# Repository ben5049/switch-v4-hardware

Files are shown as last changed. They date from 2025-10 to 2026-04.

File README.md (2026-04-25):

# Switch v4 Hardware

KiCad design files for the 4th iteration of my single pair Ethernet (SPE) switch. The firmware can be found in [unified-switch-firmware](https://github.com/ben5049/unified-switch-firmware).

Also see my post on [r/embedded](https://www.reddit.com/r/embedded/comments/1mxale6/i_built_a_single_pair_ethernet_switch/)!

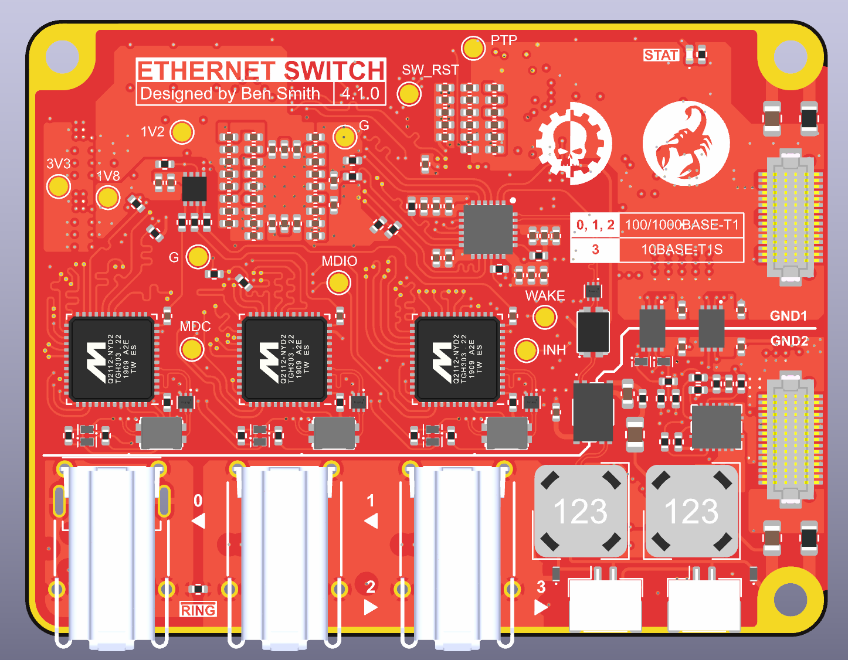
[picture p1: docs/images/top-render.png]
top-render


## Design

See the [schematic](docs/schematics/switch-main-v4.pdf) for a block diagram and in-depth details.

The main switch chip is an [SJA1105QEL](https://www.nxp.com/products/SJA1105PQRS) from NXP. It is configured via SPI by an [STM32H573IIK3Q](https://www.st.com/resource/en/datasheet/stm32h573ai.pdf). The STM32 is also connected by reduced media independent interface (RMII) to the switch so it is able to send and receive management traffic such as Spanning Tree Protocol ([STP](https://en.wikipedia.org/wiki/Spanning_Tree_Protocol)) BPDUs as well as Precision Time Protocol (PTP) packets and diagnostic information.

The connections for each SJA1105 port are shown below:

| Port | Speed (Mbps) | Description |
| ---- | --- | --- |
| 0 | 100/1000 | Marvell 88Q2112 100/1000BASE-T1 Ethernet PHY |
| 1 | 100/1000 | Marvell 88Q2112 100/1000BASE-T1 Ethernet PHY with PoDL |
| 2 | 100/1000 | Marvell 88Q2112 100/1000BASE-T1 Ethernet PHY with PoDL |
| 3 | 10 | Microchip LAN8671 10BASE-T1S Ethernet PHY with PoDL |
| 4 | 100 | Internal STM32 management processor |

### PoDL PSE

Power over Datalines ([PoDL](https://en.wikipedia.org/wiki/Power_over_Ethernet#PoDL)) is similar to Power over Ethernet ([PoE](https://en.wikipedia.org/wiki/Power_over_Ethernet)) but for SPE. In regular PoE power is sent over the center taps of the transformers, however in SPE there is only one (or no) transformer so this wouldn't work. Instead, DC power is injected into the datalines in the Coupling Decoupling Network (CDN) using differential mode inductors (DMI). The switch is only capable of being a Power Sourcing Equipment (PSE) which powers other devices. It must get its own power through the other connectors on the board.

PoDL has been implemented on ports 1, 2 and 3 of the switch.

- Ports 1 and 2 are able to output 1.1A each and use a simple detection method before supplying power to a load. Firstly ~14mA is sent down the cable, then if the bus voltage is between 4.05 and 4.55V then the full supply is enabled (typically 24V). This is usually done by a zener diode on the other end of the cable.

- Port 3 is also able to output 1.1A and uses a custom multidrop PoDL implementation. Detection is done by powering the bus at 6.5V, then each device on the bus draws 1mA for every 1W of power they want. Then the full supply is enabled.

An [STM32H503KBU6](https://www.st.com/resource/en/datasheet/stm32h503eb.pdf) is used as a secondary processor to control the PoDL operations. It talks to the primary processor via UART through an optocoupler. This means the data and power circuits are galvanically isolated.

## Test Rig

The [test rig PCB](pcbs/switch-main-v4-test-rig) is designed so that its pogo pins align directly with the test pads on the bottom of the main switch board. This means a debugger can be connected without needing to include a header on the main board.

## Versions

| Version | Description |
| --- | --- |
| v4.1.1  | Updated to Kicad v10 |
| v4.1.0  | Fixed bugs from first revision |
| v4.0.0  | First release |

See the [errata](docs/errata.md) for details on bugs.

## References

Datasheets:
- [88Q2112 Datasheet](https://www.infineon.com/assets/row/public/documents/10/49/infineon-brightlane-88q2110-88q2112-datasheet-datasheet-en.pdf) (requires an Infineon account)
- [SJA1105 Datasheet](https://www.nxp.com/docs/en/data-sheet/SJA1105PQRS.pdf)
- [LAN8671 Datasheet](https://ww1.microchip.com/downloads/aemDocuments/documents/AIS/ProductDocuments/DataSheets/LAN8670-1-2-Data-Sheet-60001573.pdf)

PoDL:
- [How to Implement an IEEE 802.3cg or 802.3bu-Compliant PoDL PSE](https://www.ti.com/lit/ab/snla395/snla395.pdf?ts=1745823061950) - TI
- [1000BASE-T1 PoDL Reference design](https://www.ti.com/lit/ug/tiduf49/tiduf49.pdf?ts=1746159399261&ref_url=https%253A%252F%252Fwww.google.com%252F) - TI
- [PSE Schematic](https://www.ti.com/lit/df/tidmco4/tidmco4.pdf?ts=1746307249429) - TI
- [IEEE 802.3cg 10BASE-T1L Power over Data Lines Powered Device Design](https://www.ti.com/lit/an/snvaa25a/snvaa25a.pdf?ts=1745871367852) - TI
    - References non-existent inductors :/
- [SINGLE PAIR ETHERNET FILTER DESIGN](https://www.we-online.com/files/pdf1/single_pair_ethernet.pdf) - WE
- [Power Injection Inductors for 10BASE-T1 PoDL](https://www.coilcraft.com/en-us/applications/power-injection-inductors-for-10base-t1-podl/) - Coilcraft
- [10BASE-T1L Converter w/ PoE+PoDL](https://matthewtran.dev/2024/08/10base-t1l-converter/)

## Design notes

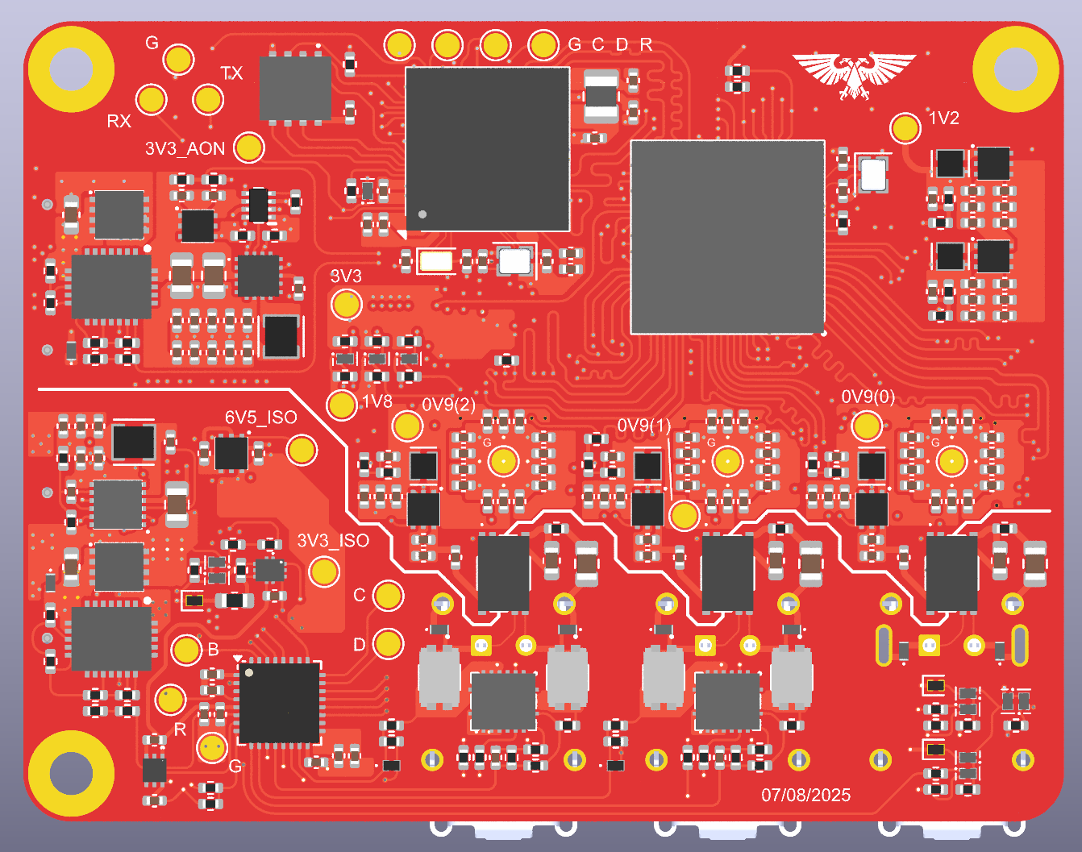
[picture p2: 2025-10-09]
docs/images/bottom-render.png

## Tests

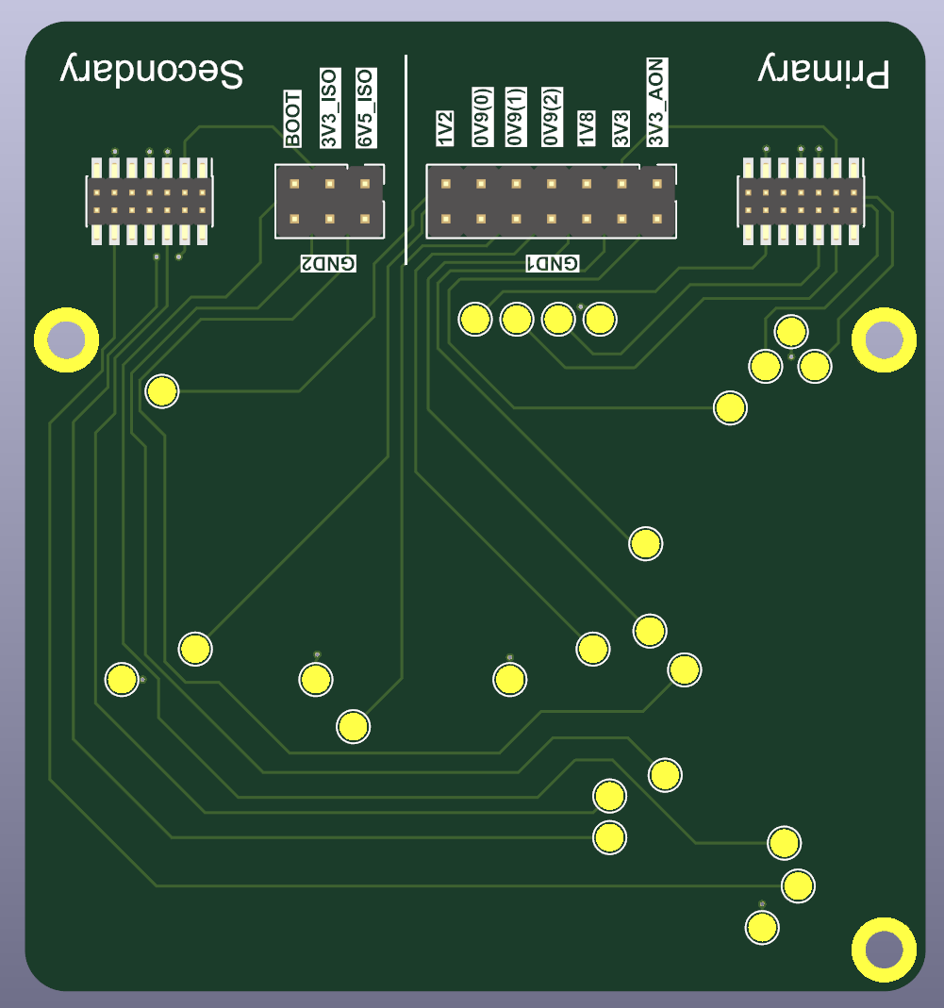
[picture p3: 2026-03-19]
docs/images/test-rig.png

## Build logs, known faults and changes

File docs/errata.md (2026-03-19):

# Switch v4 Errata

## Contents

- [1 Switch v4](#1-switch-v4)
    - [1.1 Primary MCU RMII lanes swapped](#11-primary-mcu-rmii-lanes-swapped)
    - [1.2 88Q2112 Incorrect strapping resistors](#12-88q2112-incorrect-strapping-resistors)

## Key

- A = limitation present, workaround available
- N = limitation present, no workaround available
- P = limitation present, partial workaround available
- "-" = limitation absent

## 1 Switch v4

| **Bug** | **4.0.0** | **4.1.0** |
|---|---|---|
| [Primary MCU RMII lanes swapped](#11-primary-mcu-rmii-lanes-swapped) | A | - |
| [88Q2112 Incorrect strapping resistors](#12-88q2112-incorrect-strapping-resistors) | A | - |

### 1.1 Primary MCU RMII lanes swapped

The primary MCU's RMII TX and RX lanes were accidentally swapped meaning no data could be transmitted or received. This can be fixed by cutting the traces and resoldering them as shown below:

rmii-lane-swap

### 1.2 88Q2112 Incorrect strapping resistors

The 88Q2112 PHYs are missing strapping resistors to put them into RGMII mode and so by default they are in SGMII mode. This can be fixed by adding 4.7k ohm resistores between the PHY's RXC pin and GND. This can be done using the untented vias as shown below:

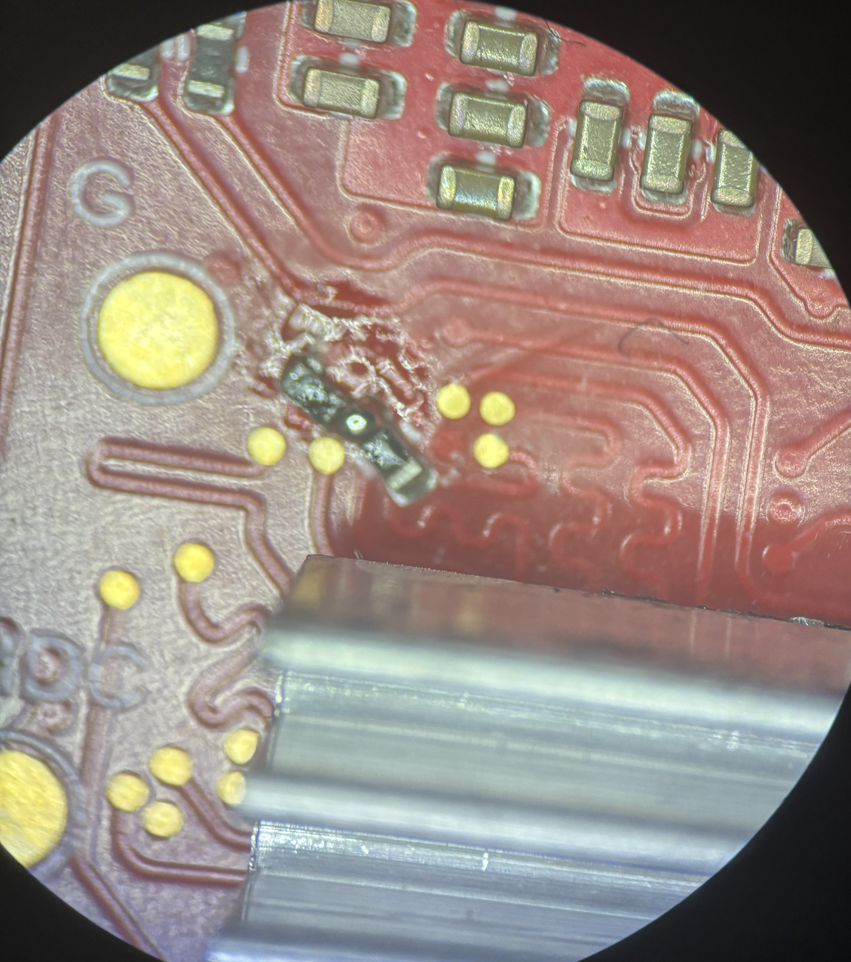
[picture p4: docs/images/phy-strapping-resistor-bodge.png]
phy-strapping-resistor-bodge


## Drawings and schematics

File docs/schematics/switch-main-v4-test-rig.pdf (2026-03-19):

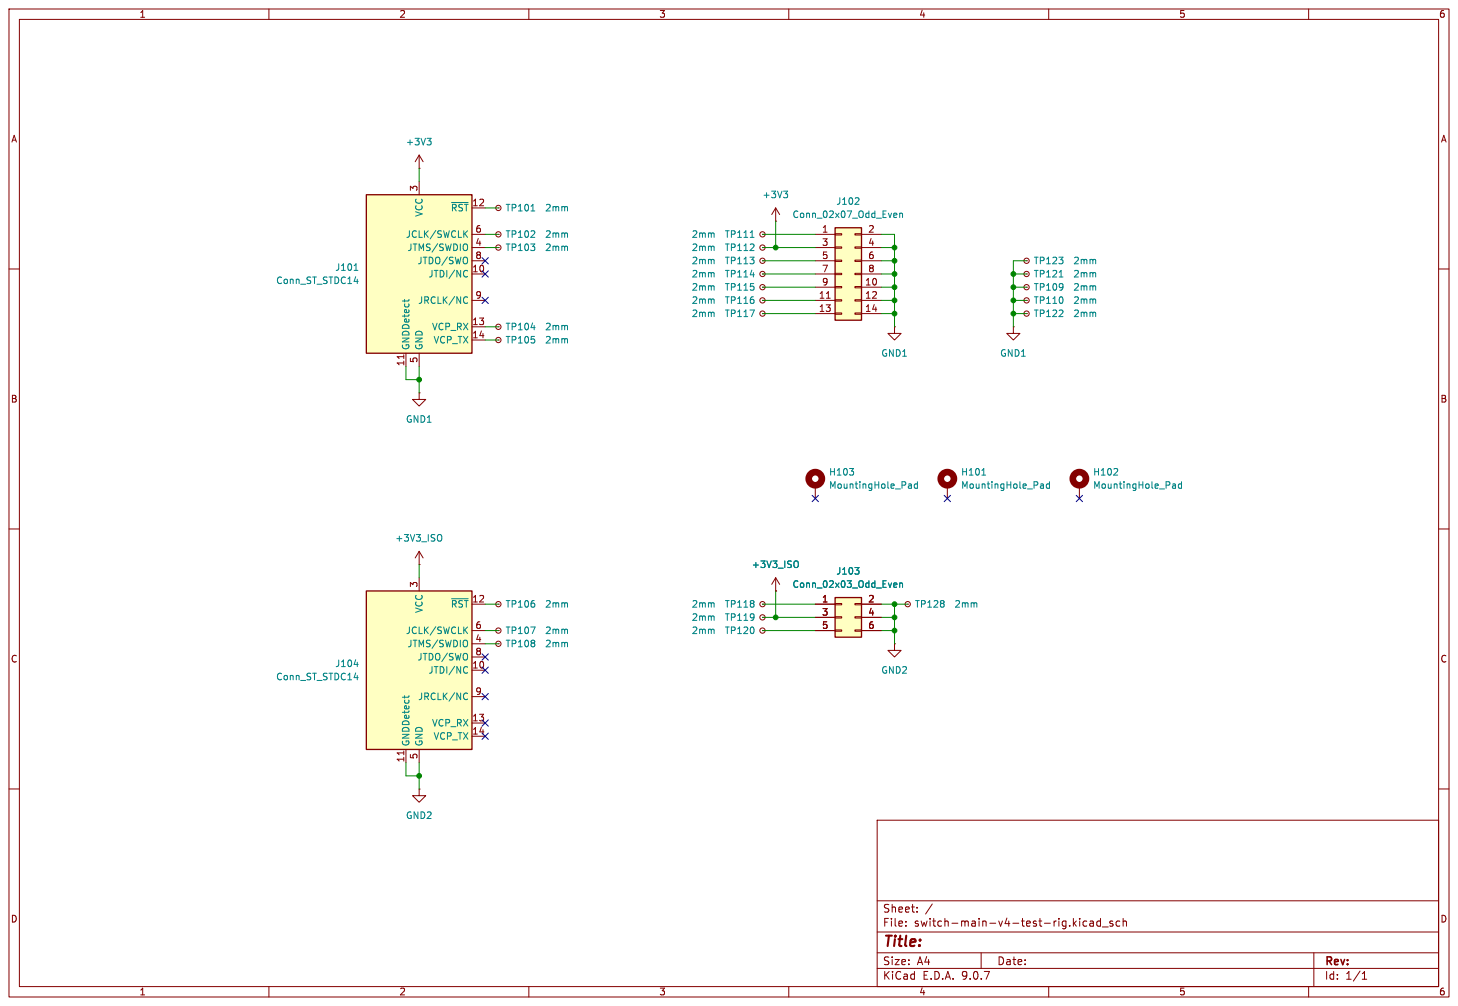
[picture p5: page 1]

Id: 1/1 Title: File: switch-main-v4-test-rig.kicad_sch Sheet: /

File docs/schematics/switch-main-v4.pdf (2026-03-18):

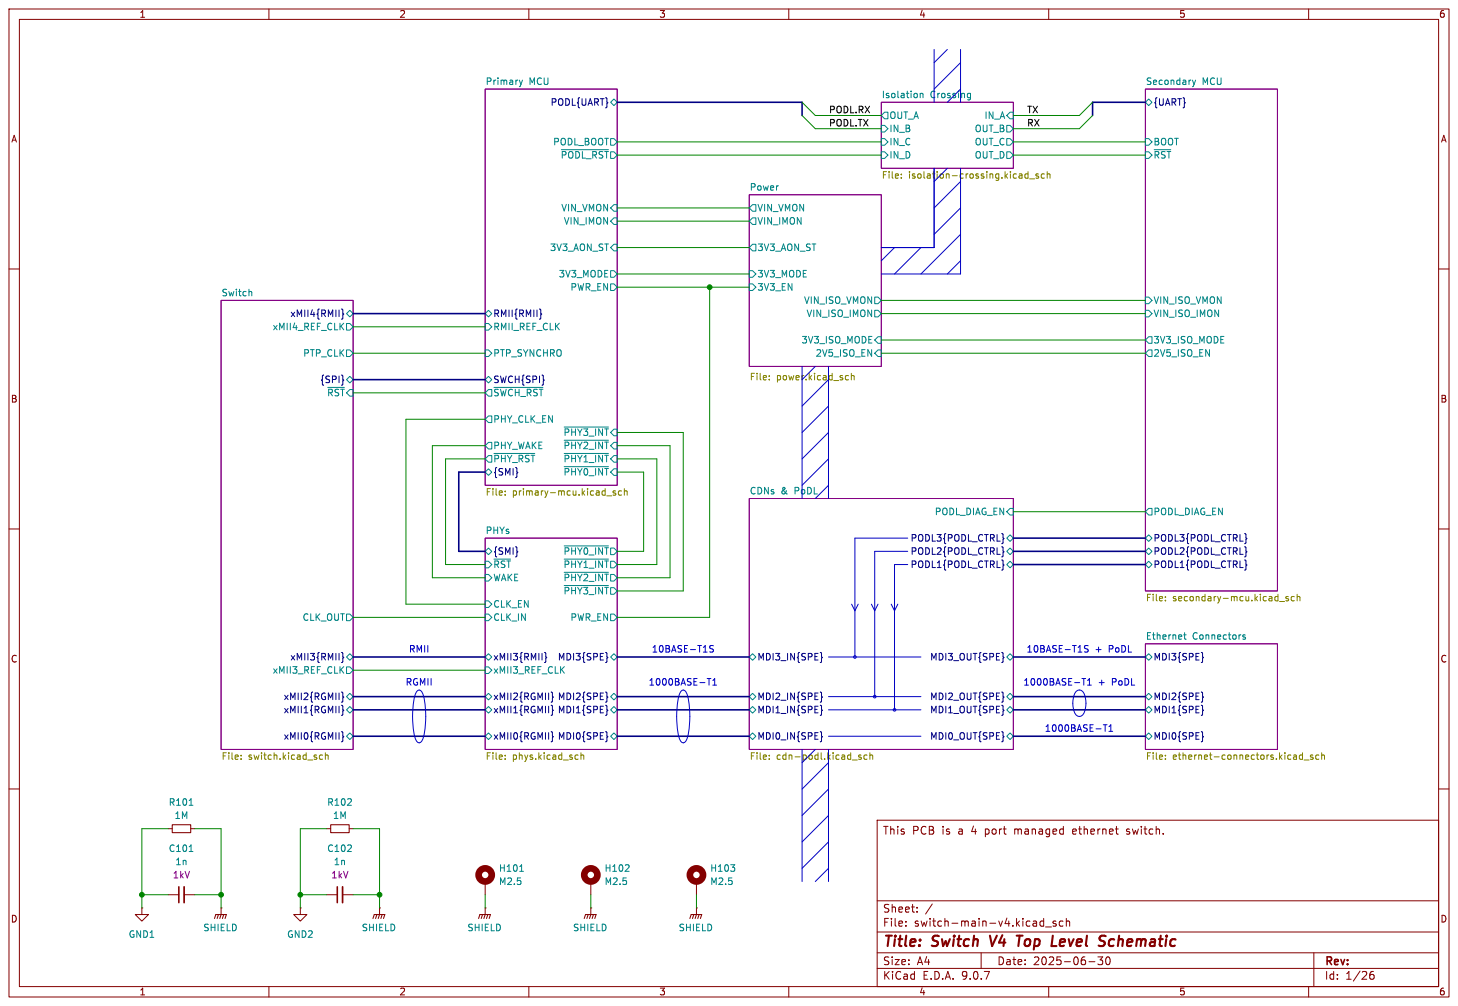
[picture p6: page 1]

MDI3{SPE} Ethernet Connectors File: ethernet-connectors.kicad_sch

Id: 1/26 Title: Switch V4 Top Level Schematic

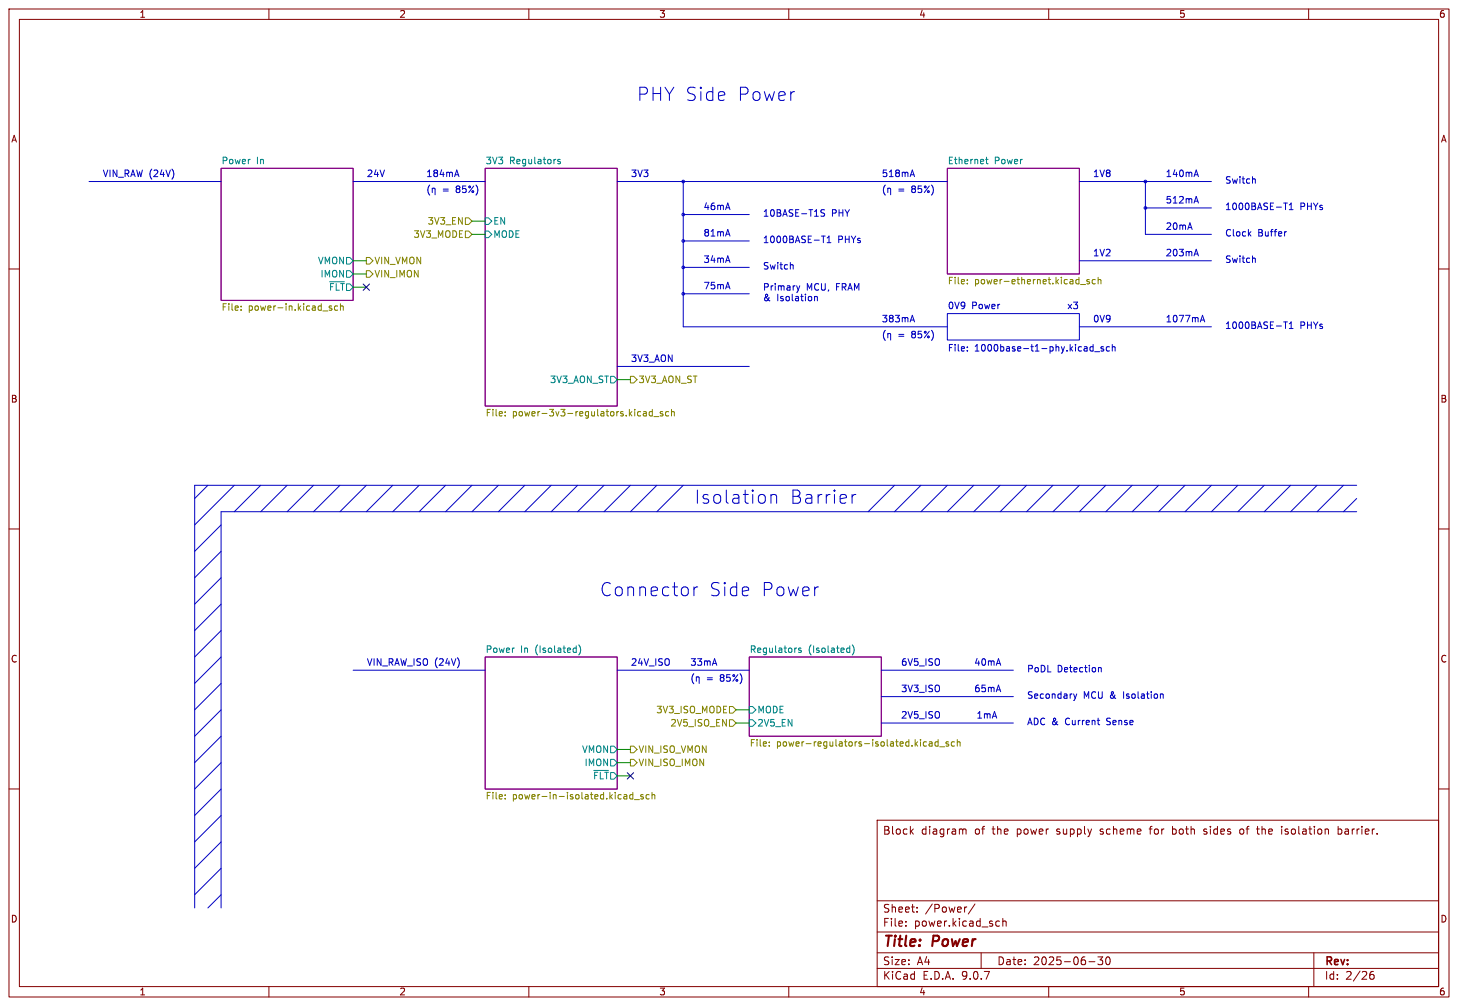
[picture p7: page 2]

Power In File: power-in.kicad_sch

3V3 Regulators File: power-3v3-regulators.kicad_sch

Ethernet Power File: power-ethernet.kicad_sch

Switch Primary MCU, FRAM

Power In (Isolated) File: power-in-isolated.kicad_sch

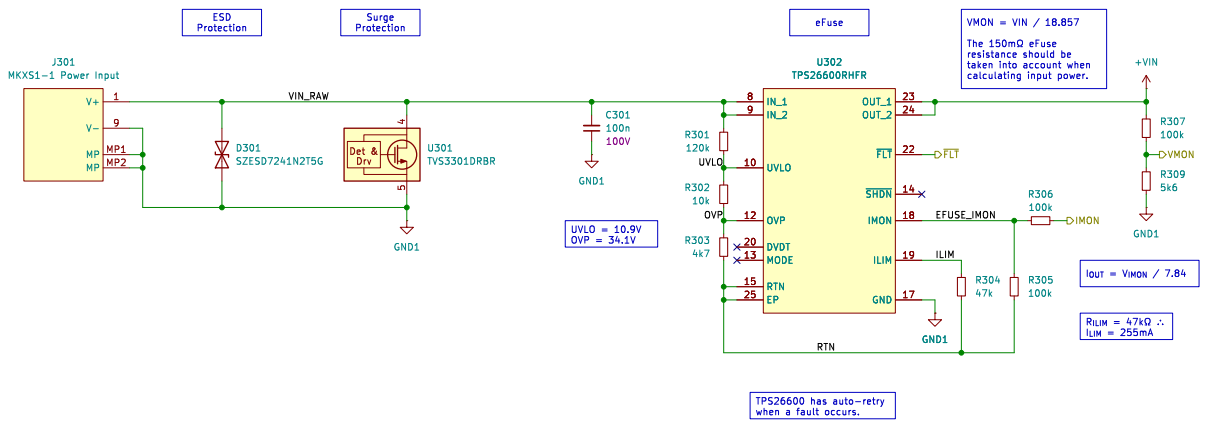
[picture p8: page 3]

taken into account when

TPS26600 has auto-retry when a fault occurs. UVLO = 10.9V OVP = 34.1V

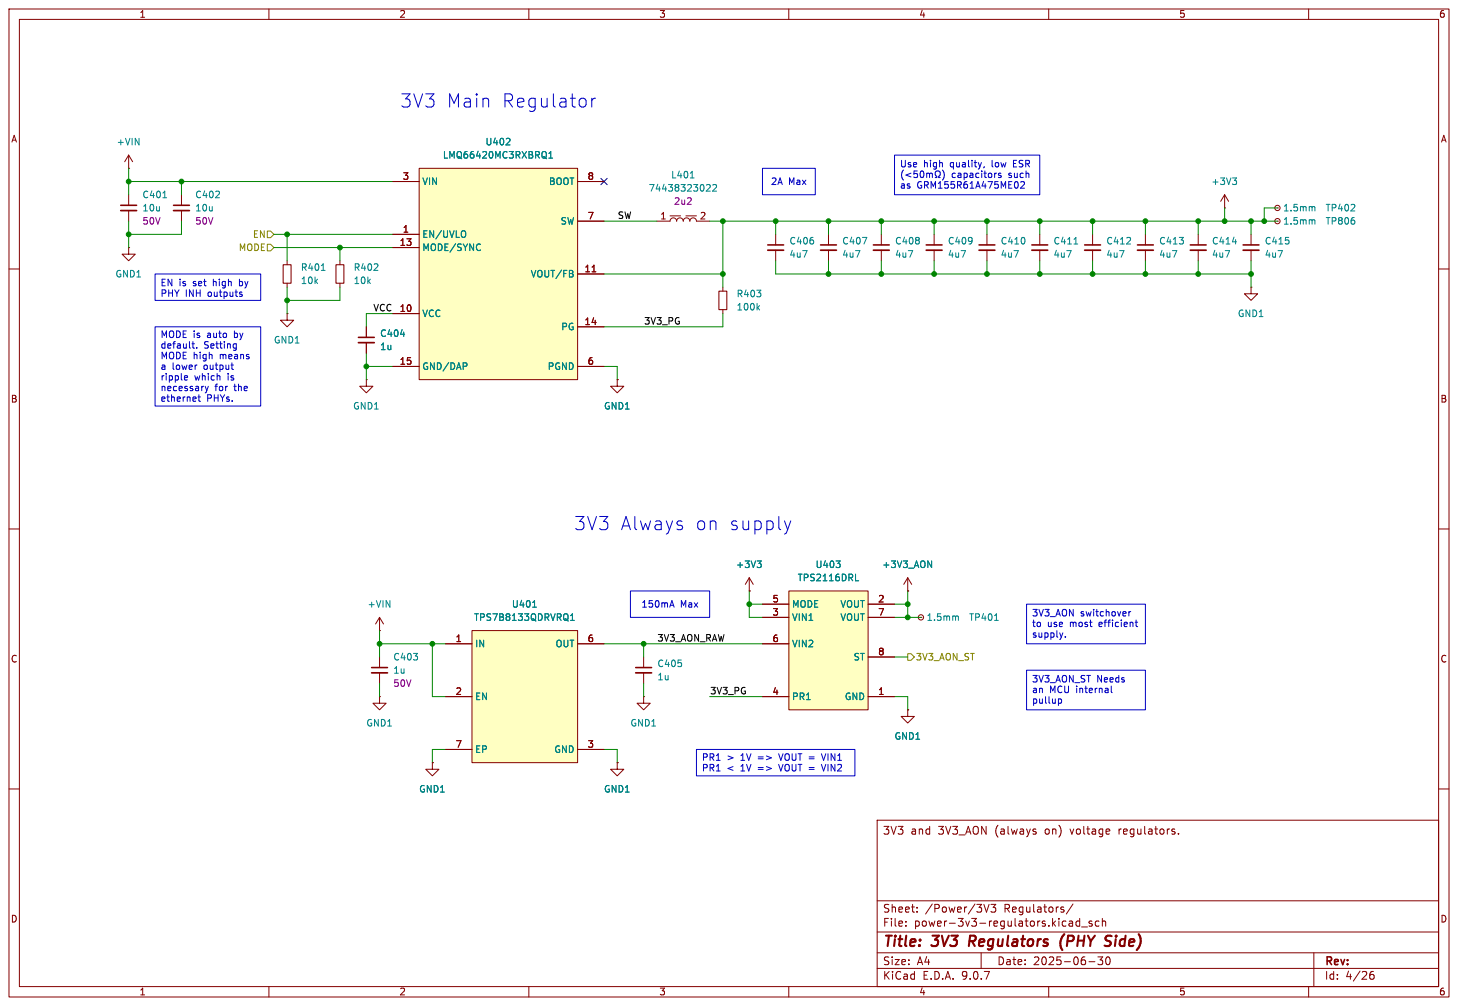
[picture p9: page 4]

to use most efficient supply.

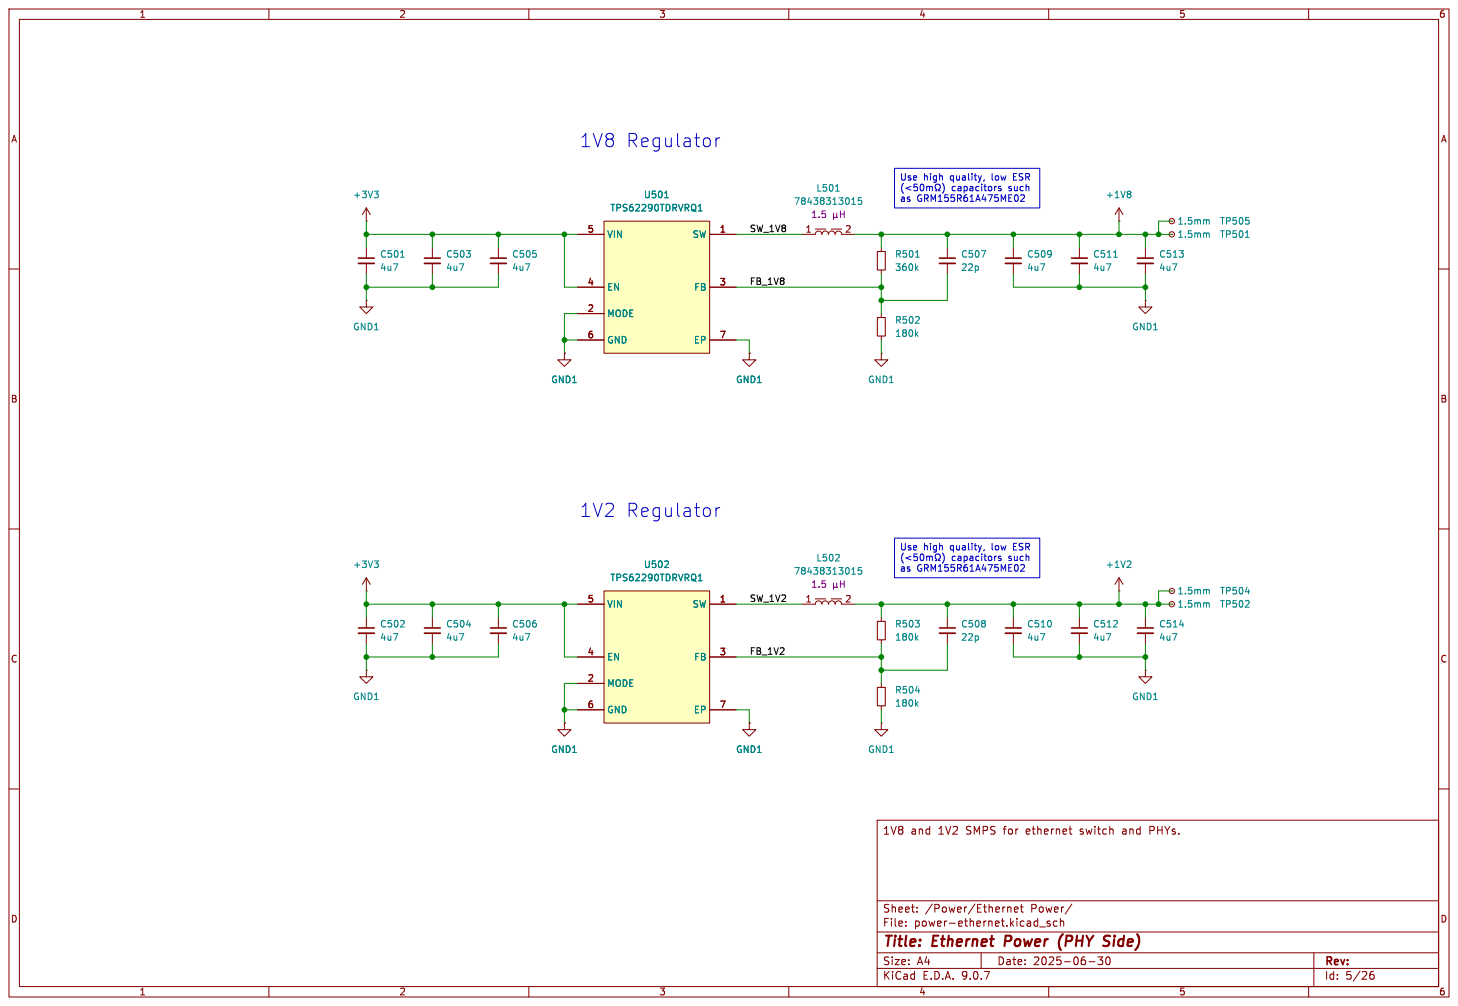
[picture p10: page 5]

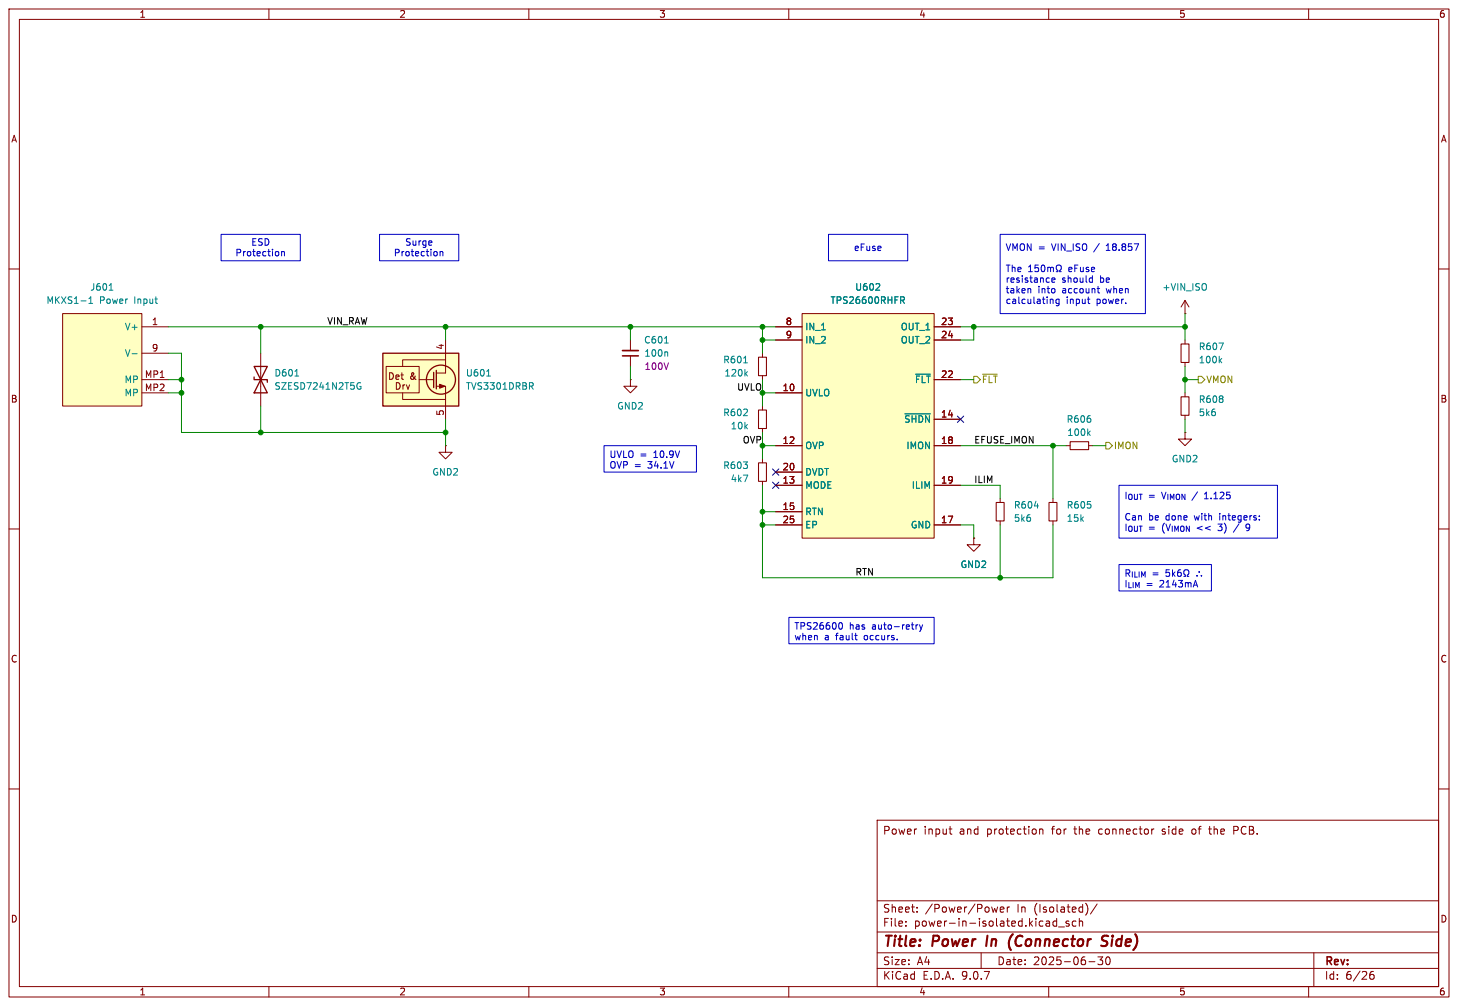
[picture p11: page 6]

eFuse Surge Protection ESD

taken into account when

I_{OUT} = V_{IMON} / 1.125 Can be done with integers:

[6.25V ... 6.66V] SYNC (MODE): - HIGH = FPWM (low ripple)

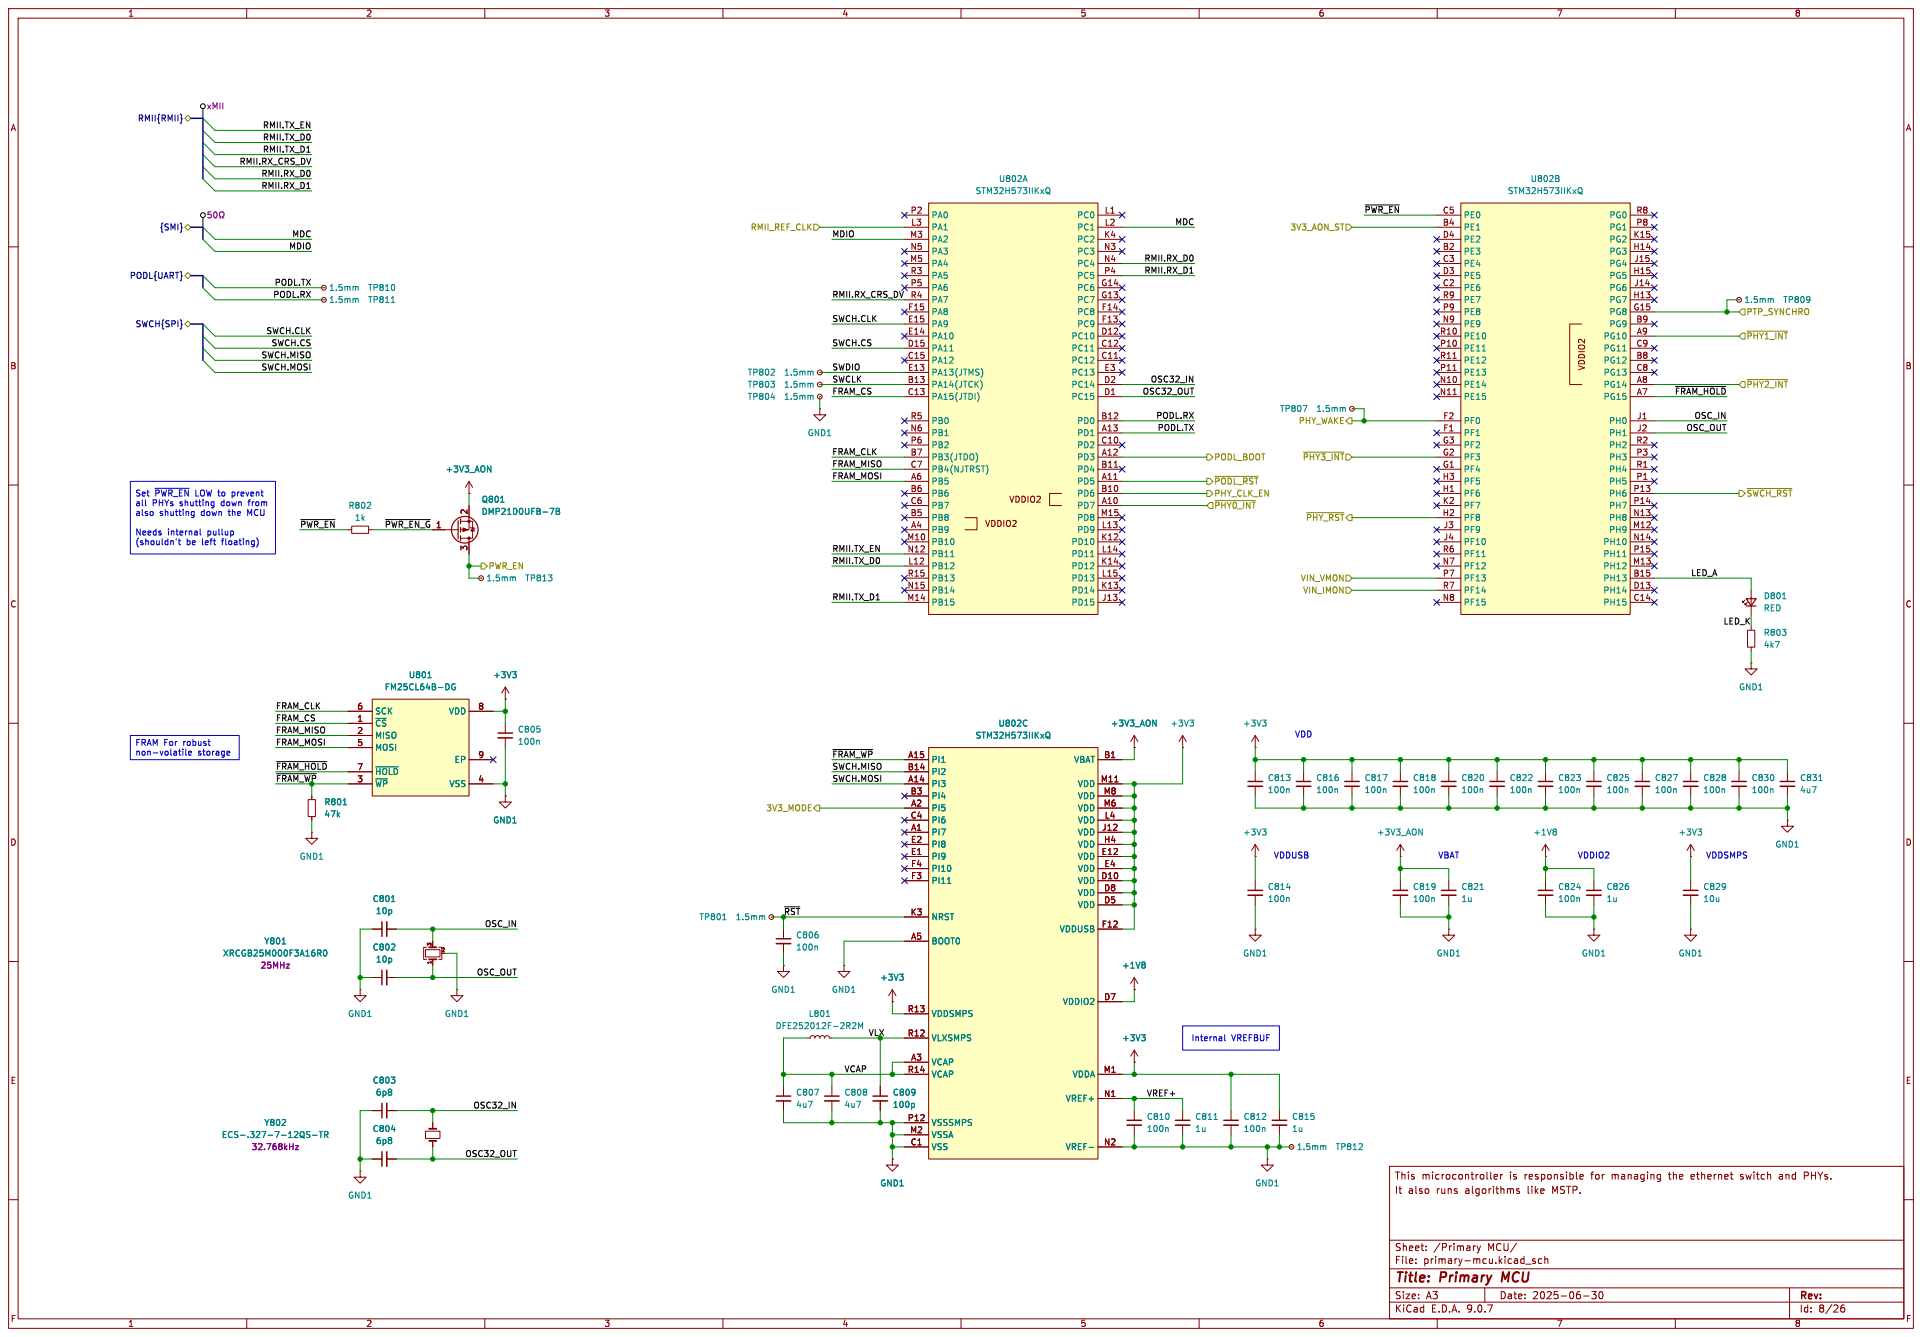
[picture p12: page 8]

SWCH.CLK RMII.RX_CRS_DV RMII.RX_D0

Id: 8/26 Title: Primary MCU

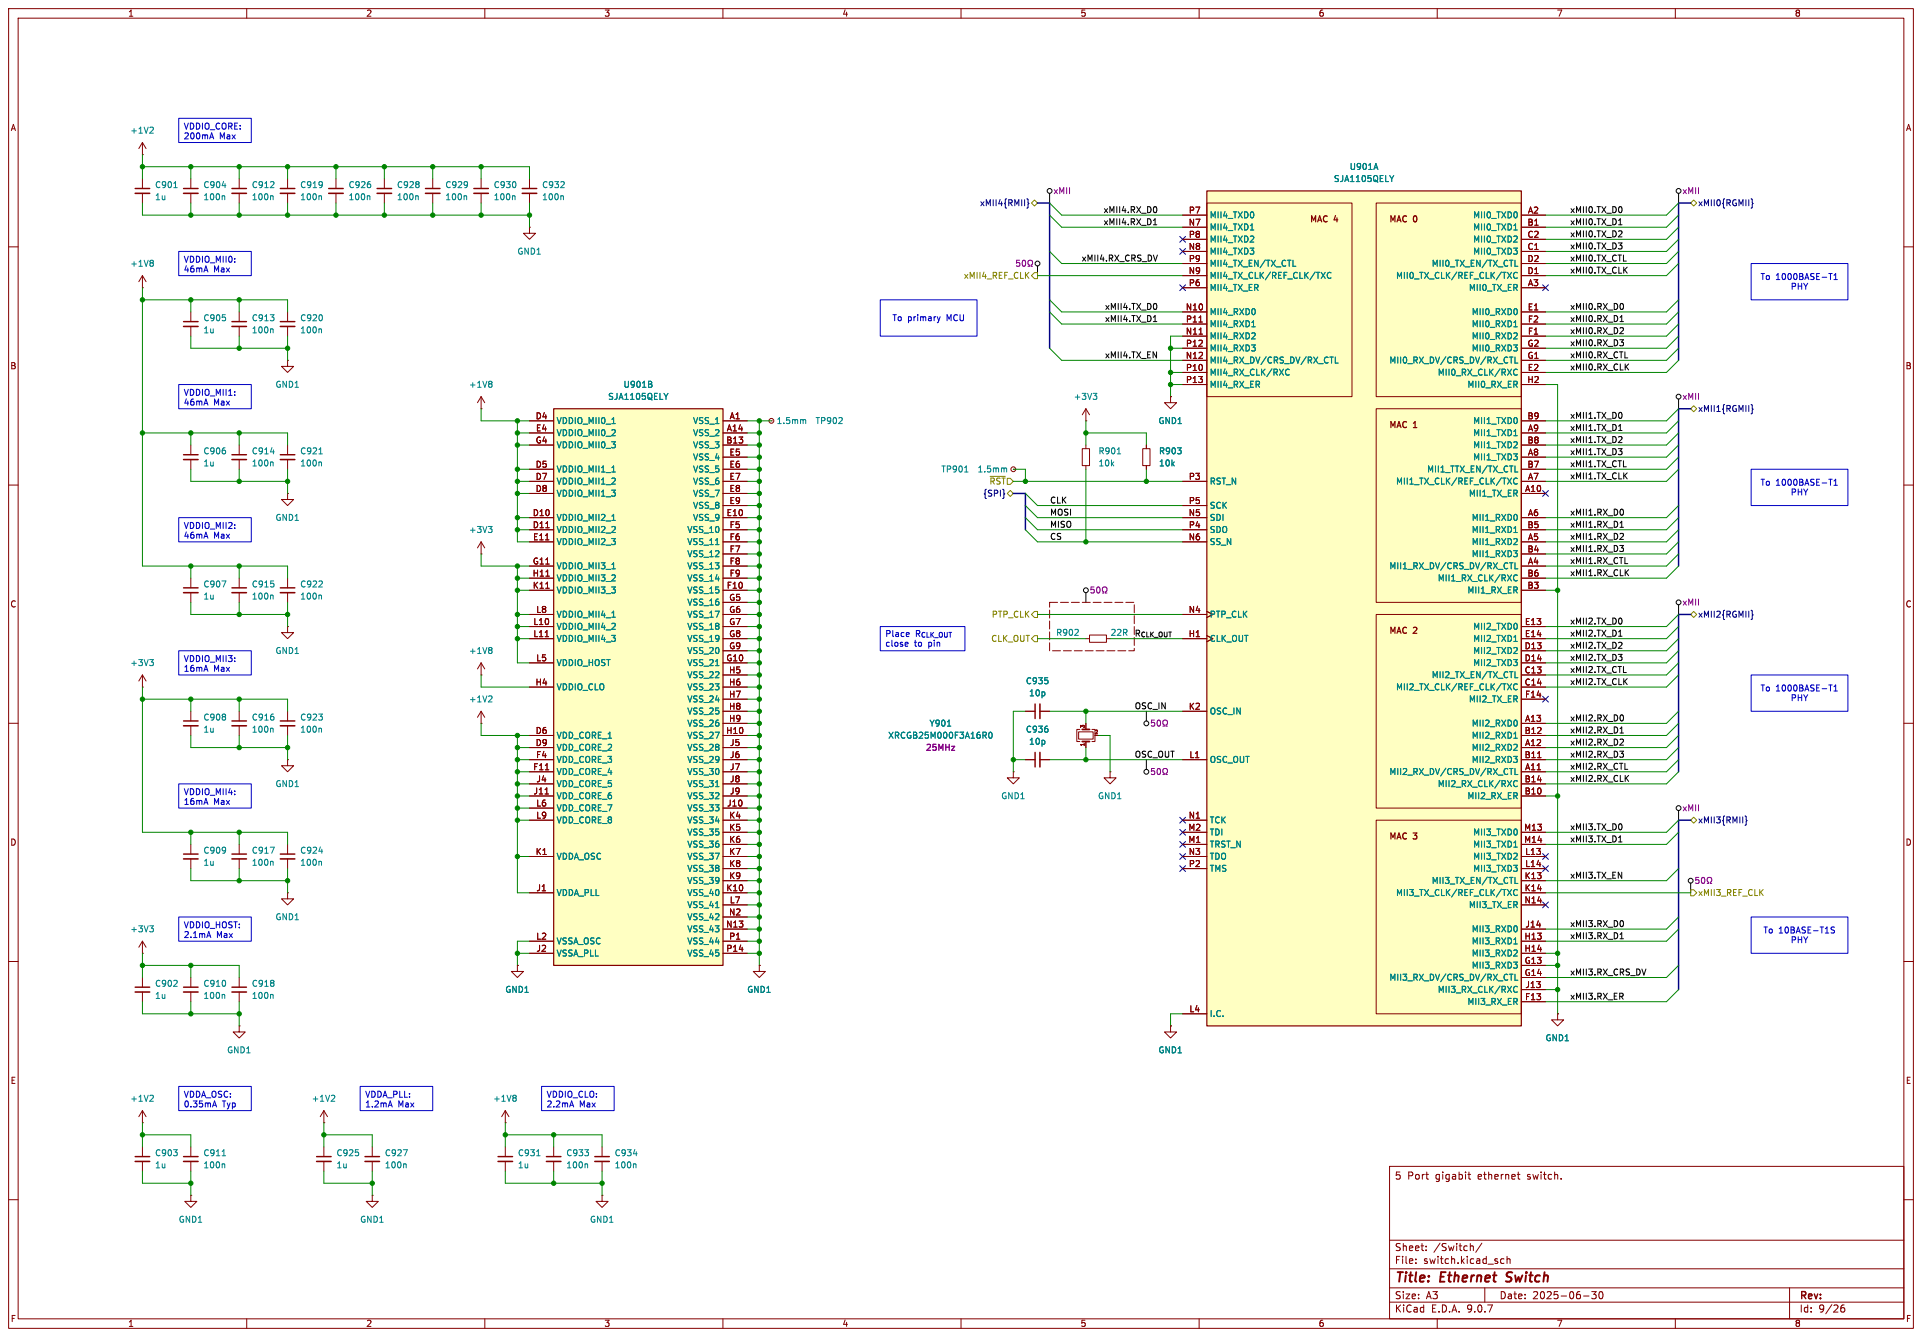
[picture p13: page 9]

File: switch.kicad_sch Sheet: /Switch/ 5 Port gigabit ethernet switch.

Id: 9/26 Title: Ethernet Switch

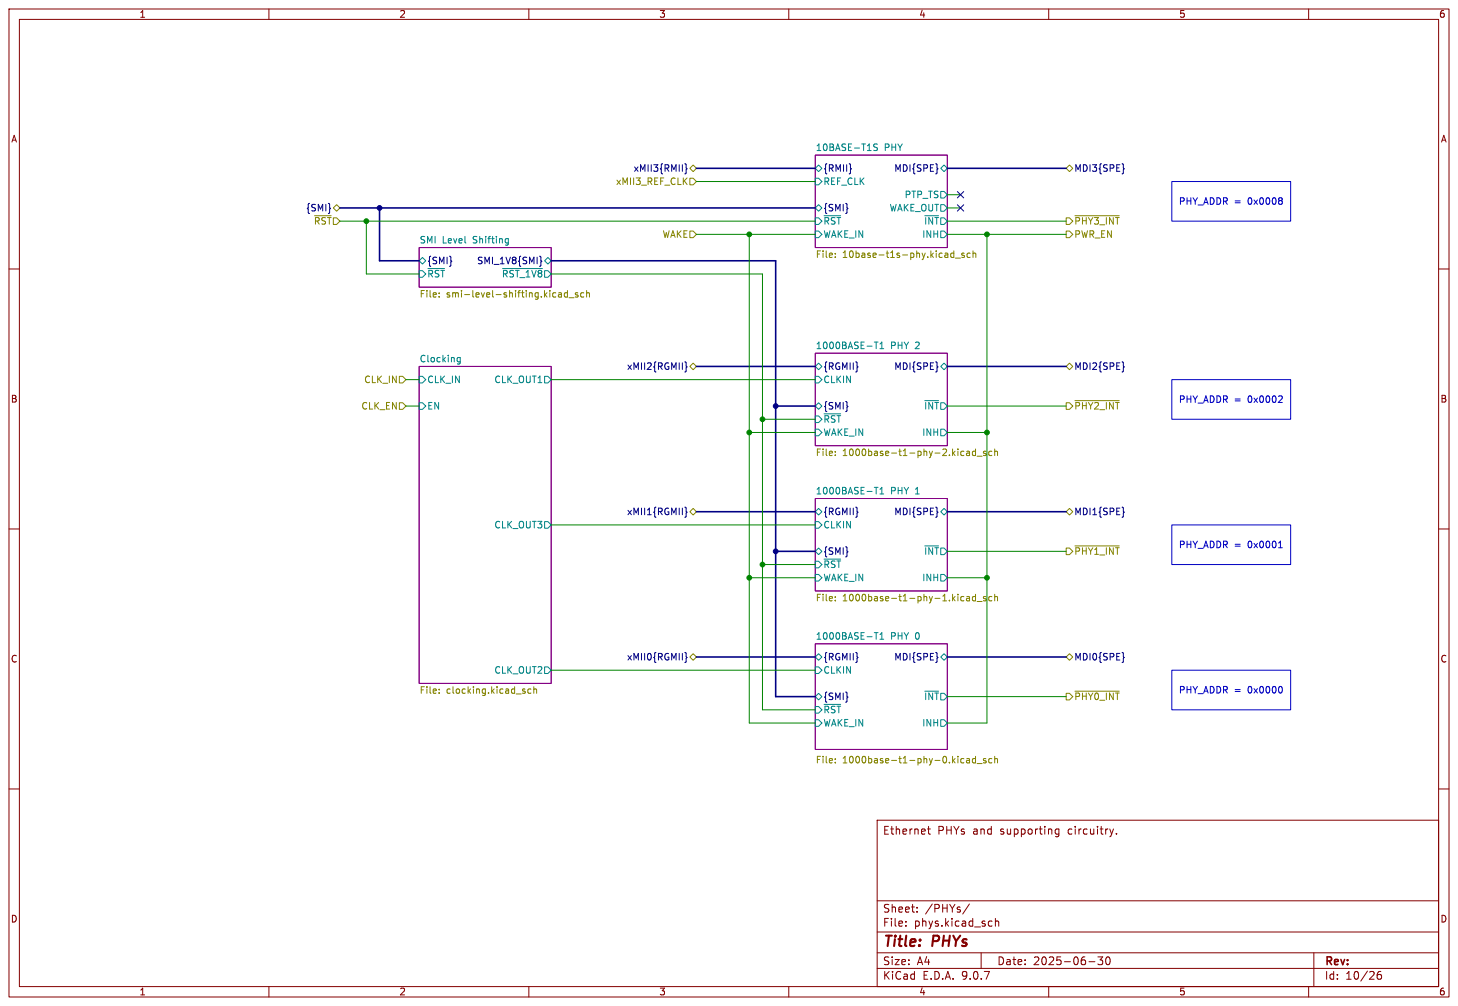
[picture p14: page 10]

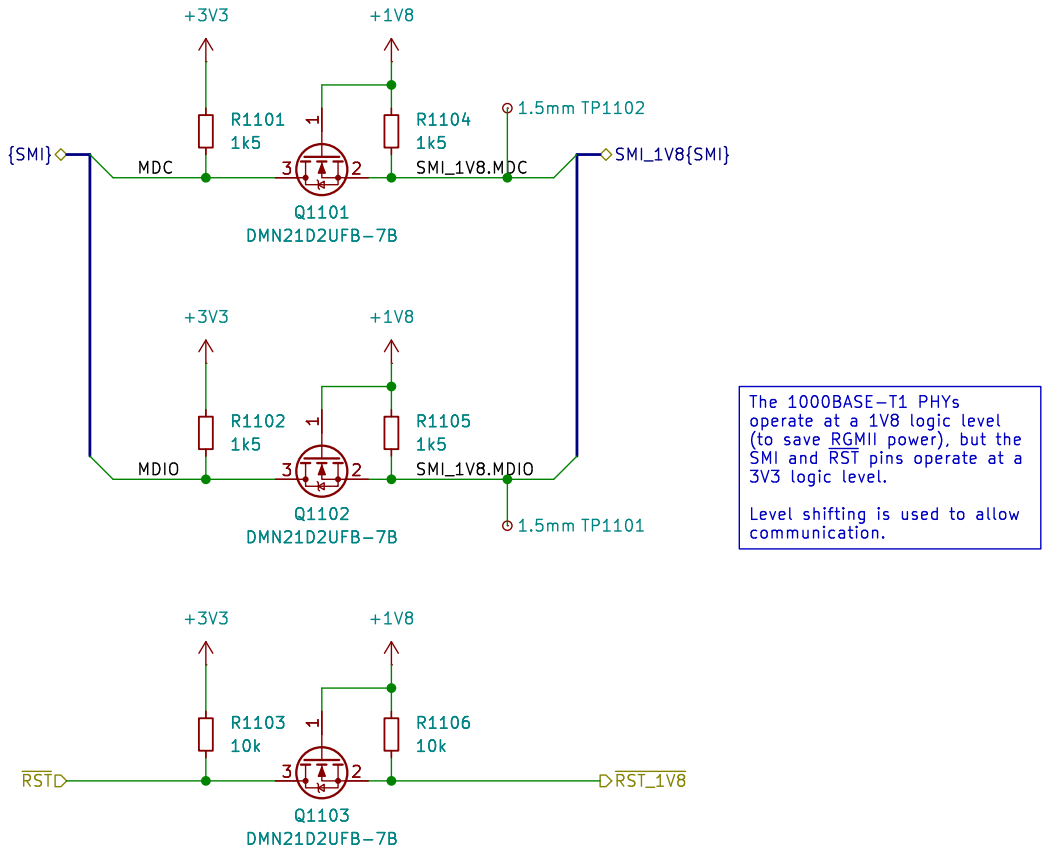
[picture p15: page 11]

Id: 11/26 Title: SMI Level Shifting

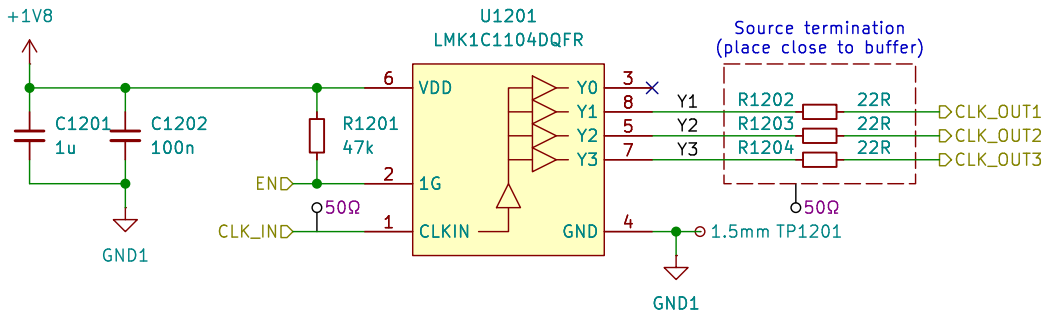
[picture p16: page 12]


MODE[1:0] = 0x00 means
the PHY will start as a


peak to peak AVDD33: 25mA Typ

0V9 MDI.TRXP MODE[1:0] = 0x00 means

359mA Max VDDO: 18.6mA Typ RSET Must be 1%

the PHY will start as a

pullups needed for ~{INT}.


27mA Max VDDO: 18.6mA Typ RSET Must be 1%

the PHY will start as a


Id: 17/26 Title: CDNs and PoDL



720mA Max Can also use


720mA Max Can also use



If the output is shorted
the current is still limited

Each channel can be enabled
devices. Since the outputs share
a current source, only one
channel can be checked at a
time.

1.1A Maximum output current 1.1A Maximum measurable

Id: 22/26 Title: PoDL Detection, Switching and Monitoring


voltage drop across the 1

IMON can go up to

Id: 23/26 Title: MPoE Detection, Switching and Monitoring


J2405 MSPE-J2L0-x00 MDI MDI MDI MDI MDI3{SPE}

in ring topology
to prevent loop in

Id: 24/26 Title: Ethernet Connectors


Id: 25/26 Title: Isolation Crossing


Invert BOOT so it is LOW

Id: 26/26 Title: Secondary MCU

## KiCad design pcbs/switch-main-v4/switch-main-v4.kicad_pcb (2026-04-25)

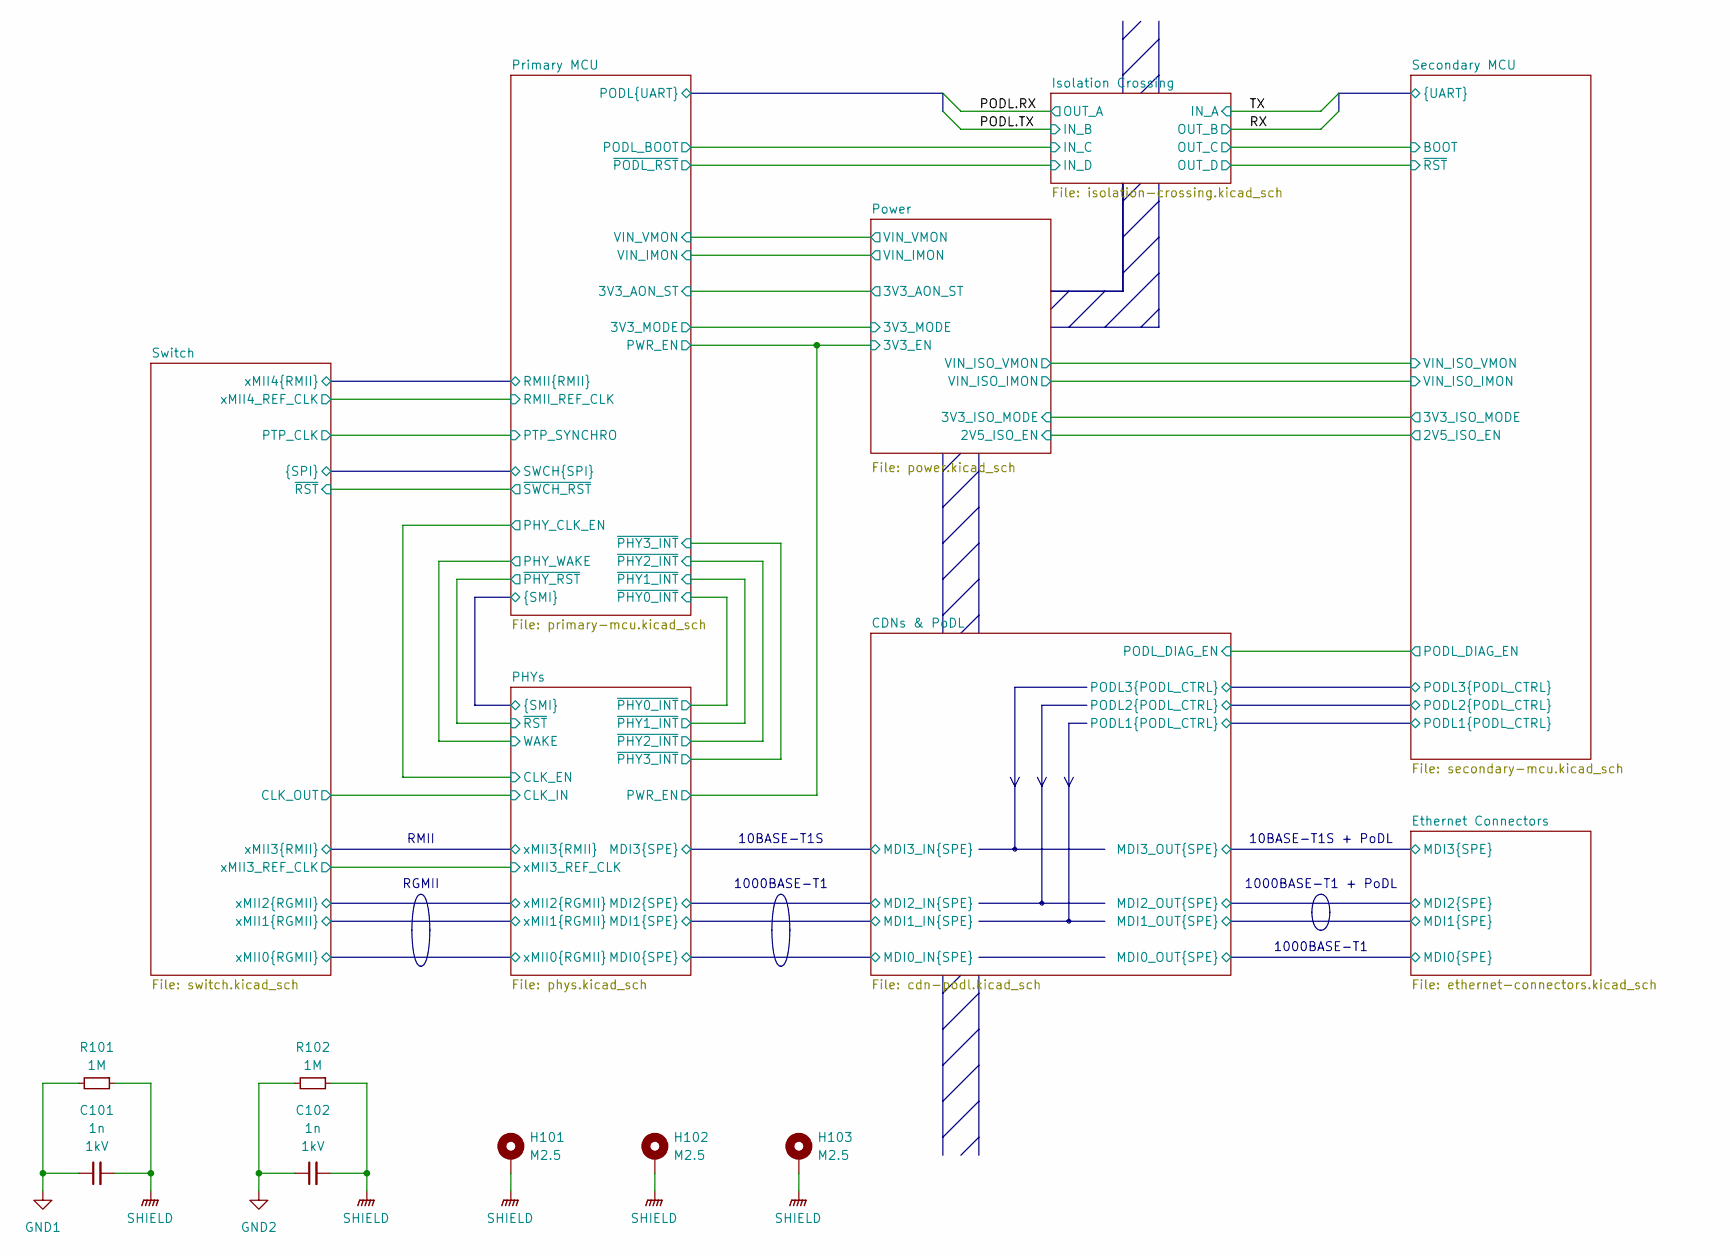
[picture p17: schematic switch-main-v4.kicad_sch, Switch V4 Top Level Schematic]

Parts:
C101, C102: 1n; C_0805; Voltage 1kV
H101, H102, H103: M2.5; MountingHole_2.7mm_M2.5_Pad
R101, R102: 1M; R_0805

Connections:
GND1: C101.1, R101.2; also elsewhere on the board
GND2: C102.1, R102.2; also elsewhere on the board
SHIELD: C101.2, C102.2, H101.1 (1_1), H102.1 (1_1), H103.1 (1_1), R101.1, R102.1; also elsewhere on the board

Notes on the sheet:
RGMII
RMII
10BASE-T1S
1000BASE-T1
1000BASE-T1 + PoDL
10BASE-T1S + PoDL

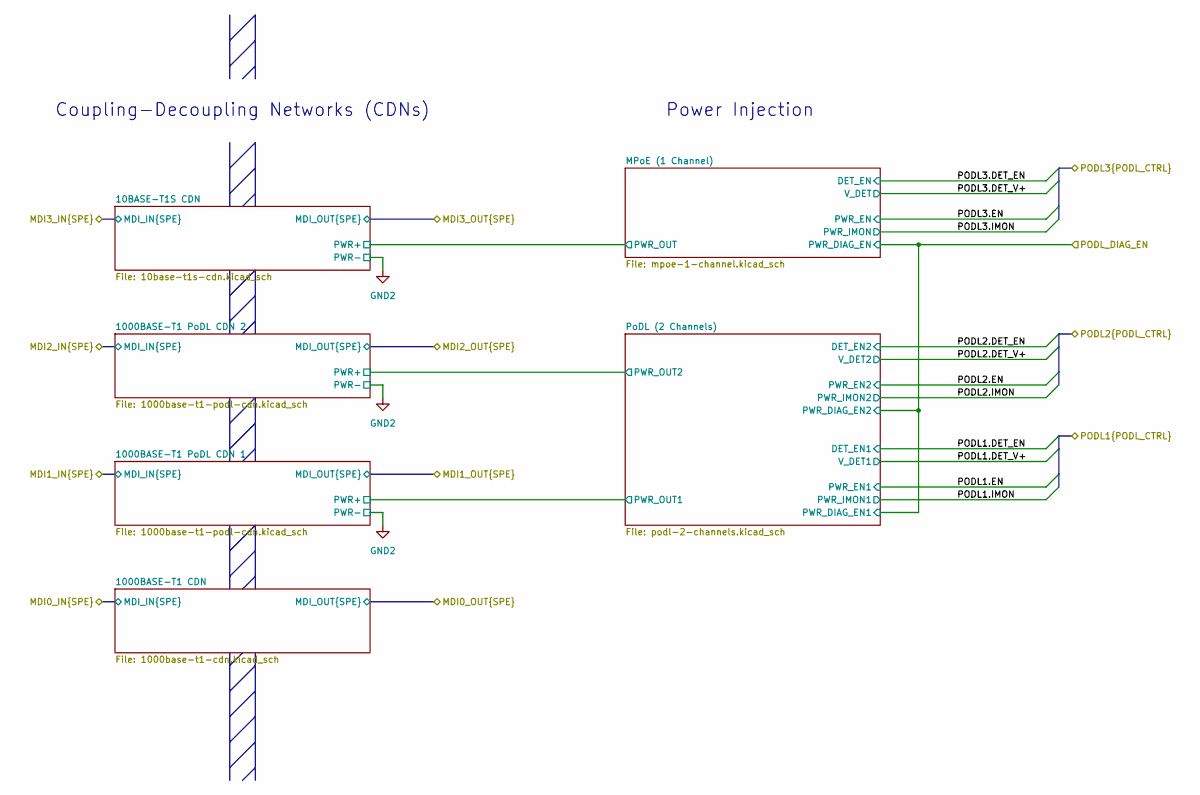
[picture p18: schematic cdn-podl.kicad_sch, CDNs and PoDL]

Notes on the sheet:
Power Injection
Coupling-Decoupling Networks (CDNs)

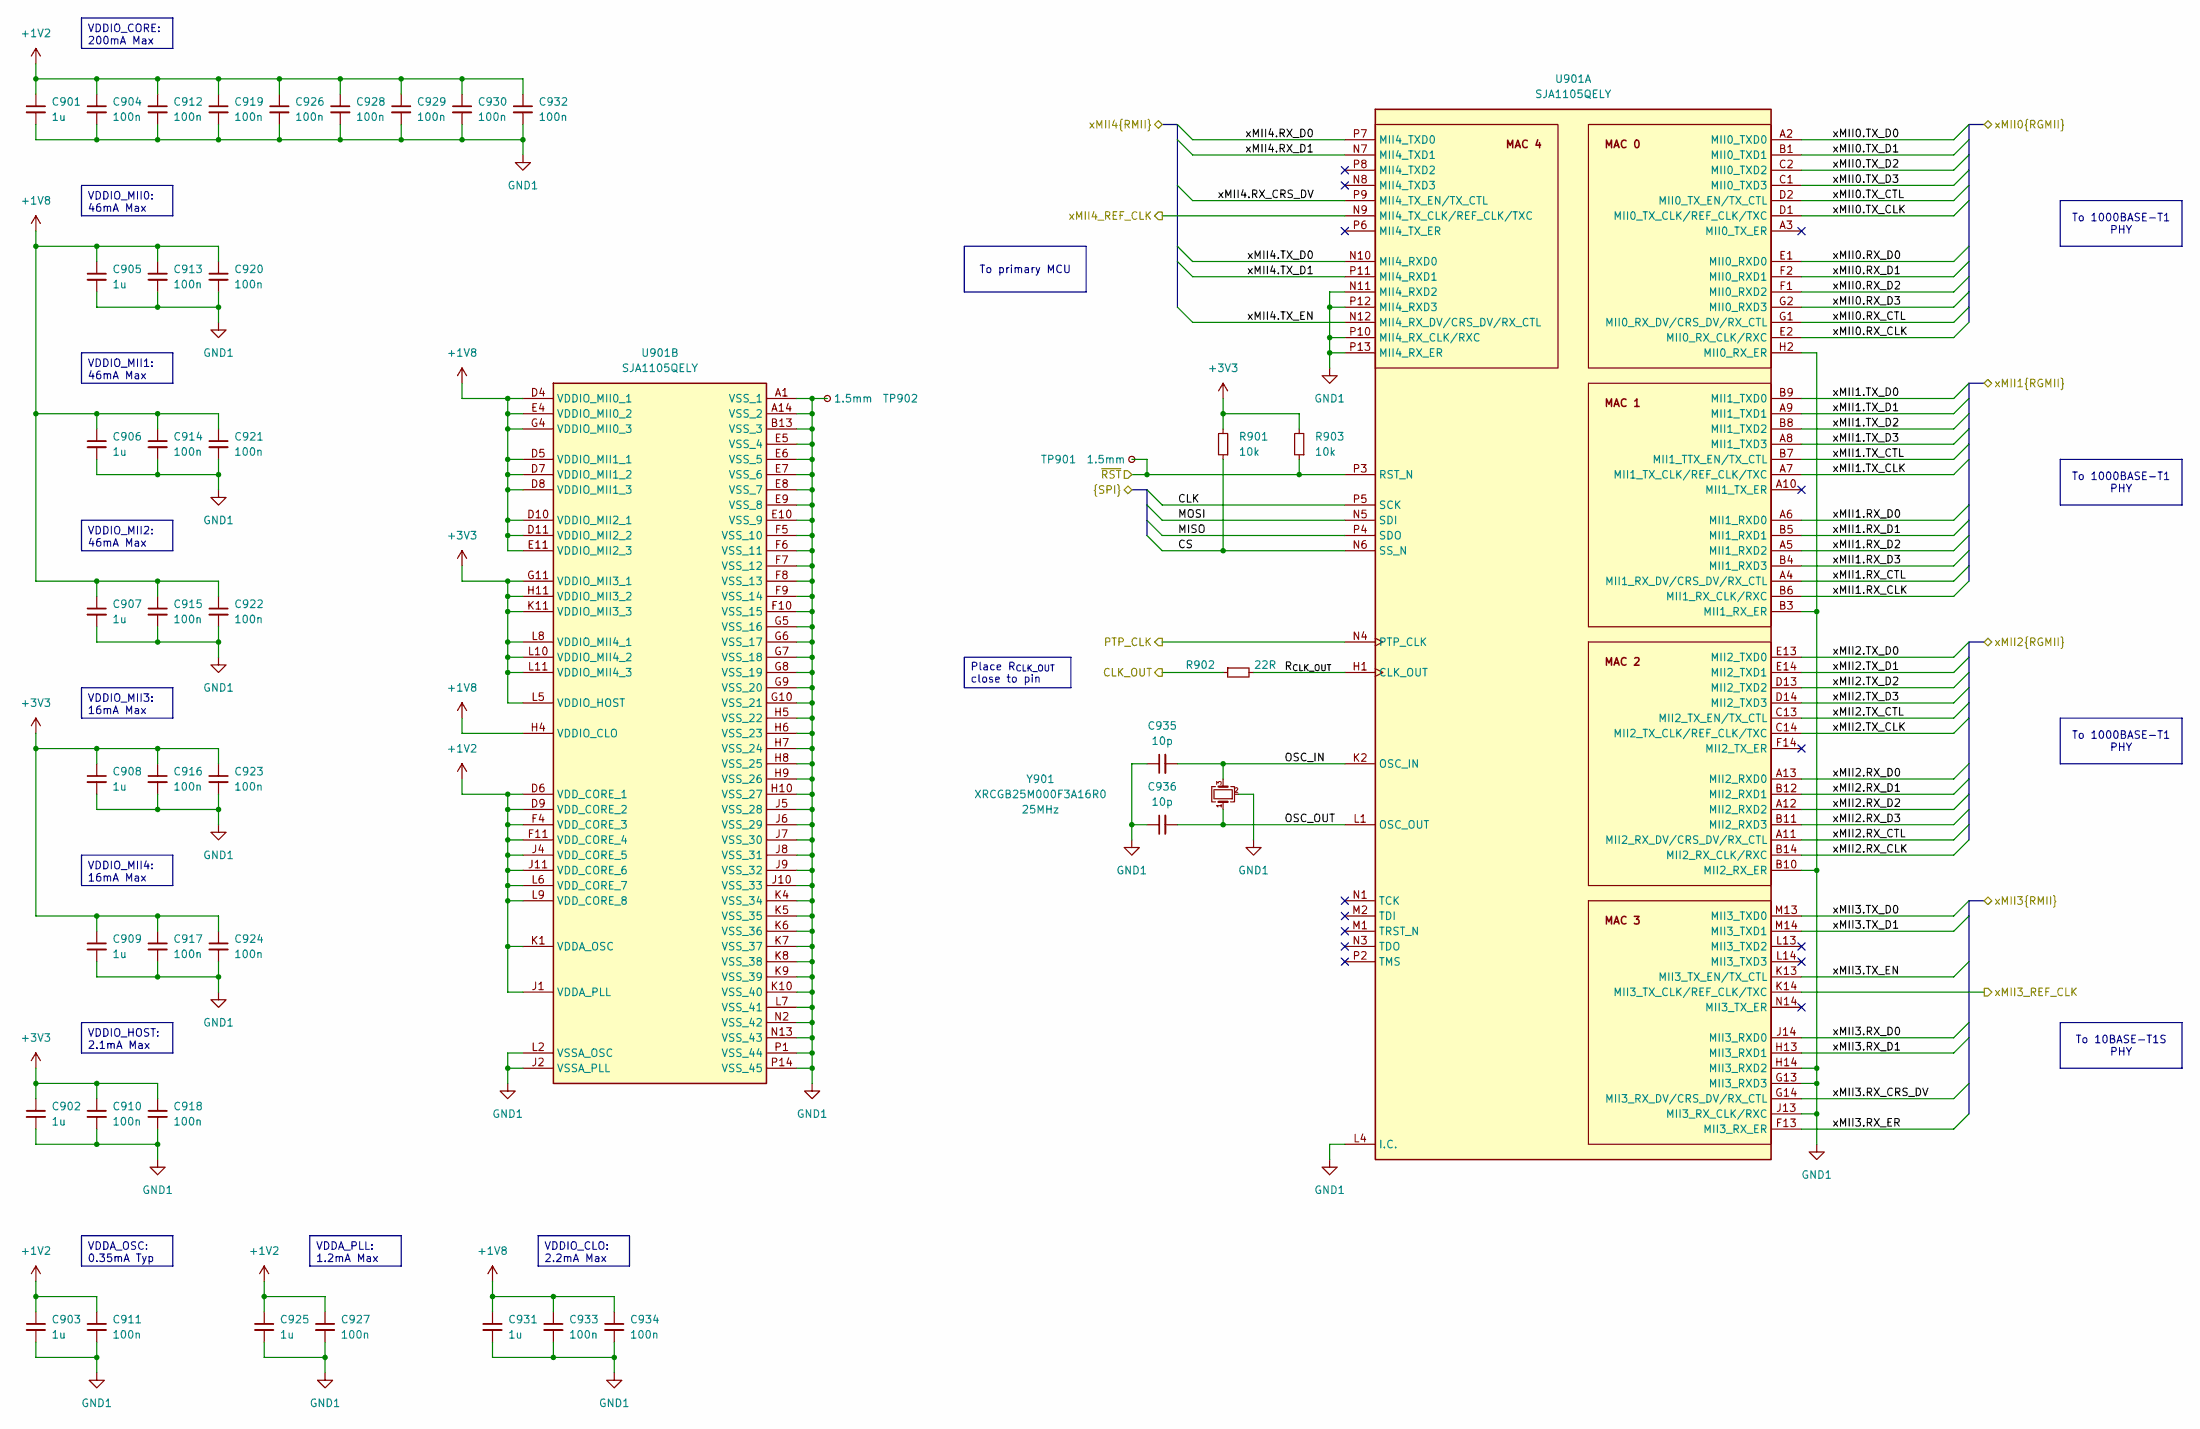
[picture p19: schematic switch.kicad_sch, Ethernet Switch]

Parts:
C901, C902, C903, C905, C906, C907, C908, C909, C925, C931: 1u; C_0402
C904, C910, C911, C912, C913, C914, C915, C916, C917, C918, C919, C920, C921, C922, C923, C924, C926, C927, C928, C929, C930, C932, C933, C934: 100n; C_0402
C935, C936: 10p; C_0402
R901, R903: 10k; R_0402
R902: 22R; R_0402
TP901, TP902: 1.5mm; TestPoint_Pad_D1.5mm
U901: SJA1105QELY; BGA159C80P14X14_1200X1200X150; Mouser Part Number 771-SJA1105QELY
Y901: XRCGB25M000F3A16R0

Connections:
+1V2: C901.1, C903.1, C904.1, C911.1, C912.1, C919.1, C925.1, C926.1, C927.1, C928.1, C929.1, C930.1, C932.1, U901.D6 (VDD_CORE_1), U901.D9 (VDD_CORE_2), U901.F4 (VDD_CORE_3), U901.F11 (VDD_CORE_4), U901.J1 (VDDA_PLL), U901.J4 (VDD_CORE_5), U901.J11 (VDD_CORE_6), U901.K1 (VDDA_OSC), U901.L6 (VDD_CORE_7), U901.L9 (VDD_CORE_8); also elsewhere on the board
+1V8: C905.1, C906.1, C907.1, C913.1, C914.1, C915.1, C920.1, C921.1, C922.1, C931.1, C933.1, C934.1, U901.D4 (VDDIO_MII0_1), U901.D5 (VDDIO_MII1_1), U901.D7 (VDDIO_MII1_2), U901.D8 (VDDIO_MII1_3), U901.D10 (VDDIO_MII2_1), U901.D11 (VDDIO_MII2_2), U901.E4 (VDDIO_MII0_2), U901.E11 (VDDIO_MII2_3), U901.G4 (VDDIO_MII0_3), U901.H4 (VDDIO_CLO); also elsewhere on the board
+3V3: C902.1, C908.1, C909.1, C910.1, C916.1, C917.1, C918.1, C923.1, C924.1, R901.2, R903.2, U901.G11 (VDDIO_MII3_1), U901.H11 (VDDIO_MII3_2), U901.K11 (VDDIO_MII3_3), U901.L5 (VDDIO_HOST), U901.L8 (VDDIO_MII4_1), U901.L10 (VDDIO_MII4_2), U901.L11 (VDDIO_MII4_3); also elsewhere on the board
/PHYs/CLK_IN: R902.1; also elsewhere on the board
/PHYs/xMII0.RX_CLK: U901.E2 (MII0_RX_CLK/RXC); also elsewhere on the board
/PHYs/xMII0.RX_CTL: U901.G1 (MII0_RX_DV/CRS_DV/RX_CTL); also elsewhere on the board
/PHYs/xMII0.RX_D0: U901.E1 (MII0_RXD0); also elsewhere on the board
/PHYs/xMII0.RX_D1: U901.F2 (MII0_RXD1); also elsewhere on the board
/PHYs/xMII0.RX_D2: U901.F1 (MII0_RXD2); also elsewhere on the board
/PHYs/xMII0.RX_D3: U901.G2 (MII0_RXD3); also elsewhere on the board
/PHYs/xMII0.TX_CLK: U901.D1 (MII0_TX_CLK/REF_CLK/TXC); also elsewhere on the board
/PHYs/xMII0.TX_CTL: U901.D2 (MII0_TX_EN/TX_CTL); also elsewhere on the board
/PHYs/xMII0.TX_D0: U901.A2 (MII0_TXD0); also elsewhere on the board
/PHYs/xMII0.TX_D1: U901.B1 (MII0_TXD1); also elsewhere on the board
/PHYs/xMII0.TX_D2: U901.C2 (MII0_TXD2); also elsewhere on the board
/PHYs/xMII0.TX_D3: U901.C1 (MII0_TXD3); also elsewhere on the board
/PHYs/xMII1.RX_CLK: U901.B6 (MII1_RX_CLK/RXC); also elsewhere on the board
/PHYs/xMII1.RX_CTL: U901.A4 (MII1_RX_DV/CRS_DV/RX_CTL); also elsewhere on the board
/PHYs/xMII1.RX_D0: U901.A6 (MII1_RXD0); also elsewhere on the board
/PHYs/xMII1.RX_D1: U901.B5 (MII1_RXD1); also elsewhere on the board
/PHYs/xMII1.RX_D2: U901.A5 (MII1_RXD2); also elsewhere on the board
/PHYs/xMII1.RX_D3: U901.B4 (MII1_RXD3); also elsewhere on the board
/PHYs/xMII1.TX_CLK: U901.A7 (MII1_TX_CLK/REF_CLK/TXC); also elsewhere on the board
/PHYs/xMII1.TX_CTL: U901.B7 (MII1_TTX_EN/TX_CTL); also elsewhere on the board
/PHYs/xMII1.TX_D0: U901.B9 (MII1_TXD0); also elsewhere on the board
/PHYs/xMII1.TX_D1: U901.A9 (MII1_TXD1); also elsewhere on the board
/PHYs/xMII1.TX_D2: U901.B8 (MII1_TXD2); also elsewhere on the board
/PHYs/xMII1.TX_D3: U901.A8 (MII1_TXD3); also elsewhere on the board
/PHYs/xMII2.RX_CLK: U901.B14 (MII2_RX_CLK/RXC); also elsewhere on the board
/PHYs/xMII2.RX_CTL: U901.A11 (MII2_RX_DV/CRS_DV/RX_CTL); also elsewhere on the board
/PHYs/xMII2.RX_D0: U901.A13 (MII2_RXD0); also elsewhere on the board
/PHYs/xMII2.RX_D1: U901.B12 (MII2_RXD1); also elsewhere on the board
/PHYs/xMII2.RX_D2: U901.A12 (MII2_RXD2); also elsewhere on the board
/PHYs/xMII2.RX_D3: U901.B11 (MII2_RXD3); also elsewhere on the board
/PHYs/xMII2.TX_CLK: U901.C14 (MII2_TX_CLK/REF_CLK/TXC); also elsewhere on the board
/PHYs/xMII2.TX_CTL: U901.C13 (MII2_TX_EN/TX_CTL); also elsewhere on the board
/PHYs/xMII2.TX_D0: U901.E13 (MII2_TXD0); also elsewhere on the board
/PHYs/xMII2.TX_D1: U901.E14 (MII2_TXD1); also elsewhere on the board
/PHYs/xMII2.TX_D2: U901.D13 (MII2_TXD2); also elsewhere on the board
/PHYs/xMII2.TX_D3: U901.D14 (MII2_TXD3); also elsewhere on the board
/PHYs/xMII3.RX_CRS_DV: U901.G14 (MII3_RX_DV/CRS_DV/RX_CTL); also elsewhere on the board
/PHYs/xMII3.RX_D0: U901.J14 (MII3_RXD0); also elsewhere on the board
/PHYs/xMII3.RX_D1: U901.H13 (MII3_RXD1); also elsewhere on the board
/PHYs/xMII3.RX_ER: U901.F13 (MII3_RX_ER); also elsewhere on the board
/PHYs/xMII3.TX_D0: U901.M13 (MII3_TXD0); also elsewhere on the board
/PHYs/xMII3.TX_D1: U901.M14 (MII3_TXD1); also elsewhere on the board
/PHYs/xMII3.TX_EN: U901.K13 (MII3_TX_EN/TX_CTL); also elsewhere on the board
/PHYs/xMII3_REF_CLK: U901.K14 (MII3_TX_CLK/REF_CLK/TXC); also elsewhere on the board
/Primary MCU/PTP_SYNCHRO: U901.N4 (PTP_CLK); also elsewhere on the board
/Primary MCU/RMII.RX_CRS_DV: U901.P9 (MII4_TX_EN/TX_CTL); also elsewhere on the board
/Primary MCU/RMII.RX_D0: U901.P7 (MII4_TXD0); also elsewhere on the board
/Primary MCU/RMII.RX_D1: U901.N7 (MII4_TXD1); also elsewhere on the board
/Primary MCU/RMII.TX_D0: U901.N10 (MII4_RXD0); also elsewhere on the board
/Primary MCU/RMII.TX_D1: U901.P11 (MII4_RXD1); also elsewhere on the board
/Primary MCU/RMII.TX_EN: U901.N12 (MII4_RX_DV/CRS_DV/RX_CTL); also elsewhere on the board
/Primary MCU/RMII_REF_CLK: U901.N9 (MII4_TX_CLK/REF_CLK/TXC); also elsewhere on the board
/Primary MCU/SWCH.CLK: U901.P5 (SCK); also elsewhere on the board
/Primary MCU/SWCH.CS: R901.1, U901.N6 (SS_N); also elsewhere on the board
/Primary MCU/SWCH.MISO: U901.P4 (SDO); also elsewhere on the board
/Primary MCU/SWCH.MOSI: U901.N5 (SDI); also elsewhere on the board
/Primary MCU/~SWCH_RST: R903.1, TP901.1 (1_1), U901.P3 (RST_N); also elsewhere on the board
/Switch/OSC_IN: C935.2, U901.K2 (OSC_IN), Y901.3
/Switch/OSC_OUT: C936.2, U901.L1 (OSC_OUT), Y901.1
/Switch/R_{CLK_OUT}: R902.2, U901.H1 (CLK_OUT)
GND1: C901.2, C902.2, C903.2, C904.2, C905.2, C906.2, C907.2, C908.2, C909.2, C910.2, C911.2, C912.2, C913.2, C914.2, C915.2, C916.2, C917.2, C918.2, C919.2, C920.2, C921.2, C922.2, C923.2, C924.2, C925.2, C926.2, C927.2, C928.2, C929.2, C930.2, C931.2, C932.2, C933.2, C934.2, C935.1, C936.1, TP902.1 (1_1), U901.A1 (VSS_1), U901.A14 (VSS_2), U901.B3 (MII1_RX_ER), U901.B10 (MII2_RX_ER), U901.B13 (VSS_3), U901.E5 (VSS_4), U901.E6 (VSS_5), U901.E7 (VSS_6), U901.E8 (VSS_7), U901.E9 (VSS_8), U901.E10 (VSS_9), U901.F5 (VSS_10), U901.F6 (VSS_11), U901.F7 (VSS_12), U901.F8 (VSS_13), U901.F9 (VSS_14), U901.F10 (VSS_15), U901.G5 (VSS_16), U901.G6 (VSS_17), U901.G7 (VSS_18), U901.G8 (VSS_19), U901.G9 (VSS_20), U901.G10 (VSS_21), U901.G13 (MII3_RXD3), U901.H2 (MII0_RX_ER), U901.H5 (VSS_22), U901.H6 (VSS_23), U901.H7 (VSS_24), U901.H8 (VSS_25), U901.H9 (VSS_26), U901.H10 (VSS_27), U901.H14 (MII3_RXD2), U901.J2 (VSSA_PLL), U901.J5 (VSS_28), U901.J6 (VSS_29), U901.J7 (VSS_30), U901.J8 (VSS_31), U901.J9 (VSS_32), U901.J10 (VSS_33), U901.J13 (MII3_RX_CLK/RXC), U901.K4 (VSS_34), U901.K5 (VSS_35), U901.K6 (VSS_36), U901.K7 (VSS_37), U901.K8 (VSS_38), U901.K9 (VSS_39), U901.K10 (VSS_40), U901.L2 (VSSA_OSC), U901.L4 (I.C.), U901.L7 (VSS_41), U901.N2 (VSS_42), U901.N11 (MII4_RXD2), U901.N13 (VSS_43), U901.P1 (VSS_44), U901.P10 (MII4_RX_CLK/RXC), U901.P12 (MII4_RXD3), U901.P13 (MII4_RX_ER), U901.P14 (VSS_45), Y901.2 (G), Y901.4 (G); also elsewhere on the board

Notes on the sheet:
To 1000BASE-T1 PHY
VDDIO_MII3: 16mA Max
VDDIO_CLO: 2.2mA Max
VDDIO_MII2: 46mA Max
VDDIO_HOST: 2.1mA Max
VDDA_OSC: 0.35mA Typ
VDDIO_MII0: 46mA Max
To 10BASE-T1S PHY
VDDA_PLL: 1.2mA Max
VDDIO_CORE: 200mA Max
Place R_{CLK_OUT} close to pin
VDDIO_MII4: 16mA Max
To primary MCU
VDDIO_MII1: 46mA Max

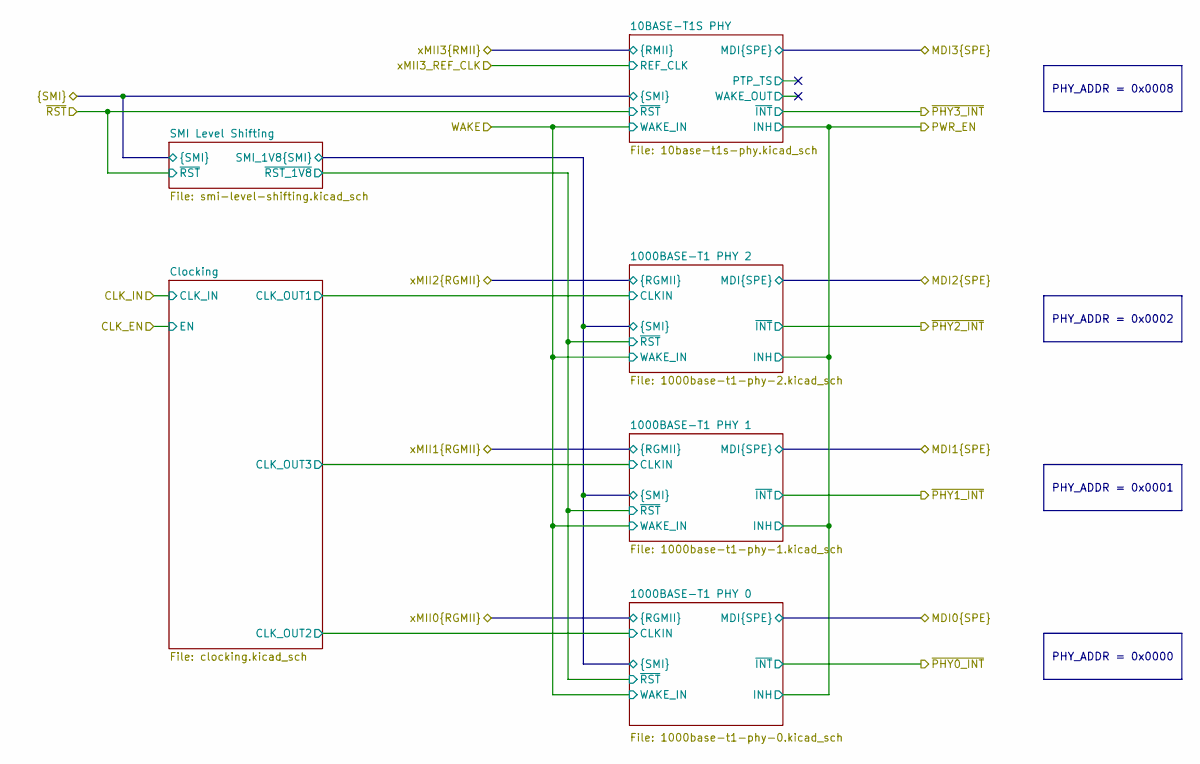
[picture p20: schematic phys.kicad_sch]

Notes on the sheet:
PHY_ADDR = 0x0000
PHY_ADDR = 0x0008
PHY_ADDR = 0x0001
PHY_ADDR = 0x0002

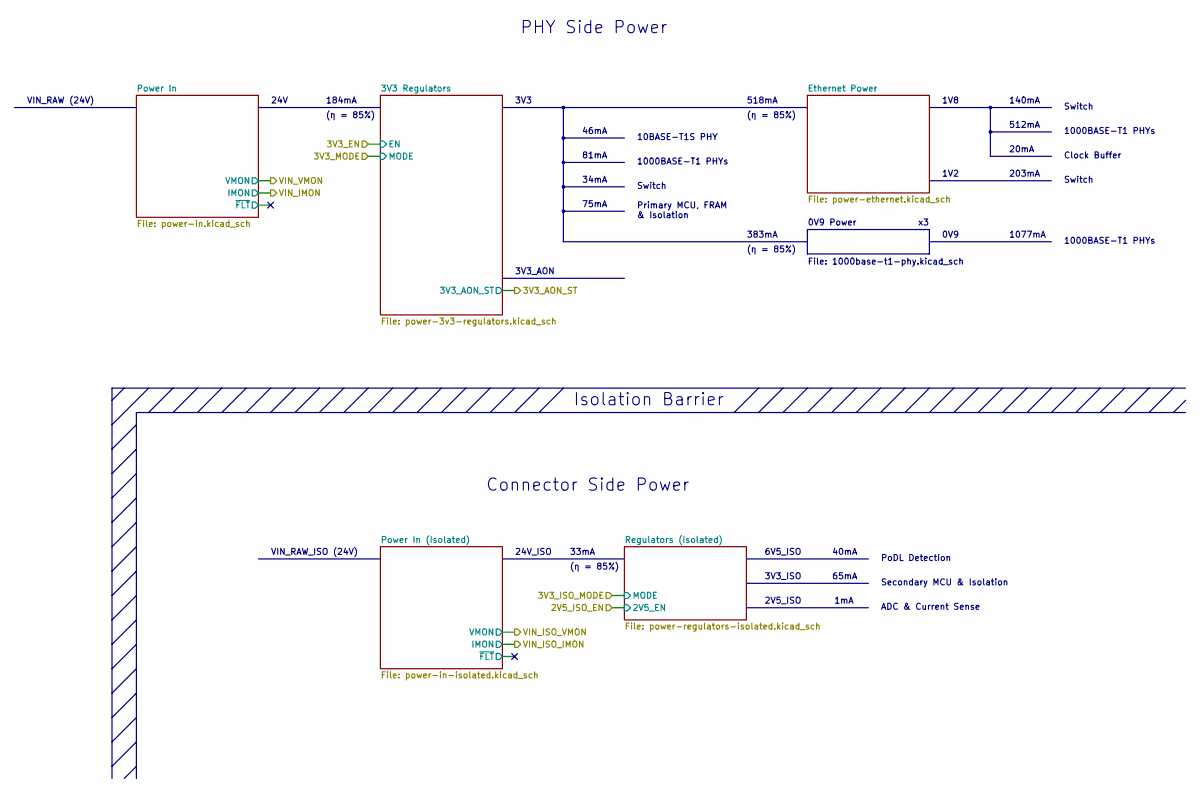
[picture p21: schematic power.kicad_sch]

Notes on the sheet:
1V2
Primary MCU, FRAM & Isolation
VIN_RAW_ISO (24V)
34mA
81mA
VIN_RAW (24V)
(η = 85%)
Clock Buffer
Switch
40mA
1V8
10BASE-T1S PHY
3V3
140mA
24V_ISO
33mA
512mA
1mA
46mA
0V9 Power
1000BASE-T1 PHYs
24V
File: 1000base-t1-phy.kicad_sch
518mA
PHY Side Power
184mA
1077mA
6V5_ISO
Isolation Barrier
PoDL Detection
2V5_ISO
Connector Side Power
383mA
203mA
75mA
Secondary MCU & Isolation
65mA
ADC & Current Sense
3V3_AON
20mA

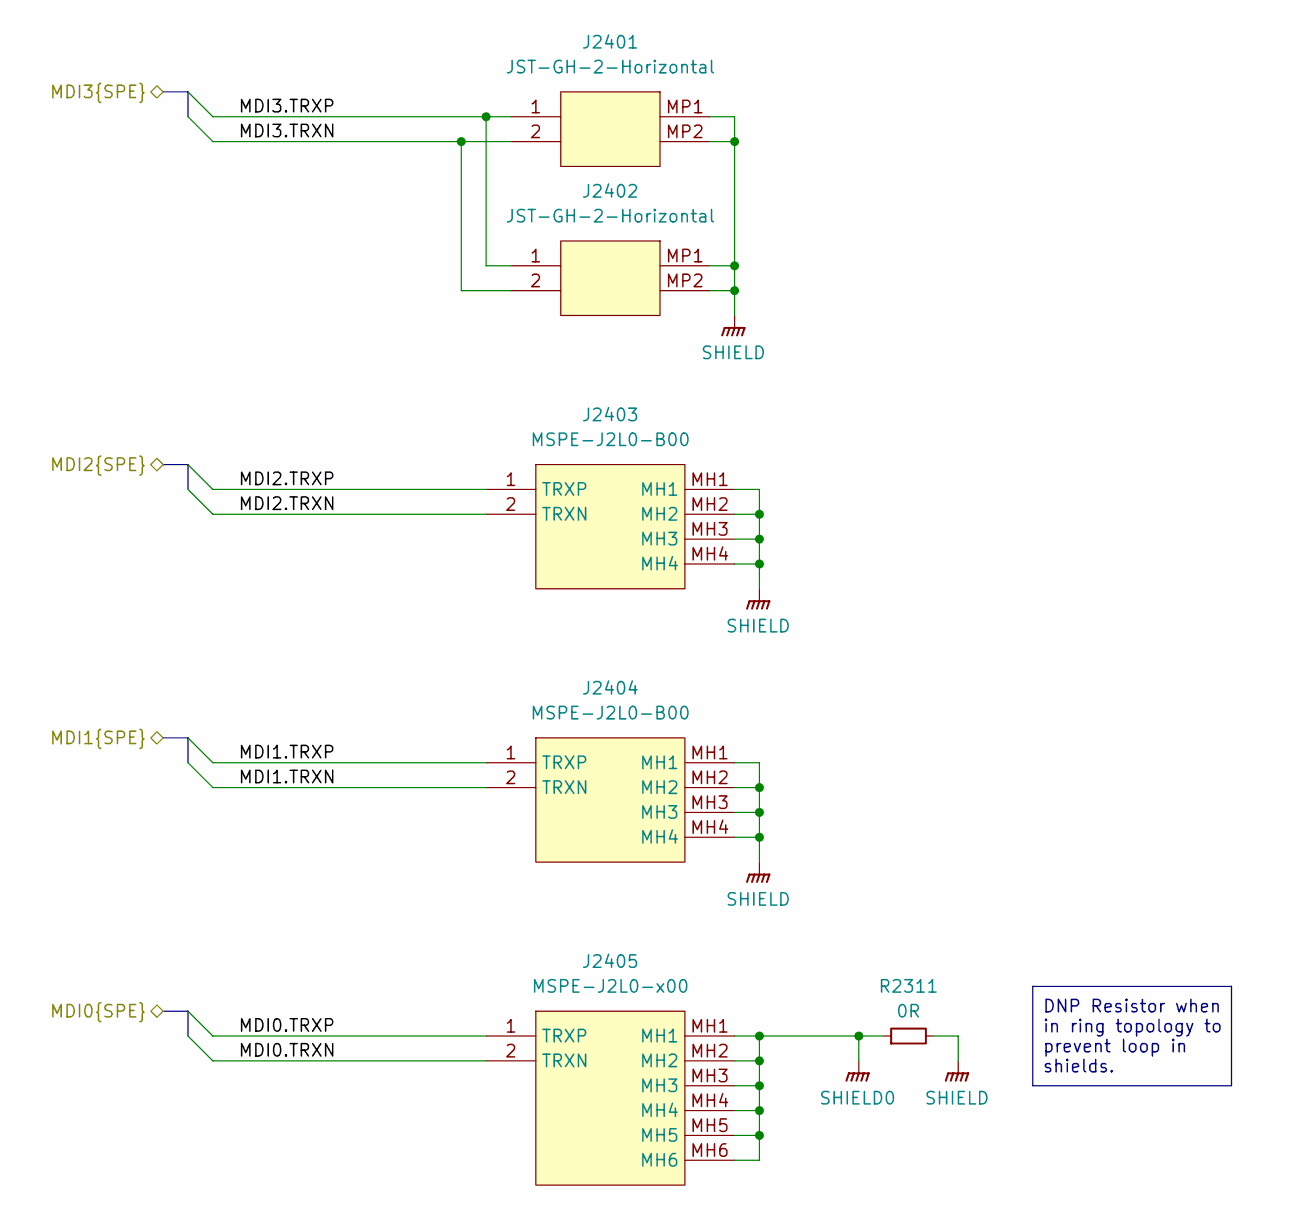
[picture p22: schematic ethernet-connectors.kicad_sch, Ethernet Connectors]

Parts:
J2401, J2402: JST-GH-2-Horizontal; JST_GH_SM02B-GHS-TB_1x02-1MP_P1.25mm_Horizontal
J2403, J2404: MSPE-J2L0-B00; MSPEJ2L0B00; Mouser Part Number 523-MSPE-J2L0-B00
J2405: MSPE-J2L0-x00; MSPEJ2L0x00; Mouser Part Number 523-MSPE-J2L0-B00
R2311: 0R; R_0402

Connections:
/CDNs & PoDL/MDI0_OUT.TRXN: J2405.2 (TRXN); also elsewhere on the board
/CDNs & PoDL/MDI0_OUT.TRXP: J2405.1 (TRXP); also elsewhere on the board
/CDNs & PoDL/MDI1_OUT.TRXN: J2404.2 (TRXN); also elsewhere on the board
/CDNs & PoDL/MDI1_OUT.TRXP: J2404.1 (TRXP); also elsewhere on the board
/CDNs & PoDL/MDI2_OUT.TRXN: J2403.2 (TRXN); also elsewhere on the board
/CDNs & PoDL/MDI2_OUT.TRXP: J2403.1 (TRXP); also elsewhere on the board
/CDNs & PoDL/MDI3_OUT.TRXN: J2401.2, J2402.2; also elsewhere on the board
/CDNs & PoDL/MDI3_OUT.TRXP: J2401.1, J2402.1; also elsewhere on the board
SHIELD: J2401.MP1, J2401.MP2, J2402.MP1, J2402.MP2, J2403.MH1, J2403.MH2, J2403.MH3, J2403.MH4, J2404.MH1, J2404.MH2, J2404.MH3, J2404.MH4, R2311.2; also elsewhere on the board
SHIELD0: J2405.MH1, J2405.MH2, J2405.MH3, J2405.MH4, J2405.MH5, J2405.MH6, R2311.1; also elsewhere on the board

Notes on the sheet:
DNP Resistor when in ring topology to prevent loop in shields.

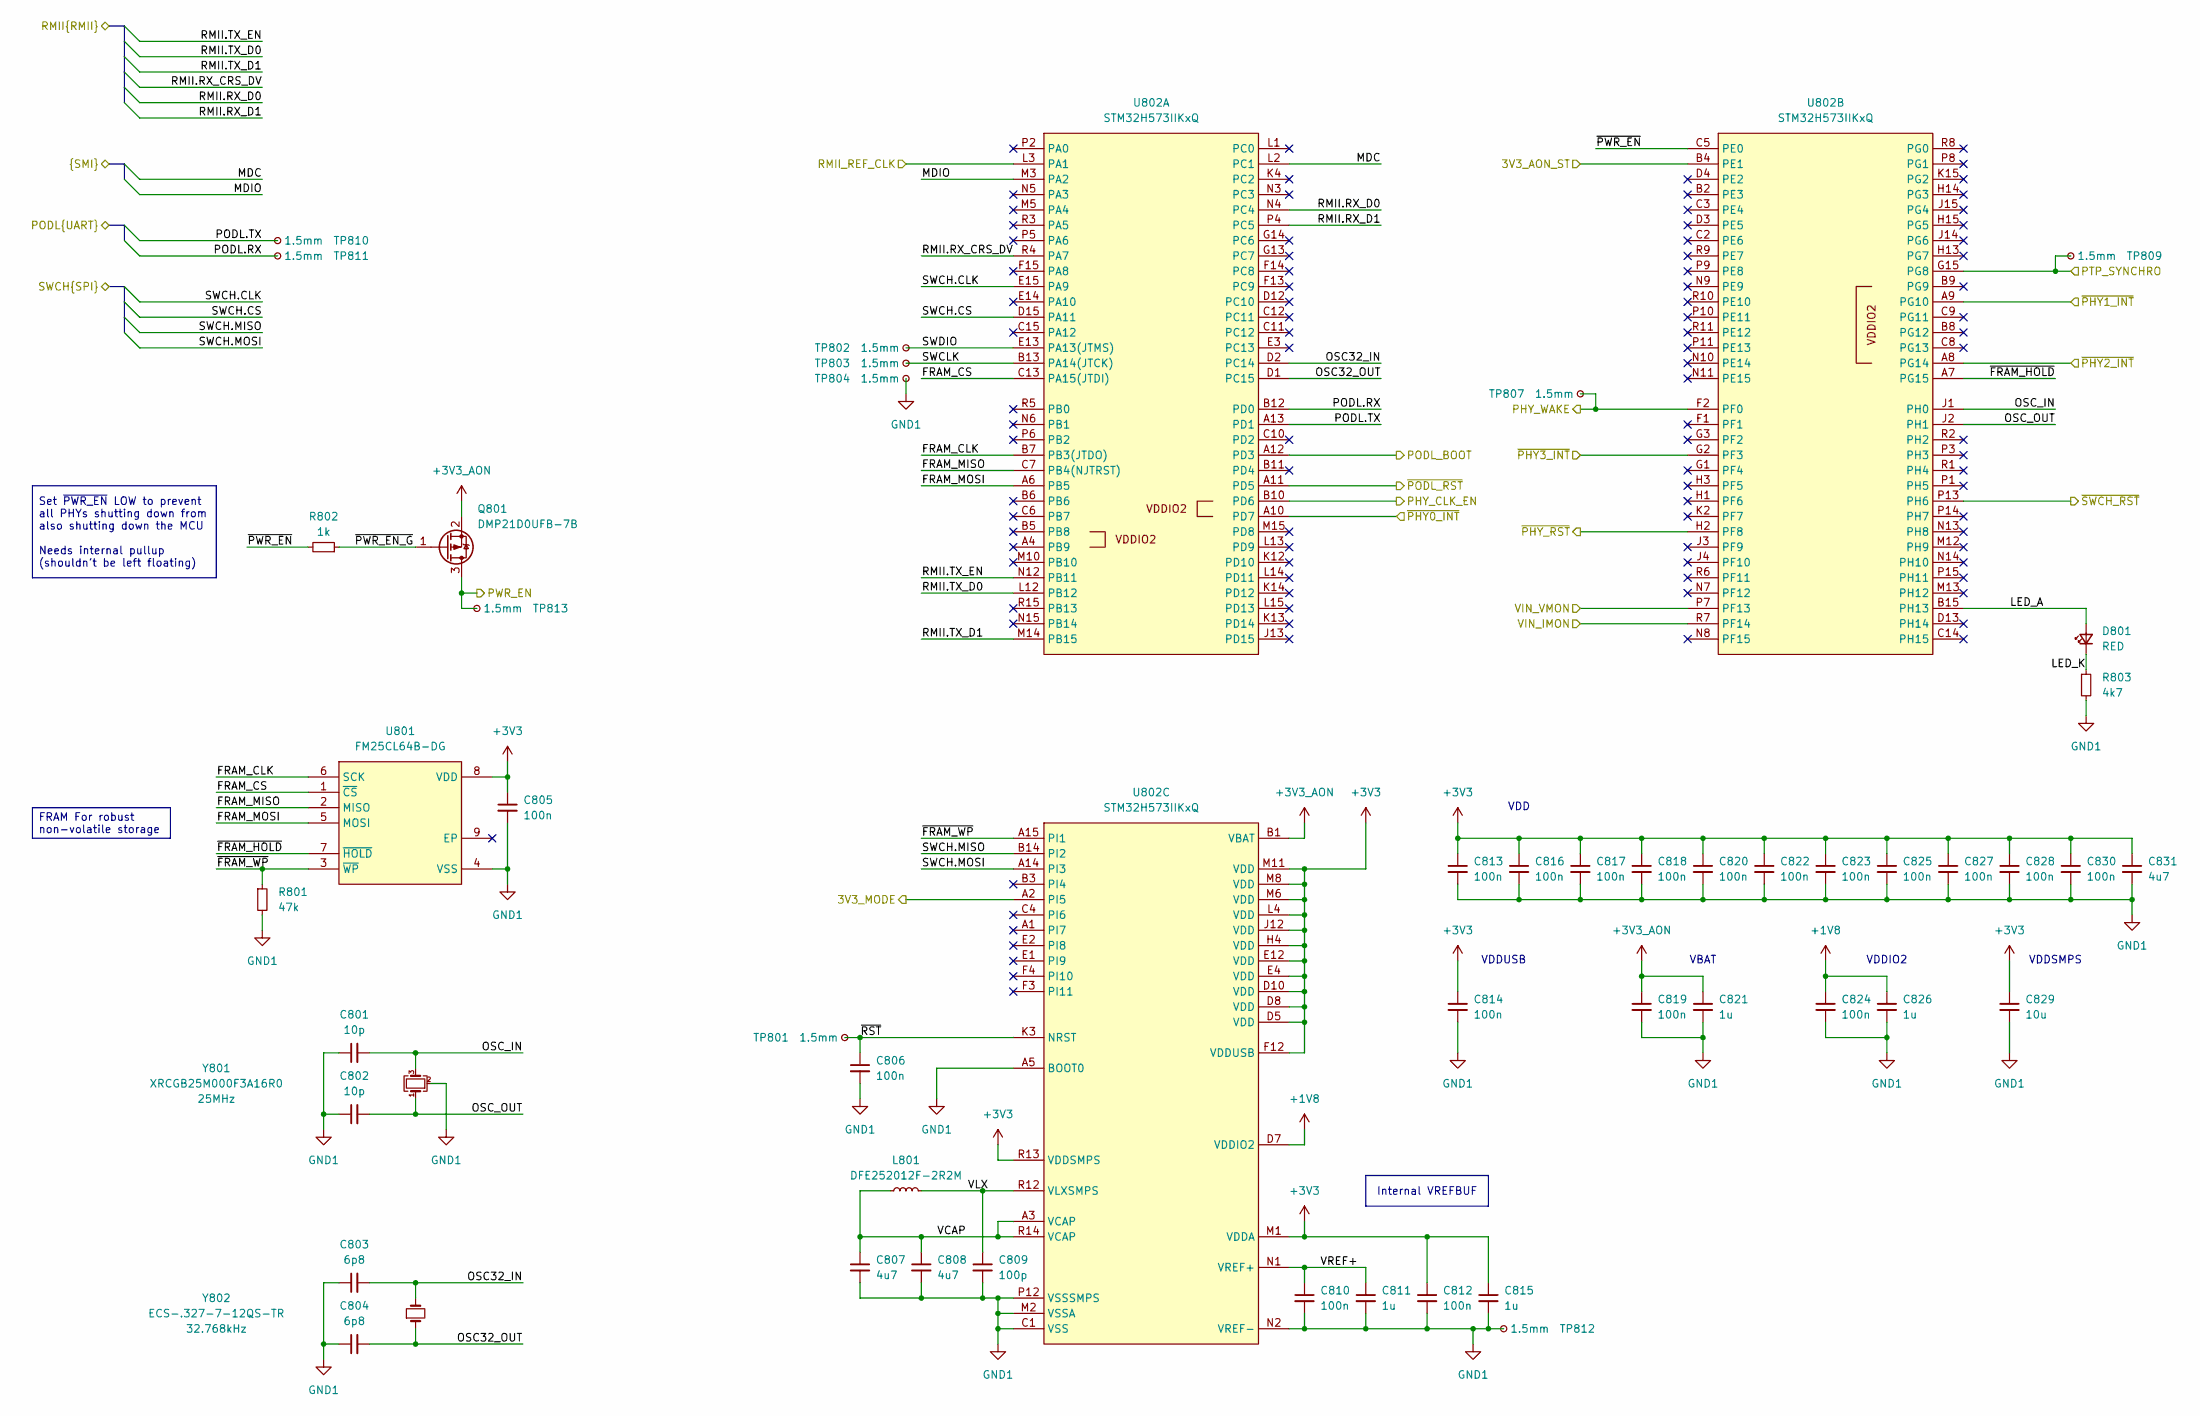
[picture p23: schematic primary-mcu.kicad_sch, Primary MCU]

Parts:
C801, C802: 10p; C_0402
C803, C804: 6p8; C_0402
C805, C806, C810, C812, C813, C814, C816, C817, C818, C819, C820, C822, C823, C824, C825, C827, C828, C830: 100n; C_0402
C807, C808, C831: 4u7; C_0402
C809: 100p; C_0402
C811, C815, C821, C826: 1u; C_0402
C829: 10u; C_0402
D801: RED; LED_0402_1005Metric
L801: DFE252012F-2R2M; L_1008_2520Metric
Q801: DMP21D0UFB-7B; DMP21D0UFB7B; Mouser Part Number 621-DMP21D0UFB-7B
R801: 47k; R_0402
R802: 1k; R_0402
R803: 4k7; R_0402
TP801, TP802, TP803, TP804, TP807, TP809, TP810, TP811, TP812, TP813: 1.5mm; TestPoint_Pad_D1.5mm
U801: FM25CL64B-DG; SON95P400X450X80-9N; Mouser Part Number 877-FM25CL64B-DG
U802: STM32H573IIKxQ; UFBGA-201_10x10mm_Layout15x15_P0.65mm
Y801: XRCGB25M000F3A16R0
Y802: ECS-.327-7-12QS-TR

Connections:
+1V8: C824.1, C826.1, U802.D7 (VDDIO2); also elsewhere on the board
+3V3: C805.1, C812.1, C813.1, C814.1, C815.1, C816.1, C817.1, C818.1, C820.1, C822.1, C823.1, C825.1, C827.1, C828.1, C829.1, C830.1, C831.1, U801.8 (VDD), U802.D5 (VDD), U802.D8 (VDD), U802.D10 (VDD), U802.E4 (VDD), U802.E12 (VDD), U802.F12 (VDDUSB), U802.H4 (VDD), U802.J12 (VDD), U802.L4 (VDD), U802.M1 (VDDA), U802.M6 (VDD), U802.M8 (VDD), U802.M11 (VDD), U802.R13 (VDDSMPS); also elsewhere on the board
+3V3_AON: C819.1, C821.1, Q801.2 (S), U802.B1 (VBAT); also elsewhere on the board
/Isolation Crossing/IN_C: U802.A12 (PD3); also elsewhere on the board
/Isolation Crossing/IN_D: U802.A11 (PD5); also elsewhere on the board
/PHYs/1000BASE-T1 PHY 0/INH: Q801.3 (D), TP813.1 (1_1); also elsewhere on the board
/PHYs/CLK_EN: U802.B10 (PD6); also elsewhere on the board
/PHYs/MDC: U802.L2 (PC1); also elsewhere on the board
/PHYs/MDIO: U802.M3 (PA2); also elsewhere on the board
/PHYs/WAKE: TP807.1 (1_1), U802.F2 (PF0); also elsewhere on the board
/PHYs/~PHY0_INT: U802.A10 (PD7); also elsewhere on the board
/PHYs/~PHY1_INT: U802.A9 (PG10); also elsewhere on the board
/PHYs/~PHY2_INT: U802.A8 (PG14); also elsewhere on the board
/PHYs/~PHY3_INT: U802.G2 (PF3); also elsewhere on the board
/PHYs/~RST: U802.H2 (PF8); also elsewhere on the board
/Power/3V3_AON_ST: U802.B4 (PE1); also elsewhere on the board
/Power/3V3_MODE: U802.A2 (PI5); also elsewhere on the board
/Power/VIN_IMON: U802.R7 (PF14); also elsewhere on the board
/Power/VIN_VMON: U802.P7 (PF13); also elsewhere on the board
/Primary MCU/FRAM_CLK: U801.6 (SCK), U802.B7 (PB3(JTDO))
/Primary MCU/FRAM_CS: U801.1 (~CS), U802.C13 (PA15(JTDI))
/Primary MCU/FRAM_MISO: U801.2 (MISO), U802.C7 (PB4(NJTRST))
/Primary MCU/FRAM_MOSI: U801.5 (MOSI), U802.A6 (PB5)
/Primary MCU/LED_A: D801.2 (A), U802.B15 (PH13)
/Primary MCU/LED_K: D801.1 (K), R803.1
/Primary MCU/OSC32_IN: C803.2, U802.D2 (PC14), Y802.2
/Primary MCU/OSC32_OUT: C804.2, U802.D1 (PC15), Y802.1
/Primary MCU/OSC_IN: C801.2, U802.J1 (PH0), Y801.3
/Primary MCU/OSC_OUT: C802.2, U802.J2 (PH1), Y801.1
/Primary MCU/PODL.RX: TP811.1 (1_1), U802.B12 (PD0); also elsewhere on the board
/Primary MCU/PODL.TX: TP810.1 (1_1), U802.A13 (PD1); also elsewhere on the board
/Primary MCU/PTP_SYNCHRO: TP809.1 (1_1), U802.G15 (PG8); also elsewhere on the board
/Primary MCU/RMII.RX_CRS_DV: U802.R4 (PA7); also elsewhere on the board
/Primary MCU/RMII.RX_D0: U802.N4 (PC4); also elsewhere on the board
/Primary MCU/RMII.RX_D1: U802.P4 (PC5); also elsewhere on the board
/Primary MCU/RMII.TX_D0: U802.L12 (PB12); also elsewhere on the board
/Primary MCU/RMII.TX_D1: U802.M14 (PB15); also elsewhere on the board
/Primary MCU/RMII.TX_EN: U802.N12 (PB11); also elsewhere on the board
/Primary MCU/RMII_REF_CLK: U802.L3 (PA1); also elsewhere on the board
/Primary MCU/SWCH.CLK: U802.E15 (PA9); also elsewhere on the board
/Primary MCU/SWCH.CS: U802.D15 (PA11); also elsewhere on the board
/Primary MCU/SWCH.MISO: U802.B14 (PI2); also elsewhere on the board
/Primary MCU/SWCH.MOSI: U802.A14 (PI3); also elsewhere on the board
/Primary MCU/SWCLK: TP803.1 (1_1), U802.B13 (PA14(JTCK))
/Primary MCU/SWDIO: TP802.1 (1_1), U802.E13 (PA13(JTMS))
/Primary MCU/VCAP: C807.1, C808.1, L801.2, U802.A3 (VCAP), U802.R14 (VCAP)
/Primary MCU/VLX: C809.1, L801.1, U802.R12 (VLXSMPS)
/Primary MCU/VREF+: C810.1, C811.1, U802.N1 (VREF+)
/Primary MCU/~FRAM_HOLD: U801.7 (~HOLD), U802.A7 (PG15)
/Primary MCU/~FRAM_WP: R801.1, U801.3 (~WP), U802.A15 (PI1)
/Primary MCU/~PWR_EN_G: Q801.1 (G), R802.1
/Primary MCU/~PWR_EN: R802.2, U802.C5 (PE0)
/Primary MCU/~RST: C806.1, TP801.1 (1_1), U802.K3 (NRST)
/Primary MCU/~SWCH_RST: U802.P13 (PH6); also elsewhere on the board
GND1: C801.1, C802.1, C803.1, C804.1, C805.2, C806.2, C807.2, C808.2, C809.2, C810.2, C811.2, C812.2, C813.2, C814.2, C815.2, C816.2, C817.2, C818.2, C819.2, C820.2, C821.2, C822.2, C823.2, C824.2, C825.2, C826.2, C827.2, C828.2, C829.2, C830.2, C831.2, R801.2, R803.2, TP804.1 (1_1), TP812.1 (1_1), U801.4 (VSS), U802.A5 (BOOT0), U802.C1 (VSS), U802.D6 (VSS), U802.D9 (VSS), U802.D11 (VSS), U802.D14 (VSS), U802.F6 (VSS), U802.F7 (VSS), U802.F8 (VSS), U802.F9 (VSS), U802.F10 (VSS), U802.G4 (VSS), U802.G6 (VSS), U802.G7 (VSS), U802.G8 (VSS), U802.G9 (VSS), U802.G10 (VSS), U802.G12 (VSS), U802.H6 (VSS), U802.H7 (VSS), U802.H8 (VSS), U802.H9 (VSS), U802.H10 (VSS), U802.H12 (VSS), U802.J6 (VSS), U802.J7 (VSS), U802.J8 (VSS), U802.J9 (VSS), U802.J10 (VSS), U802.K1 (VSS), U802.K6 (VSS), U802.K7 (VSS), U802.K8 (VSS), U802.K9 (VSS), U802.K10 (VSS), U802.M2 (VSSA), U802.M4 (VSS), U802.M7 (VSS), U802.M9 (VSS), U802.N2 (VREF-), U802.P12 (VSSSMPS), Y801.2 (G), Y801.4 (G); also elsewhere on the board

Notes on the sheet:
VBAT
VDDSMPS
VDDIO2
VDDUSB
VDD
FRAM For robust non-volatile storage
Internal VREFBUF
Set ~{PWR_EN} LOW to prevent all PHYs shutting down from also shutting down the MCU Needs internal pullup (shouldn't be left floating)

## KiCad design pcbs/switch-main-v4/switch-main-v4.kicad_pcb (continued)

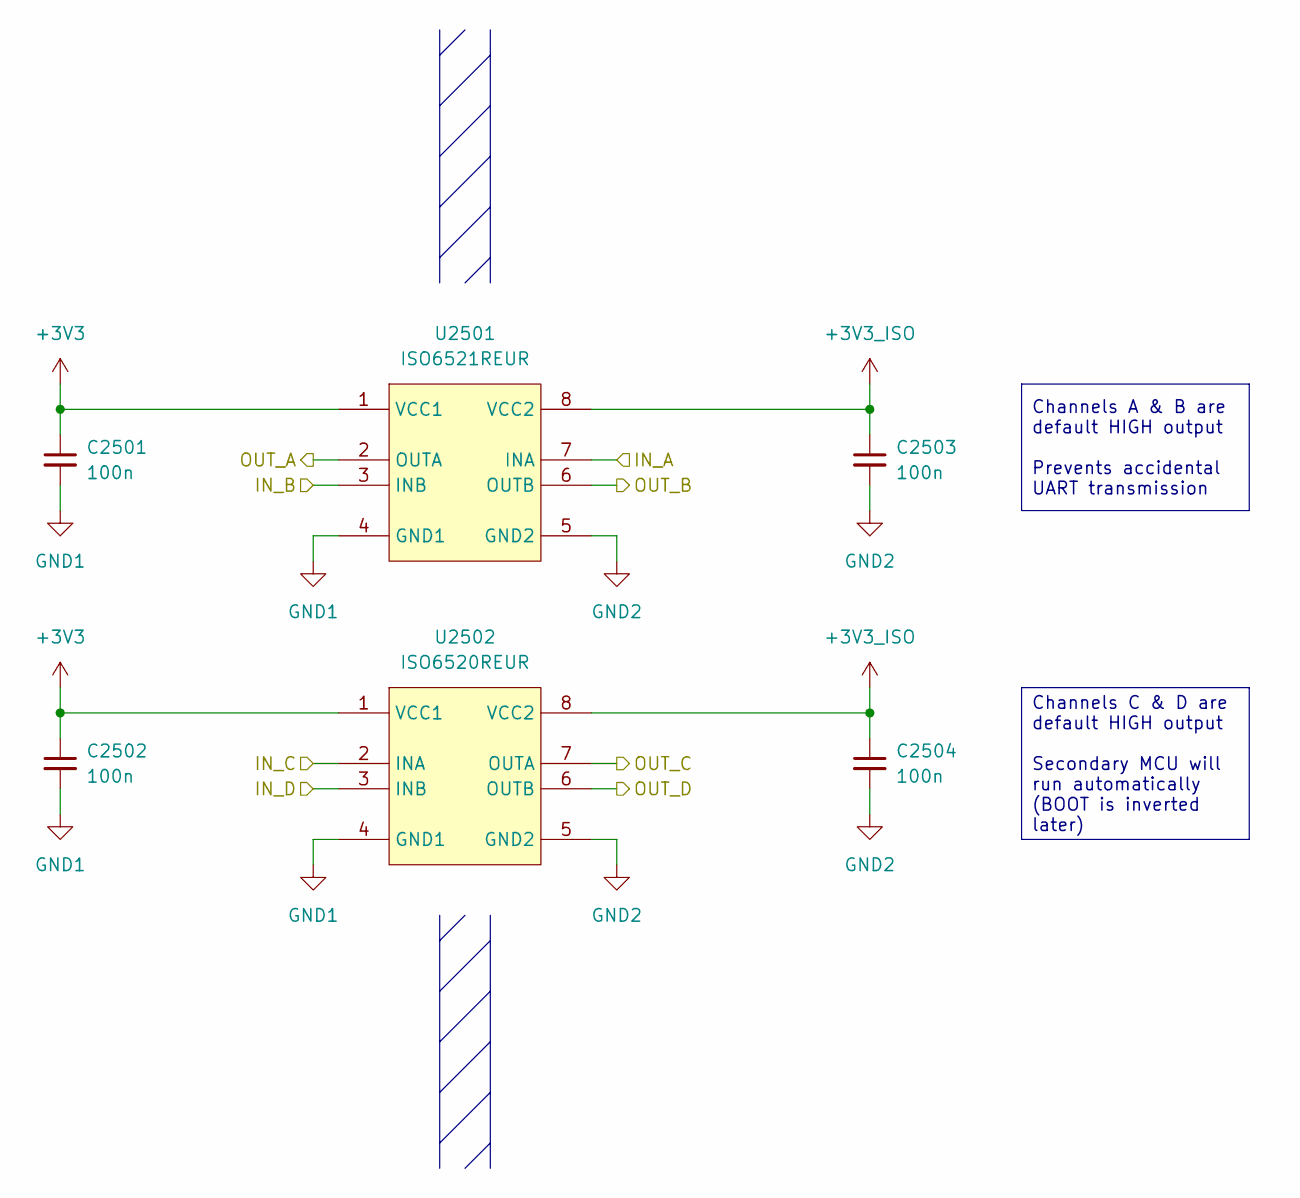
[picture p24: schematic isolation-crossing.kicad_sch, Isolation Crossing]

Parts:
C2501, C2502, C2503, C2504: 100n; C_0402
U2501: ISO6521REUR; SON50P300X200X105-8N-D; Mouser Part Number 595-ISO6521REUR
U2502: ISO6520REUR; SON50P300X200X105-8N-D

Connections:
+3V3: C2501.1, C2502.1, U2501.1 (VCC1), U2502.1 (VCC1); also elsewhere on the board
+3V3_ISO: C2503.1, C2504.1, U2501.8 (VCC2), U2502.8 (VCC2); also elsewhere on the board
/Isolation Crossing/IN_C: U2502.2 (INA); also elsewhere on the board
/Isolation Crossing/IN_D: U2502.3 (INB); also elsewhere on the board
/Isolation Crossing/OUT_C: U2502.7 (OUTA); also elsewhere on the board
/Isolation Crossing/OUT_D: U2502.6 (OUTB); also elsewhere on the board
/Primary MCU/PODL.RX: U2501.2 (OUTA); also elsewhere on the board
/Primary MCU/PODL.TX: U2501.3 (INB); also elsewhere on the board
/Secondary MCU/RX: U2501.6 (OUTB); also elsewhere on the board
/Secondary MCU/TX: U2501.7 (INA); also elsewhere on the board
GND1: C2501.2, C2502.2, U2501.4 (GND1), U2502.4 (GND1); also elsewhere on the board
GND2: C2503.2, C2504.2, U2501.5 (GND2), U2502.5 (GND2); also elsewhere on the board

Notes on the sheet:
Channels C & D are default HIGH output Secondary MCU will run automatically (BOOT is inverted later)
Channels A & B are default HIGH output Prevents accidental UART transmission

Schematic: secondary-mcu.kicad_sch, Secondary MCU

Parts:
C2601, C2602, C2603, C2604: 100n; C_0402
C2605, C2606, C2607: 4u7; C_0402
Q2601, Q2602: DMN21D2UFB-7B; DMN21D2UFB7B; Mouser Part Number 621-DMN21D2UFB-7B
R2601: 47k; R_0402
R2602, R2603: 4k7; R_0402
TP805, TP2601, TP2602, TP2603, TP2604: 1.5mm; TestPoint_Pad_D1.5mm
U2601: STM32H503KBUx; QFN-32-1EP_5x5mm_P0.5mm_EP3.45x3.45mm

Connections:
+2V5_ISO: C2603.1, C2605.1, U2601.5 (VDDA); also elsewhere on the board
+3V3_ISO: C2602.1, C2604.1, C2606.1, Q2602.1 (G), R2601.2, R2602.2, U2601.1 (VDD), U2601.17 (VDD); also elsewhere on the board
/CDNs & PoDL/PODL1.DET_EN: U2601.20 (PA9); also elsewhere on the board
/CDNs & PoDL/PODL1.DET_V+: U2601.10 (PA4); also elsewhere on the board
/CDNs & PoDL/PODL1.EN: U2601.19 (PA8); also elsewhere on the board
/CDNs & PoDL/PODL1.IMON: U2601.9 (PA3); also elsewhere on the board
/CDNs & PoDL/PODL2.DET_EN: U2601.2 (PC14); also elsewhere on the board
/CDNs & PoDL/PODL2.DET_V+: U2601.15 (PB1); also elsewhere on the board
/CDNs & PoDL/PODL2.EN: U2601.22 (PA12); also elsewhere on the board
/CDNs & PoDL/PODL2.IMON: U2601.12 (PA6); also elsewhere on the board
/CDNs & PoDL/PODL3.DET_EN: U2601.29 (PB6); also elsewhere on the board
/CDNs & PoDL/PODL3.DET_V+: U2601.14 (PB0); also elsewhere on the board
/CDNs & PoDL/PODL3.EN: U2601.30 (PB7); also elsewhere on the board
/CDNs & PoDL/PODL3.IMON: U2601.13 (PA7); also elsewhere on the board
/CDNs & PoDL/PODL_DIAG_EN: U2601.21 (PA11); also elsewhere on the board
/Isolation Crossing/OUT_C: Q2601.1 (G); also elsewhere on the board
/Isolation Crossing/OUT_D: Q2602.3 (D); also elsewhere on the board
/Power/2V5_ISO_EN: U2601.7 (PA1); also elsewhere on the board
/Power/3V3_ISO_MODE: U2601.28 (PB5); also elsewhere on the board
/Power/VIN_ISO_IMON: U2601.6 (PA0); also elsewhere on the board
/Power/VIN_ISO_VMON: U2601.8 (PA2); also elsewhere on the board
/Secondary MCU/NRST: C2601.1, R2603.1, TP2603.1 (1_1), U2601.4 (NRST)
/Secondary MCU/RX: U2601.25 (PA15(JTDI)); also elsewhere on the board
/Secondary MCU/SWCLK: TP2602.1 (1_1), U2601.24 (PA14(JTCK))
/Secondary MCU/SWDIO: TP2601.1 (1_1), U2601.23 (PA13(JTMS))
/Secondary MCU/TX: U2601.11 (PA5); also elsewhere on the board
/Secondary MCU/VCAP: C2607.1, U2601.16 (VCAP)
/Secondary MCU/~BOOT: Q2601.3 (D), R2601.1, TP2604.1 (1_1), U2601.31 (BOOT0)
/Secondary MCU/~RST_OD: Q2602.2 (S), R2602.1, R2603.2
GND2: C2601.2, C2602.2, C2603.2, C2604.2, C2605.2, C2606.2, C2607.2, Q2601.2 (S), TP805.1 (1_1), U2601.33 (VSS); also elsewhere on the board

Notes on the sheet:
Invert BOOT so it is LOW by default (flash boot)
Convert ~{RST} from a push-pull signal to an open drain signal (without inversion)

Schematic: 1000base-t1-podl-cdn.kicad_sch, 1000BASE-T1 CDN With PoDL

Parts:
C1901: 100n; C_0402
C1902: 100n; C_0603; Voltage 100V
C1903: 1n; C_0805; Voltage 1kV
D1901: 824012823; Mouser Part Number 710-824012823
D1902, D1903: SZESD7241N2T5G; SZESD7462N2T5G; Mouser Part Number 863-SZESD7241N2T5G
FL1901: ACT1210G-800-2P-TL10; ACT1210G; Mouser Part Number 810-ACT1210G8002PTL1
L1901, L1902: ADL3225VT-4R7M-TL000; ADL3225VT4R7MTL000; Mouser Part Number 810-ADL3225VT4R7MTL0
R1901: 100R; R_0402
T1901: 74930100

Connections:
/CDNs & PoDL/1000BASE-T1 PoDL CDN 1/CTP: C1901.1, T1901.5 (PM)
/CDNs & PoDL/1000BASE-T1 PoDL CDN 1/CTS1: C1902.2, T1901.4 (OUT1B)
/CDNs & PoDL/1000BASE-T1 PoDL CDN 1/CTS2: C1902.1, R1901.2, T1901.3 (OUT2A)
/CDNs & PoDL/1000BASE-T1 PoDL CDN 1/PWR+: L1902.3, L1902.4; also elsewhere on the board
/CDNs & PoDL/1000BASE-T1 PoDL CDN 1/TERM: C1903.1, R1901.1
/CDNs & PoDL/1000BASE-T1 PoDL CDN 1/TRXN: FL1901.2, T1901.2 (IN-)
/CDNs & PoDL/1000BASE-T1 PoDL CDN 1/TRXP: FL1901.1, T1901.1 (IN+)
/CDNs & PoDL/MDI1_IN.TRXN: D1901.1, D1901.6, FL1901.3; also elsewhere on the board
/CDNs & PoDL/MDI1_IN.TRXP: D1901.2, D1901.5, FL1901.4; also elsewhere on the board
/CDNs & PoDL/MDI1_OUT.TRXN: D1903.2 (A2), L1901.1, L1901.2, T1901.7 (OUT2B); also elsewhere on the board
/CDNs & PoDL/MDI1_OUT.TRXP: D1902.2 (A2), L1902.1, L1902.2, T1901.6 (OUT1A); also elsewhere on the board
GND1: C1901.2, D1901.3, D1901.4; also elsewhere on the board
GND2: L1901.3, L1901.4; also elsewhere on the board
SHIELD: C1903.2, D1902.1 (A1), D1903.1 (A1); also elsewhere on the board

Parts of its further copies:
C2001: 100n; C_0402
C2002: 100n; C_0603; Voltage 100V
C2003: 1n; C_0805; Voltage 1kV
D2001: 824012823; Mouser Part Number 710-824012823
D2002, D2003: SZESD7241N2T5G; SZESD7462N2T5G; Mouser Part Number 863-SZESD7241N2T5G
FL2001: ACT1210G-800-2P-TL10; ACT1210G; Mouser Part Number 810-ACT1210G8002PTL1
L2001, L2002: ADL3225VT-4R7M-TL000; ADL3225VT4R7MTL000; Mouser Part Number 810-ADL3225VT4R7MTL0
R2001: 100R; R_0402
T2001: 74930100

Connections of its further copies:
/CDNs & PoDL/1000BASE-T1 PoDL CDN 2/CTP: C2001.1, T2001.5 (PM)
/CDNs & PoDL/1000BASE-T1 PoDL CDN 2/CTS1: C2002.2, T2001.4 (OUT1B)
/CDNs & PoDL/1000BASE-T1 PoDL CDN 2/CTS2: C2002.1, R2001.2, T2001.3 (OUT2A)
/CDNs & PoDL/1000BASE-T1 PoDL CDN 2/PWR+: L2002.3, L2002.4; also elsewhere on the board
/CDNs & PoDL/1000BASE-T1 PoDL CDN 2/TERM: C2003.1, R2001.1
/CDNs & PoDL/1000BASE-T1 PoDL CDN 2/TRXN: FL2001.2, T2001.2 (IN-)
/CDNs & PoDL/1000BASE-T1 PoDL CDN 2/TRXP: FL2001.1, T2001.1 (IN+)
/CDNs & PoDL/MDI2_IN.TRXN: D2001.1, D2001.6, FL2001.3; also elsewhere on the board
/CDNs & PoDL/MDI2_IN.TRXP: D2001.2, D2001.5, FL2001.4; also elsewhere on the board
/CDNs & PoDL/MDI2_OUT.TRXN: D2003.2 (A2), L2001.1, L2001.2, T2001.7 (OUT2B); also elsewhere on the board
/CDNs & PoDL/MDI2_OUT.TRXP: D2002.2 (A2), L2002.1, L2002.2, T2001.6 (OUT1A); also elsewhere on the board
GND1: C2001.2, D2001.3, D2001.4; also elsewhere on the board
GND2: L2001.3, L2001.4; also elsewhere on the board
SHIELD: C2003.2, D2002.1 (A1), D2003.1 (A1); also elsewhere on the board

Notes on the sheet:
CMC
2x 100mΩ 720mA Max
Can also use LQH32NH3R3J23L
Termination
ESD Protection

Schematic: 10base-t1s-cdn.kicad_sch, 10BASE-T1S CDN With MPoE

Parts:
C2101: 100n; C_0402
C2102: 100n; C_0603; Voltage 100V
C2103: 1n; C_0805; Voltage 1kV
D2101: 824012823; Mouser Part Number 710-824012823
D2102, D2103: SZESD7241N2T5G; SZESD7462N2T5G; Mouser Part Number 863-SZESD7241N2T5G
FL2101: ACT1210E-131-2P-TL00; ACT1210E; Mouser Part Number 810-ACT1210E1312PTL0
L2101: MSD7342-333MLC_DM; MSD7342
L2102: MSD7342-333MLC; MSD7342
R2101: 3k3; R_0402
T2101: 74930100

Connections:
/CDNs & PoDL/10BASE-T1S CDN/CTP: C2101.1, T2101.5 (PM)
/CDNs & PoDL/10BASE-T1S CDN/CTS1: C2102.2, T2101.4 (OUT1B)
/CDNs & PoDL/10BASE-T1S CDN/CTS2: C2102.1, R2101.2, T2101.3 (OUT2A)
/CDNs & PoDL/10BASE-T1S CDN/MDI_PWR+: L2101.4 (2), L2102.3
/CDNs & PoDL/10BASE-T1S CDN/MDI_PWR-: L2101.1, L2102.4 (2)
/CDNs & PoDL/10BASE-T1S CDN/PWR+: L2102.1; also elsewhere on the board
/CDNs & PoDL/10BASE-T1S CDN/TERM: C2103.1, R2101.1
/CDNs & PoDL/10BASE-T1S CDN/TRXN: FL2101.2, T2101.2 (IN-)
/CDNs & PoDL/10BASE-T1S CDN/TRXP: FL2101.1, T2101.1 (IN+)
/CDNs & PoDL/MDI3_IN.TRXN: D2101.1, D2101.6, FL2101.3; also elsewhere on the board
/CDNs & PoDL/MDI3_IN.TRXP: D2101.2, D2101.5, FL2101.4; also elsewhere on the board
/CDNs & PoDL/MDI3_OUT.TRXN: D2103.2 (A2), L2101.3, T2101.7 (OUT2B); also elsewhere on the board
/CDNs & PoDL/MDI3_OUT.TRXP: D2102.2 (A2), L2101.2 (4), T2101.6 (OUT1A); also elsewhere on the board
GND1: C2101.2, D2101.3, D2101.4; also elsewhere on the board
GND2: L2102.2 (4); also elsewhere on the board
SHIELD: C2103.2, D2102.1 (A1), D2103.1 (A1); also elsewhere on the board

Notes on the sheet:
ESD Protection
Change termination resistor to 100Ω for end node
CMC
Termination
4x 270mΩ 760mA Max

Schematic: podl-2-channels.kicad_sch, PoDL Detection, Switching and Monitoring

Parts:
C2201, C2202: 100n; C_0402
D2201, D2202: PMEG4002EL-QYL
Q2201, Q2202, Q2204, Q2206: DMP21D0UFB-7B; DMP21D0UFB7B; Mouser Part Number 621-DMP21D0UFB-7B
Q2203, Q2205: DMN21D2UFB-7B; DMN21D2UFB7B; Mouser Part Number 621-DMN21D2UFB-7B
R2201, R2202, R2203, R2204, R2213, R2214, R2215, R2216: 4k7; R_0402
R2205: 470R; R_0402
R2206, R2210, R2217, R2221: 2k2; R_0402
R2207, R2209, R2212, R2218, R2220, R2223: 10k; R_0402
R2208, R2219: 1k; R_0402
R2211, R2222: 100k; R_0402
U2201, U2202: TPS27S100BRRK; TPS27S100ARRKR
Z2201, Z2202: BZX884-C3V3,315; BZX884; Mouser Part Number 771-BZX884-C3V9315

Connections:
+6V5_ISO: Q2201.2 (S), Q2202.2 (S), R2209.1, R2220.1; also elsewhere on the board
+VIN_ISO: U2201.9 (IN), U2201.10 (IN), U2201.11 (IN), U2201.12 (IN), U2202.9 (IN), U2202.10 (IN), U2202.11 (IN), U2202.12 (IN); also elsewhere on the board
/CDNs & PoDL/1000BASE-T1 PoDL CDN 1/PWR+: D2201.1 (K), R2211.1, U2201.5 (OUT), U2201.6 (OUT), U2201.7 (OUT), U2201.8 (OUT); also elsewhere on the board
/CDNs & PoDL/1000BASE-T1 PoDL CDN 2/PWR+: D2202.1 (K), R2222.1, U2202.5 (OUT), U2202.6 (OUT), U2202.7 (OUT), U2202.8 (OUT); also elsewhere on the board
/CDNs & PoDL/PODL1.DET_EN: R2207.1, R2208.1; also elsewhere on the board
/CDNs & PoDL/PODL1.DET_V+: R2211.2, R2212.1, Z2201.1 (K); also elsewhere on the board
/CDNs & PoDL/PODL1.EN: R2202.1; also elsewhere on the board
/CDNs & PoDL/PODL1.IMON: C2201.1, R2201.2, R2204.1; also elsewhere on the board
/CDNs & PoDL/PODL2.DET_EN: R2218.1, R2219.1; also elsewhere on the board
/CDNs & PoDL/PODL2.DET_V+: R2222.2, R2223.1, Z2202.1 (K); also elsewhere on the board
/CDNs & PoDL/PODL2.EN: R2214.1; also elsewhere on the board
/CDNs & PoDL/PODL2.IMON: C2202.1, R2213.2, R2216.1; also elsewhere on the board
/CDNs & PoDL/PODL_DIAG_EN: R2203.1, R2215.1; also elsewhere on the board
/CDNs & PoDL/PoDL (2 Channels)/CURRENT_MIRROR_GATE: Q2201.1 (G), Q2201.3 (D), Q2202.1 (G), R2205.1
/CDNs & PoDL/PoDL (2 Channels)/CURRENT_MIRROR_OUT: Q2202.3 (D), Q2204.2 (S), Q2206.2 (S)
/CDNs & PoDL/PoDL (2 Channels)/DIAG_EN1: R2203.2, U2201.14 (DIAG_EN)
/CDNs & PoDL/PoDL (2 Channels)/DIAG_EN2: R2215.2, U2202.14 (DIAG_EN)
/CDNs & PoDL/PoDL (2 Channels)/EN1: R2202.2, U2201.3 (EN)
/CDNs & PoDL/PoDL (2 Channels)/EN2: R2214.2, U2202.3 (EN)
/CDNs & PoDL/PoDL (2 Channels)/G1: Q2203.1 (G), R2208.2
/CDNs & PoDL/PoDL (2 Channels)/G2: Q2203.3 (D), Q2204.1 (G), R2209.2
/CDNs & PoDL/PoDL (2 Channels)/G3: Q2205.1 (G), R2219.2
/CDNs & PoDL/PoDL (2 Channels)/G4: Q2205.3 (D), Q2206.1 (G), R2220.2
/CDNs & PoDL/PoDL (2 Channels)/ILIM1: R2210.2, U2201.15 (ILIM)
/CDNs & PoDL/PoDL (2 Channels)/ILIM2: R2221.2, U2202.15 (ILIM)
/CDNs & PoDL/PoDL (2 Channels)/IMON1: R2204.2, R2206.2, U2201.16 (IMON)
/CDNs & PoDL/PoDL (2 Channels)/IMON2: R2216.2, R2217.2, U2202.16 (IMON)
/CDNs & PoDL/PoDL (2 Channels)/I_PODL1: D2201.2 (A), Q2204.3 (D)
/CDNs & PoDL/PoDL (2 Channels)/I_PODL2: D2202.2 (A), Q2206.3 (D)
GND2: C2201.2, C2202.2, Q2203.2 (S), Q2205.2 (S), R2201.1, R2205.2, R2206.1, R2207.2, R2210.1, R2212.2, R2213.1, R2217.1, R2218.2, R2221.1, R2223.2, U2201.2 (GND), U2201.17 (EP), U2202.2 (GND), U2202.17 (EP), Z2201.2 (A), Z2202.2 (A); also elsewhere on the board

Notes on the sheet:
Power Switch 2
Current Source (Mirror)
Current Switches
Power Switch 1
1.1A Maximum output current 1.1A Maximum measurable current
If the output is shorted the current is still limited to 14mA, and 91mW will be dissapated (in spec)
Each channel can be enabled individually to check for PoDL devices. Since the outputs share a current source, only one channel can be checked at a time.
I_{OUT} = 0.28046 * V_{MON}
6.5 / 470 = ~14mA Within the 9-16mA PoDL spec
1/11 Potential divider and zener clamp to protect the 3V3 microcontroller IO.
During the detection phase, 9-16mA is sent into TRXP and the resulting voltage is measured. If a PoDL compatible device is detected on the other end (indicated by a 4.05-4.55V zener diode) then the full 24V is enabled.
IMON can go up to 4.75V, potential divider limits this to be withing 2.5V ADC range.

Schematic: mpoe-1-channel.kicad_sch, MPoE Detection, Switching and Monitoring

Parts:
C2301, C2302: 100n; C_0402
D2301: PMEG4002EL-QYL
F2301: 0603L008YR; Fuse_0603_1608Metric
Q2301: DMN21D2UFB-7B; DMN21D2UFB7B; Mouser Part Number 621-DMN21D2UFB-7B
Q2302: DMP21D0UFB-7B; DMP21D0UFB7B; Mouser Part Number 621-DMP21D0UFB-7B
R2301: 10k; R_0402
R2302: 1k; R_0402
R2303: 100k; R_0402
R2304, R2306, R2307, R2308: 4k7; R_0402
R2305: 1R; R_0402
R2309, R2310: 2k2; R_0402
U2301: NCS213RMUTAG; Mouser Part Number 863-NCS213RMUTAG
U2302: TPS27S100BRRK; TPS27S100ARRKR

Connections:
+2V5_ISO: C2302.2, U2301.6 (VS); also elsewhere on the board
+6V5_ISO: Q2302.2 (S), R2303.2; also elsewhere on the board
+VIN_ISO: U2302.9 (IN), U2302.10 (IN), U2302.11 (IN), U2302.12 (IN); also elsewhere on the board
/CDNs & PoDL/10BASE-T1S CDN/PWR+: D2301.1 (K), U2302.5 (OUT), U2302.6 (OUT), U2302.7 (OUT), U2302.8 (OUT); also elsewhere on the board
/CDNs & PoDL/MPoE (1 Channel)/DET: Q2301.1 (G), R2302.1
/CDNs & PoDL/MPoE (1 Channel)/DET+: Q2302.3 (D), R2305.1, U2301.2 (IN+), U2301.3 (IN+)
/CDNs & PoDL/MPoE (1 Channel)/DET-: F2301.2, R2305.2, U2301.4 (IN-), U2301.5 (IN-)
/CDNs & PoDL/MPoE (1 Channel)/DET_FUSED: D2301.2 (A), F2301.1
/CDNs & PoDL/MPoE (1 Channel)/DIAG_EN: R2307.2, U2302.14 (DIAG_EN)
/CDNs & PoDL/MPoE (1 Channel)/EN: R2306.2, U2302.3 (EN)
/CDNs & PoDL/MPoE (1 Channel)/ILIM: R2310.2, U2302.15 (ILIM)
/CDNs & PoDL/MPoE (1 Channel)/IMON: R2308.2, R2309.2, U2302.16 (IMON)
/CDNs & PoDL/MPoE (1 Channel)/~DET: Q2301.3 (D), Q2302.1 (G), R2303.1
/CDNs & PoDL/PODL3.DET_EN: R2301.2, R2302.2; also elsewhere on the board
/CDNs & PoDL/PODL3.DET_V+: U2301.10 (OUT); also elsewhere on the board
/CDNs & PoDL/PODL3.EN: R2306.1; also elsewhere on the board
/CDNs & PoDL/PODL3.IMON: C2301.1, R2304.2, R2308.1; also elsewhere on the board
/CDNs & PoDL/PODL_DIAG_EN: R2307.1; also elsewhere on the board
GND2: C2301.2, C2302.1, Q2301.2 (S), R2301.1, R2304.1, R2309.1, R2310.1, U2301.8 (REF), U2301.9 (GND), U2302.2 (GND), U2302.17 (EP); also elsewhere on the board

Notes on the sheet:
IMON can go up to 4.75V, potential divider limits this to be withing 2.5V ADC range.
Fuse protects against short circuit output
During detection, the bus is powered at 6.5V, and each PD draws 1mA for every watt they require. This is detected as a voltage drop across the 1 ohm resistor.
1.1A Maximum output current 1.1A Maximum measurable current
I_{OUT} = 0.28046 * V_{MON}

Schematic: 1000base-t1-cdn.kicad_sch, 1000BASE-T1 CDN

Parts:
C1801: 100n; C_0402
C1802: 100n; C_0603; Voltage 100V
C1803: 1n; C_0805; Voltage 1kV
D1801: 824012823; Mouser Part Number 710-824012823
D1802, D1803: SZESD7241N2T5G; SZESD7462N2T5G; Mouser Part Number 863-SZESD7241N2T5G
FL1801: ACT1210G-800-2P-TL10; ACT1210G; Mouser Part Number 810-ACT1210G8002PTL1
R1801: 100R; R_0402
T1801: 74930100

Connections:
/CDNs & PoDL/1000BASE-T1 CDN/CTP: C1801.1, T1801.5 (PM)
/CDNs & PoDL/1000BASE-T1 CDN/CTS1: C1802.2, T1801.4 (OUT1B)
/CDNs & PoDL/1000BASE-T1 CDN/CTS2: C1802.1, R1801.2, T1801.3 (OUT2A)
/CDNs & PoDL/1000BASE-T1 CDN/TERM: C1803.1, R1801.1
/CDNs & PoDL/1000BASE-T1 CDN/TRXN: FL1801.2, T1801.2 (IN-)
/CDNs & PoDL/1000BASE-T1 CDN/TRXP: FL1801.1, T1801.1 (IN+)
/CDNs & PoDL/MDI0_IN.TRXN: D1801.1, D1801.6, FL1801.3; also elsewhere on the board
/CDNs & PoDL/MDI0_IN.TRXP: D1801.2, D1801.5, FL1801.4; also elsewhere on the board
/CDNs & PoDL/MDI0_OUT.TRXN: D1803.2 (A2), T1801.7 (OUT2B); also elsewhere on the board
/CDNs & PoDL/MDI0_OUT.TRXP: D1802.2 (A2), T1801.6 (OUT1A); also elsewhere on the board
GND1: C1801.2, D1801.3, D1801.4; also elsewhere on the board
SHIELD0: C1803.2, D1802.1 (A1), D1803.1 (A1); also elsewhere on the board

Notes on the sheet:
Termination
ESD Protection
CMC

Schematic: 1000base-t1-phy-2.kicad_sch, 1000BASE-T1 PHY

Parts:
C1501, C1502, C1505, C1506, C1507: 4u7; C_0402
C1503: 22p; C_0402
C1504, C1508, C1509, C1510, C1511, C1513, C1514, C1515, C1516, C1517, C1518, C1519, C1520: 100n; C_0402
C1512, C1521: 10u; C_0402
C1522: 10u; C_0402; not fitted
L1501: 78438313015; L_Wurth_WE-MAIA-1610; Part Number 78438313015
Q1501: DMN21D2UFB-7B; DMN21D2UFB7B; Mouser Part Number 621-DMN21D2UFB-7B
Q1502: DMP21D0UFB-7B; DMP21D0UFB7B; Mouser Part Number 621-DMP21D0UFB-7B
R1501, R1503: 4k7; R_0402
R1502: 10k; R_0402; not fitted
R1504: 4k7; R_0402; not fitted
R1505: 180k; R_0402
R1506: 360k; R_0402
R1507: 4k99; R_0402
R1508: 1k; R_0402
R1509: 47k; R_0402
TP1501, TP1502: 1.5mm; TestPoint_Pad_D1.5mm
U1501: TPS62290TDRVRQ1; SON65P200X200X80-7N; Mouser Part Number 595-TPS62290TDRVRQ1
U1502: 88Q2112-A2-NYD2A000-P123; 88Q2112

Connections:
+1V8: C1509.1, C1511.1, C1512.1, C1513.1, C1515.1, C1517.1, C1519.1, C1521.1, R1502.2, U1502.9 (AVDD18), U1502.24 (VDDO), U1502.33 (AVDD18), U1502.40 (VDDO); also elsewhere on the board
+3V3: C1501.1, C1502.1, C1508.1, C1510.1, U1501.2 (MODE), U1501.5 (VIN), U1502.6 (AVDD33); also elsewhere on the board
+3V3_AON: C1514.1, Q1502.2 (S), R1509.2, U1502.46 (VLPR); also elsewhere on the board
/CDNs & PoDL/MDI2_IN.TRXN: U1502.5 (MDIN); also elsewhere on the board
/CDNs & PoDL/MDI2_IN.TRXP: U1502.4 (MDIP); also elsewhere on the board
/PHYs/1000BASE-T1 PHY 0/INH: Q1502.3 (D), U1501.4 (EN); also elsewhere on the board
/PHYs/1000BASE-T1 PHY 0/MDC: U1502.38 (MDC); also elsewhere on the board
/PHYs/1000BASE-T1 PHY 0/MDIO: U1502.39 (MDIO); also elsewhere on the board
/PHYs/1000BASE-T1 PHY 0/~RST: U1502.36 (~RST); also elsewhere on the board
/PHYs/1000BASE-T1 PHY 2/0V9: C1503.1, C1505.1, C1506.1, C1507.1, C1516.1, C1518.1, C1520.1, C1522.1, L1501.2, R1505.1, TP1501.1 (1_1), U1502.17 (DVDD), U1502.43 (DVDD)
/PHYs/1000BASE-T1 PHY 2/CLKIN: C1504.2; also elsewhere on the board
/PHYs/1000BASE-T1 PHY 2/FB: C1503.2, R1505.2, R1506.1, U1501.3 (FB)
/PHYs/1000BASE-T1 PHY 2/GPIO: R1504.2, U1502.42 (GPIO/PHYAD2)
/PHYs/1000BASE-T1 PHY 2/INH_G: Q1501.1 (G), R1508.1
/PHYs/1000BASE-T1 PHY 2/INH_OUT: R1508.2, U1502.45 (INH)
/PHYs/1000BASE-T1 PHY 2/RSET: R1507.2, U1502.1 (RSET)
/PHYs/1000BASE-T1 PHY 2/SW: L1501.1, U1501.1 (SW)
/PHYs/1000BASE-T1 PHY 2/XTAL_IN: C1504.1, U1502.12 (XTAL_IN)
/PHYs/1000BASE-T1 PHY 2/~INH: Q1501.3 (D), Q1502.1 (G), R1509.1
/PHYs/WAKE: U1502.44 (WAKE_IN); also elsewhere on the board
/PHYs/xMII2.RX_CLK: U1502.23 (RCLK); also elsewhere on the board
/PHYs/xMII2.RX_CTL: R1503.2, U1502.22 (RXC); also elsewhere on the board
/PHYs/xMII2.RX_D0: U1502.21 (RXD0/PHYAD0); also elsewhere on the board
/PHYs/xMII2.RX_D1: R1501.2, U1502.20 (RXD1/PHYAD1); also elsewhere on the board
/PHYs/xMII2.RX_D2: U1502.19 (RXD2/MODE0); also elsewhere on the board
/PHYs/xMII2.RX_D3: U1502.18 (RXD3/MODE1); also elsewhere on the board
/PHYs/xMII2.TX_CLK: U1502.25 (TCLK); also elsewhere on the board
/PHYs/xMII2.TX_CTL: U1502.26 (TXC); also elsewhere on the board
/PHYs/xMII2.TX_D0: U1502.27 (TXD0); also elsewhere on the board
/PHYs/xMII2.TX_D1: U1502.28 (TXD1); also elsewhere on the board
/PHYs/xMII2.TX_D2: U1502.29 (TXD2); also elsewhere on the board
/PHYs/xMII2.TX_D3: U1502.30 (TXD3); also elsewhere on the board
/PHYs/~PHY2_INT: R1502.1, U1502.37 (~INT); also elsewhere on the board
GND1: C1501.2, C1502.2, C1505.2, C1506.2, C1507.2, C1508.2, C1509.2, C1510.2, C1511.2, C1512.2, C1513.2, C1514.2, C1515.2, C1516.2, C1517.2, C1518.2, C1519.2, C1520.2, C1521.2, C1522.2, Q1501.2 (S), R1501.1, R1503.1, R1504.1, R1506.2, R1507.1, TP1502.1 (1_1), U1501.6 (GND), U1501.7 (EP), U1502.11 (VSSC), U1502.49 (VSS); also elsewhere on the board

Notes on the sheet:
AVDD18: 145mA Typ 152mA Max
RSET Must be 1% tolerance
Use high quality, low ESR (<50mΩ) capacitors such as GRM155R61A475ME02
Populating strapping pulldowns means that bit of the PHY address or mode will be 1.
AVDD33: 25mA Typ 27mA Max
VDDO: 18.6mA Typ
DVDD: 202mA Typ 359mA Max
This INH circuit is non-standard, and requires testing.
MODE[1:0] = 0x00 means the PHY will start as a 100BASE-T1 master, 0x01 means 100BASE-T1 slave.
Maximum allowed noise on any supply is 50mV peak to peak
Internal GPIO pullups needed for ~{INT}.

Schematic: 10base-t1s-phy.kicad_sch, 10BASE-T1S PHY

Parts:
C1601, C1602, C1603: 10u; C_0402
C1604, C1605, C1606, C1610: 100n; C_0402
C1607, C1608, C1609, C1611: 10n; C_0402
R1601, R1602, R1604, R1605, R1606, R1607: 10k; R_0402
R1603: 10k; R_0402; not fitted
R1608: 12k4; R_0402
U1601: LAN8671C2-E_U3B; QFN50P400X400X100-25N-D; Mouser Part Number 579-LAN8671C2-E/U3B

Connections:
+3V3: C1601.1, C1602.1, C1604.1, C1605.1, C1607.1, C1608.1, C1610.1, C1611.1, R1601.1, R1603.1, R1605.1, U1601.6 (VDDP_1), U1601.13 (VDDP_2), U1601.22 (VDDA); also elsewhere on the board
+3V3_AON: C1603.1, C1606.1, C1609.1, U1601.18 (VDDAU); also elsewhere on the board
/CDNs & PoDL/MDI3_IN.TRXN: U1601.24 (TRXN); also elsewhere on the board
/CDNs & PoDL/MDI3_IN.TRXP: U1601.23 (TRXP); also elsewhere on the board
/PHYs/10BASE-T1S PHY/PTP_TS: U1601.7 (GPIO0)
/PHYs/10BASE-T1S PHY/RBIAS: R1608.1, U1601.19 (RBIAS)
/PHYs/10BASE-T1S PHY/WAKE_OUT: U1601.17 (WAKE_OUT)
/PHYs/1000BASE-T1 PHY 0/INH: U1601.2 (INH); also elsewhere on the board
/PHYs/MDC: U1601.9 (MDC); also elsewhere on the board
/PHYs/MDIO: U1601.10 (MDIO); also elsewhere on the board
/PHYs/WAKE: U1601.1 (WAKE_IN); also elsewhere on the board
/PHYs/xMII3.RX_CRS_DV: R1607.1, U1601.14 (CRSDV/PHYAD1); also elsewhere on the board
/PHYs/xMII3.RX_D0: R1604.1, U1601.11 (RXD0/PHYAD2); also elsewhere on the board
/PHYs/xMII3.RX_D1: R1605.2, U1601.12 (RXD1/PHYAD3); also elsewhere on the board
/PHYs/xMII3.RX_ER: R1606.1, U1601.15 (RXER/PHYAD0); also elsewhere on the board
/PHYs/xMII3.TX_D0: U1601.4 (TXD0); also elsewhere on the board
/PHYs/xMII3.TX_D1: U1601.3 (TXD1); also elsewhere on the board
/PHYs/xMII3.TX_EN: R1602.1, U1601.5 (TXEN); also elsewhere on the board
/PHYs/xMII3_REF_CLK: U1601.20 (REFCLKIN); also elsewhere on the board
/PHYs/~PHY3_INT: R1601.2, U1601.16 (IRQ_N); also elsewhere on the board
/PHYs/~RST: R1603.2, U1601.8 (RESET_N); also elsewhere on the board
GND1: C1601.2, C1602.2, C1603.2, C1604.2, C1605.2, C1606.2, C1607.2, C1608.2, C1609.2, C1610.2, C1611.2, R1602.2, R1604.2, R1606.2, R1607.2, R1608.2, U1601.25 (VSS); also elsewhere on the board

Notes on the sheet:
VDDA: 34mA Typ 41mA Max
PHY_ADDR = 0x0008
VDDP: 4mA Typ
The first time VDDAU is powered up it asserts INH (HIGH).
VDDAU: 0.57mA Typ
RBIAS must be +-1%

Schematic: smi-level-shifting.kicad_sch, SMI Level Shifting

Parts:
Q1101, Q1102, Q1103: DMN21D2UFB-7B; DMN21D2UFB7B; Mouser Part Number 621-DMN21D2UFB-7B
R1101, R1102, R1104, R1105: 1k5; R_0402
R1103, R1106: 10k; R_0402
TP1101, TP1102: 1.5mm; TestPoint_Pad_D1.5mm

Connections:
+1V8: Q1101.1 (G), Q1102.1 (G), Q1103.1 (G), R1104.2, R1105.2, R1106.2; also elsewhere on the board
+3V3: R1101.2, R1102.2, R1103.2; also elsewhere on the board
/PHYs/1000BASE-T1 PHY 0/MDC: Q1101.2 (S), R1104.1, TP1102.1 (1_1); also elsewhere on the board
/PHYs/1000BASE-T1 PHY 0/MDIO: Q1102.2 (S), R1105.1, TP1101.1 (1_1); also elsewhere on the board
/PHYs/1000BASE-T1 PHY 0/~RST: Q1103.2 (S), R1106.1; also elsewhere on the board
/PHYs/MDC: Q1101.3 (D), R1101.1; also elsewhere on the board
/PHYs/MDIO: Q1102.3 (D), R1102.1; also elsewhere on the board
/PHYs/~RST: Q1103.3 (D), R1103.1; also elsewhere on the board

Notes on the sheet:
The 1000BASE-T1 PHYs operate at a 1V8 logic level (to save RGMII power), but the SMI and ~{RST} pins operate at a 3V3 logic level. Level shifting is used to allow communication.

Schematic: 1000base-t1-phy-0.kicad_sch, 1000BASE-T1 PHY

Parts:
C1301, C1302, C1305, C1306, C1307: 4u7; C_0402
C1303: 22p; C_0402
C1304, C1308, C1309, C1310, C1311, C1313, C1314, C1315, C1316, C1317, C1318, C1319, C1320: 100n; C_0402
C1312, C1321: 10u; C_0402
C1322: 10u; C_0402; not fitted
L1301: 78438313015; L_Wurth_WE-MAIA-1610; Part Number 78438313015
Q1301: DMN21D2UFB-7B; DMN21D2UFB7B; Mouser Part Number 621-DMN21D2UFB-7B
Q1302: DMP21D0UFB-7B; DMP21D0UFB7B; Mouser Part Number 621-DMP21D0UFB-7B
R1301, R1310: 4k7; R_0402
R1302: 10k; R_0402; not fitted
R1304: 4k7; R_0402; not fitted
R1305: 180k; R_0402
R1306: 360k; R_0402
R1307: 4k99; R_0402
R1308: 1k; R_0402
R1309: 47k; R_0402
TP1301, TP1302: 1.5mm; TestPoint_Pad_D1.5mm
U1301: TPS62290TDRVRQ1; SON65P200X200X80-7N; Mouser Part Number 595-TPS62290TDRVRQ1
U1302: 88Q2112-A2-NYD2A000-P123; 88Q2112

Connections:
+1V8: C1309.1, C1311.1, C1312.1, C1313.1, C1315.1, C1317.1, C1319.1, C1321.1, R1302.2, U1302.9 (AVDD18), U1302.24 (VDDO), U1302.33 (AVDD18), U1302.40 (VDDO); also elsewhere on the board
+3V3: C1301.1, C1302.1, C1308.1, C1310.1, U1301.2 (MODE), U1301.5 (VIN), U1302.6 (AVDD33); also elsewhere on the board
+3V3_AON: C1314.1, Q1302.2 (S), R1309.2, U1302.46 (VLPR); also elsewhere on the board
/CDNs & PoDL/MDI0_IN.TRXN: U1302.5 (MDIN); also elsewhere on the board
/CDNs & PoDL/MDI0_IN.TRXP: U1302.4 (MDIP); also elsewhere on the board
/PHYs/1000BASE-T1 PHY 0/0V9: C1303.1, C1305.1, C1306.1, C1307.1, C1316.1, C1318.1, C1320.1, L1301.2, R1305.1, TP1301.1 (1_1), U1302.17 (DVDD), U1302.43 (DVDD)
/PHYs/1000BASE-T1 PHY 0/CLKIN: C1304.2; also elsewhere on the board
/PHYs/1000BASE-T1 PHY 0/FB: C1303.2, R1305.2, R1306.1, U1301.3 (FB)
/PHYs/1000BASE-T1 PHY 0/GPIO: U1302.42 (GPIO/PHYAD2)
/PHYs/1000BASE-T1 PHY 0/INH: Q1302.3 (D), U1301.4 (EN); also elsewhere on the board
/PHYs/1000BASE-T1 PHY 0/INH_G: Q1301.1 (G), R1308.1
/PHYs/1000BASE-T1 PHY 0/INH_OUT: R1308.2, U1302.45 (INH)
/PHYs/1000BASE-T1 PHY 0/MDC: U1302.38 (MDC); also elsewhere on the board
/PHYs/1000BASE-T1 PHY 0/MDIO: U1302.39 (MDIO); also elsewhere on the board
/PHYs/1000BASE-T1 PHY 0/RSET: R1307.2, U1302.1 (RSET)
/PHYs/1000BASE-T1 PHY 0/SW: L1301.1, U1301.1 (SW)
/PHYs/1000BASE-T1 PHY 0/XTAL_IN: C1304.1, U1302.12 (XTAL_IN)
/PHYs/1000BASE-T1 PHY 0/~INH: Q1301.3 (D), Q1302.1 (G), R1309.1
/PHYs/1000BASE-T1 PHY 0/~RST: U1302.36 (~RST); also elsewhere on the board
/PHYs/WAKE: U1302.44 (WAKE_IN); also elsewhere on the board
/PHYs/xMII0.RX_CLK: U1302.23 (RCLK); also elsewhere on the board
/PHYs/xMII0.RX_CTL: R1301.2, U1302.22 (RXC); also elsewhere on the board
/PHYs/xMII0.RX_D0: U1302.21 (RXD0/PHYAD0); also elsewhere on the board
/PHYs/xMII0.RX_D1: U1302.20 (RXD1/PHYAD1); also elsewhere on the board
/PHYs/xMII0.RX_D2: R1310.2, U1302.19 (RXD2/MODE0); also elsewhere on the board
/PHYs/xMII0.RX_D3: U1302.18 (RXD3/MODE1); also elsewhere on the board
/PHYs/xMII0.TX_CLK: U1302.25 (TCLK); also elsewhere on the board
/PHYs/xMII0.TX_CTL: U1302.26 (TXC); also elsewhere on the board
/PHYs/xMII0.TX_D0: U1302.27 (TXD0); also elsewhere on the board
/PHYs/xMII0.TX_D1: U1302.28 (TXD1); also elsewhere on the board
/PHYs/xMII0.TX_D2: U1302.29 (TXD2); also elsewhere on the board
/PHYs/xMII0.TX_D3: U1302.30 (TXD3); also elsewhere on the board
/PHYs/~PHY0_INT: U1302.37 (~INT); also elsewhere on the board
GND1: C1301.2, C1302.2, C1305.2, C1306.2, C1307.2, C1308.2, C1309.2, C1310.2, C1311.2, C1312.2, C1313.2, C1314.2, C1315.2, C1316.2, C1317.2, C1318.2, C1319.2, C1320.2, C1321.2, C1322.2, Q1301.2 (S), R1301.1, R1304.1, R1306.2, R1307.1, R1310.1, TP1302.1 (1_1), U1301.6 (GND), U1301.7 (EP), U1302.11 (VSSC), U1302.49 (VSS); also elsewhere on the board

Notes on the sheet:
AVDD18: 145mA Typ 152mA Max
RSET Must be 1% tolerance
Use high quality, low ESR (<50mΩ) capacitors such as GRM155R61A475ME02
Internal GPIO pullups needed for ~{INT}.
Populating strapping pulldowns means that bit of the PHY address or mode will be 1.
AVDD33: 25mA Typ 27mA Max
VDDO: 18.6mA Typ
DVDD: 202mA Typ 359mA Max
This INH circuit is non-standard, and requires testing.
MODE[1:0] = 0x00 means the PHY will start as a 100BASE-T1 master, 0x01 means 100BASE-T1 slave.
Maximum allowed noise on any supply is 50mV peak to peak

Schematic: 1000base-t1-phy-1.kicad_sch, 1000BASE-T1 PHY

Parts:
C1401, C1402, C1405, C1406, C1407: 4u7; C_0402
C1403: 22p; C_0402
C1404, C1408, C1409, C1410, C1411, C1413, C1414, C1415, C1416, C1417, C1418, C1419, C1420: 100n; C_0402
C1412, C1421: 10u; C_0402
C1422: 10u; C_0402; not fitted
L1401: 78438313015; L_Wurth_WE-MAIA-1610; Part Number 78438313015
Q1401: DMN21D2UFB-7B; DMN21D2UFB7B; Mouser Part Number 621-DMN21D2UFB-7B
Q1402: DMP21D0UFB-7B; DMP21D0UFB7B; Mouser Part Number 621-DMP21D0UFB-7B
R1401, R1403: 4k7; R_0402
R1402: 10k; R_0402; not fitted
R1404: 4k7; R_0402; not fitted
R1405: 180k; R_0402
R1406: 360k; R_0402
R1407: 4k99; R_0402
R1408: 1k; R_0402
R1409: 47k; R_0402
TP1401, TP1402: 1.5mm; TestPoint_Pad_D1.5mm
U1401: TPS62290TDRVRQ1; SON65P200X200X80-7N; Mouser Part Number 595-TPS62290TDRVRQ1
U1402: 88Q2112-A2-NYD2A000-P123; 88Q2112

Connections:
+1V8: C1409.1, C1411.1, C1412.1, C1413.1, C1415.1, C1417.1, C1419.1, C1421.1, R1402.2, U1402.9 (AVDD18), U1402.24 (VDDO), U1402.33 (AVDD18), U1402.40 (VDDO); also elsewhere on the board
+3V3: C1401.1, C1402.1, C1408.1, C1410.1, U1401.2 (MODE), U1401.5 (VIN), U1402.6 (AVDD33); also elsewhere on the board
+3V3_AON: C1414.1, Q1402.2 (S), R1409.2, U1402.46 (VLPR); also elsewhere on the board
/CDNs & PoDL/MDI1_IN.TRXN: U1402.5 (MDIN); also elsewhere on the board
/CDNs & PoDL/MDI1_IN.TRXP: U1402.4 (MDIP); also elsewhere on the board
/PHYs/1000BASE-T1 PHY 0/INH: Q1402.3 (D), U1401.4 (EN); also elsewhere on the board
/PHYs/1000BASE-T1 PHY 0/MDC: U1402.38 (MDC); also elsewhere on the board
/PHYs/1000BASE-T1 PHY 0/MDIO: U1402.39 (MDIO); also elsewhere on the board
/PHYs/1000BASE-T1 PHY 0/~RST: U1402.36 (~RST); also elsewhere on the board
/PHYs/1000BASE-T1 PHY 1/0V9: C1403.1, C1405.1, C1406.1, C1407.1, C1416.1, C1418.1, C1420.1, L1401.2, R1405.1, TP1401.1 (1_1), U1402.17 (DVDD), U1402.43 (DVDD)
/PHYs/1000BASE-T1 PHY 1/CLKIN: C1404.2; also elsewhere on the board
/PHYs/1000BASE-T1 PHY 1/FB: C1403.2, R1405.2, R1406.1, U1401.3 (FB)
/PHYs/1000BASE-T1 PHY 1/GPIO: U1402.42 (GPIO/PHYAD2)
/PHYs/1000BASE-T1 PHY 1/INH_G: Q1401.1 (G), R1408.1
/PHYs/1000BASE-T1 PHY 1/INH_OUT: R1408.2, U1402.45 (INH)
/PHYs/1000BASE-T1 PHY 1/RSET: R1407.2, U1402.1 (RSET)
/PHYs/1000BASE-T1 PHY 1/SW: L1401.1, U1401.1 (SW)
/PHYs/1000BASE-T1 PHY 1/XTAL_IN: C1404.1, U1402.12 (XTAL_IN)
/PHYs/1000BASE-T1 PHY 1/~INH: Q1401.3 (D), Q1402.1 (G), R1409.1
/PHYs/WAKE: U1402.44 (WAKE_IN); also elsewhere on the board
/PHYs/xMII1.RX_CLK: U1402.23 (RCLK); also elsewhere on the board
/PHYs/xMII1.RX_CTL: R1401.2, U1402.22 (RXC); also elsewhere on the board
/PHYs/xMII1.RX_D0: R1403.2, U1402.21 (RXD0/PHYAD0); also elsewhere on the board
/PHYs/xMII1.RX_D1: U1402.20 (RXD1/PHYAD1); also elsewhere on the board
/PHYs/xMII1.RX_D2: U1402.19 (RXD2/MODE0); also elsewhere on the board
/PHYs/xMII1.RX_D3: U1402.18 (RXD3/MODE1); also elsewhere on the board
/PHYs/xMII1.TX_CLK: U1402.25 (TCLK); also elsewhere on the board
/PHYs/xMII1.TX_CTL: U1402.26 (TXC); also elsewhere on the board
/PHYs/xMII1.TX_D0: U1402.27 (TXD0); also elsewhere on the board
/PHYs/xMII1.TX_D1: U1402.28 (TXD1); also elsewhere on the board
/PHYs/xMII1.TX_D2: U1402.29 (TXD2); also elsewhere on the board
/PHYs/xMII1.TX_D3: U1402.30 (TXD3); also elsewhere on the board
/PHYs/~PHY1_INT: U1402.37 (~INT); also elsewhere on the board
GND1: C1401.2, C1402.2, C1405.2, C1406.2, C1407.2, C1408.2, C1409.2, C1410.2, C1411.2, C1412.2, C1413.2, C1414.2, C1415.2, C1416.2, C1417.2, C1418.2, C1419.2, C1420.2, C1421.2, C1422.2, Q1401.2 (S), R1401.1, R1403.1, R1404.1, R1406.2, R1407.1, TP1402.1 (1_1), U1401.6 (GND), U1401.7 (EP), U1402.11 (VSSC), U1402.49 (VSS); also elsewhere on the board

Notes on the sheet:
Internal GPIO pullups needed for ~{INT}.
AVDD18: 145mA Typ 152mA Max
RSET Must be 1% tolerance
Use high quality, low ESR (<50mΩ) capacitors such as GRM155R61A475ME02
Populating strapping pulldowns means that bit of the PHY address or mode will be 1.
AVDD33: 25mA Typ 27mA Max
VDDO: 18.6mA Typ
DVDD: 202mA Typ 359mA Max
This INH circuit is non-standard, and requires testing.
MODE[1:0] = 0x00 means the PHY will start as a 100BASE-T1 master, 0x01 means 100BASE-T1 slave.
Maximum allowed noise on any supply is 50mV peak to peak

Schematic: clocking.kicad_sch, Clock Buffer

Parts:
C1201: 1u; C_0402
C1202: 100n; C_0402
R1201: 47k; R_0402
R1202, R1203, R1204: 22R; R_0402
TP1201: 1.5mm; TestPoint_Pad_D1.5mm
U1201: LMK1C1104DQFR; SON50P200X200X80-8N; Mouser Part Number 595-LMK1C1104DQFR

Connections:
+1V8: C1201.1, C1202.1, R1201.2, U1201.6 (VDD); also elsewhere on the board
/PHYs/1000BASE-T1 PHY 0/CLKIN: R1203.2; also elsewhere on the board
/PHYs/1000BASE-T1 PHY 1/CLKIN: R1204.2; also elsewhere on the board
/PHYs/1000BASE-T1 PHY 2/CLKIN: R1202.2; also elsewhere on the board
/PHYs/CLK_EN: R1201.1, U1201.2 (1G); also elsewhere on the board
/PHYs/CLK_IN: U1201.1 (CLKIN); also elsewhere on the board
/PHYs/Clocking/Y1: R1202.1, U1201.8 (Y1)
/PHYs/Clocking/Y2: R1203.1, U1201.5 (Y2)
/PHYs/Clocking/Y3: R1204.1, U1201.7 (Y3)
GND1: C1201.2, C1202.2, TP1201.1 (1_1), U1201.4 (GND); also elsewhere on the board

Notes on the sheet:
Source termination (place close to buffer)

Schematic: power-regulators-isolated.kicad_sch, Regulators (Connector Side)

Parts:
C701: 10u; C_0805; Voltage 50V
C702, C703, C704, C706, C711: 1u; C_0402
C705: 100n; C_0402
C707, C708, C709, C710, C712: 4u7; C_0402
L701: 74438323047; L_Wurth_WE-MAPI-2510; Part Number 74438323047
R701: 180k; R_0402
R702: 33k; R_0402
TP701, TP702: 1.5mm; TestPoint_Pad_D1.5mm
U701: TPS7B8133QDRVRQ1; SON65P200X200X80-7N; Mouser Part Number 595-TPS7B8133QDRVRQ1
U702: MAX20075DATCA/V+; SON50P300X300X80-13N
U703: NCP508MT25TBG

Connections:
+2V5_ISO: C711.1, U703.1 (VOUT); also elsewhere on the board
+3V3_ISO: C704.1, C706.1, TP701.1 (1_1), U701.6 (OUT), U703.6 (VIN); also elsewhere on the board
+6V5_ISO: C702.1, C707.1, C708.1, C709.1, C710.1, C712.1, L701.2 (w2), R701.2, TP702.1 (1_1), U701.1 (IN), U701.2 (EN), U702.9 (OUT); also elsewhere on the board
+VIN_ISO: C701.1, U702.2 (EN), U702.4 (SUP); also elsewhere on the board
/Power/2V5_ISO_EN: U703.4 (EN); also elsewhere on the board
/Power/3V3_ISO_MODE: U702.11 (SYNC); also elsewhere on the board
/Power/Regulators (Isolated)/BIAS: C703.1, U702.1 (SPS), U702.10 (BIAS)
/Power/Regulators (Isolated)/BST: C705.1, U702.3 (BST)
/Power/Regulators (Isolated)/FB: R701.1, R702.2, U702.8 (FB)
/Power/Regulators (Isolated)/LX: C705.2, L701.1, U702.5 (LX)
GND2: C701.2, C702.2, C703.2, C704.2, C706.2, C707.2, C708.2, C709.2, C710.2, C711.2, C712.2, R702.1, U701.3 (GND), U701.4 (GND), U701.7 (EP), U702.6 (PGND), U702.7 (AGND), U702.13 (GND), U703.3 (GND); also elsewhere on the board

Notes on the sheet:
2V5 Regulator
6V5 Regulator
3V3 Regulator
SYNC (MODE): - HIGH = FPWM (low ripple) - LOW = Skip (low power) (default)
Use high quality, low ESR (<50mΩ) capacitors such as GRM155R61A475ME02
Vout = 6.45V [6.25V ... 6.66V]

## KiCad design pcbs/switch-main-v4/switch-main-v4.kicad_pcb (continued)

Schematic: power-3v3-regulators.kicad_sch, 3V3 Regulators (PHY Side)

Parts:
C401, C402: 10u; C_0805; Voltage 50V
C403: 1u; C_0402; Voltage 50V
C404, C405: 1u; C_0402
C406, C407, C408, C409, C410, C411, C412, C413, C414, C415: 4u7; C_0402
L401: 74438323022; L_Wurth_WE-MAPI-2510; Part Number 74438323022
R401, R402: 10k; R_0402
R403: 100k; R_0402
TP401, TP402, TP806: 1.5mm; TestPoint_Pad_D1.5mm
U401: TPS7B8133QDRVRQ1; SON65P200X200X80-7N; Mouser Part Number 595-TPS7B8133QDRVRQ1
U402: LMQ66420MC3RXBRQ1; LMQ664x0
U403: TPS2116DRL; SOTFL50P160X60-8N

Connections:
+3V3: C406.1, C407.1, C408.1, C409.1, C410.1, C411.1, C412.1, C413.1, C414.1, C415.1, L401.2, R403.2, TP402.1 (1_1), TP806.1 (1_1), U402.11 (VOUT/FB), U403.3 (VIN1), U403.5 (MODE); also elsewhere on the board
+3V3_AON: TP401.1 (1_1), U403.2 (VOUT), U403.7 (VOUT); also elsewhere on the board
+VIN: C401.1, C402.1, C403.1, U401.1 (IN), U401.2 (EN), U402.3 (VIN); also elsewhere on the board
/PHYs/1000BASE-T1 PHY 0/INH: R401.1, U402.1 (EN/UVLO); also elsewhere on the board
/Power/3V3 Regulators/3V3_AON_RAW: C405.1, U401.6 (OUT), U403.6 (VIN2)
/Power/3V3 Regulators/3V3_PG: R403.1, U402.14 (PG), U403.4 (PR1)
/Power/3V3 Regulators/SW: L401.1, U402.7 (SW)
/Power/3V3 Regulators/VCC: C404.1, U402.10 (VCC)
/Power/3V3_AON_ST: U403.8 (ST); also elsewhere on the board
/Power/3V3_MODE: R402.1, U402.13 (MODE/SYNC); also elsewhere on the board
GND1: C401.2, C402.2, C403.2, C404.2, C405.2, C406.2, C407.2, C408.2, C409.2, C410.2, C411.2, C412.2, C413.2, C414.2, C415.2, R401.2, R402.2, U401.3 (GND), U401.4 (GND), U401.7 (EP), U402.6 (PGND), U402.15 (GND/DAP), U403.1 (GND); also elsewhere on the board

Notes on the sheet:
3V3 Always on supply
3V3 Main Regulator
PR1 > 1V => VOUT = VIN1 PR1 < 1V => VOUT = VIN2
EN is set high by PHY INH outputs
Use high quality, low ESR (<50mΩ) capacitors such as GRM155R61A475ME02
2A Max
3V3_AON switchover to use most efficient supply.
MODE is auto by default. Setting MODE high means a lower output ripple which is necessary for the ethernet PHYs.
3V3_AON_ST Needs an MCU internal pullup
150mA Max

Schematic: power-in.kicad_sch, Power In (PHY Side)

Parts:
C301: 100n; C_0603; Voltage 100V
D301: SZESD7241N2T5G; SZESD7462N2T5G; Mouser Part Number 863-SZESD7241N2T5G
J301: MKXS1-1 Power Input; 10132797-031100LF
R301: 120k; R_0402
R302: 10k; R_0402
R303: 4k7; R_0402
R304: 47k; R_0402
R305, R306, R307: 100k; R_0402
R309: 5k6; R_0402
U301: TVS3301DRBR; SON65P300X300X100-9N-D
U302: TPS26600RHFR; QFN50P400X500X100-25N-D; Mouser Part Number 595-TPS26601RHFR

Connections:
+VIN: R307.2, U302.23 (OUT_1), U302.24 (OUT_2); also elsewhere on the board
/Power/Power In/EFUSE_IMON: R305.2, R306.2, U302.18 (IMON)
/Power/Power In/ILIM: R304.2, U302.19 (ILIM)
/Power/Power In/OVP: R302.2, R303.1, U302.12 (OVP)
/Power/Power In/RTN: R303.2, R304.1, R305.1, U302.15 (RTN), U302.25 (EP)
/Power/Power In/UVLO: R301.2, R302.1, U302.10 (UVLO)
/Power/Power In/VIN_RAW: C301.2, D301.2 (A2), J301.1 (V+), J301.2 (V+), J301.3 (V+), J301.4 (V+), J301.5 (V+), J301.6 (V+), J301.25 (V+), J301.26 (V+), J301.27 (V+), J301.28 (V+), J301.29 (V+), J301.30 (V+), R301.1, U301.1 (IN), U301.2 (IN), U301.3 (IN), U301.4 (IN), U302.8 (IN_1), U302.9 (IN_2)
/Power/Power In/~FLT: U302.22 (~FLT)
/Power/VIN_IMON: R306.1; also elsewhere on the board
/Power/VIN_VMON: R307.1, R309.2; also elsewhere on the board
GND1: C301.1, D301.1 (A1), J301.7 (V-), J301.8 (V-), J301.9 (V-), J301.10 (V-), J301.11 (V-), J301.12 (V-), J301.19 (V-), J301.20 (V-), J301.21 (V-), J301.22 (V-), J301.23 (V-), J301.24 (V-), J301.MP1 (MP), J301.MP2 (MP), R309.1, U301.5 (GND), U301.6 (GND), U301.7 (GND), U301.8 (GND), U302.17 (GND); also elsewhere on the board

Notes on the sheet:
ESD Protection
Surge Protection
UVLO = 10.9V OVP = 34.1V
I_{OUT} = V_{IMON} / 7.84
VMON = VIN / 18.857 The 150mΩ eFuse resistance should be taken into account when calculating input power.
R_{ILIM} = 47kΩ ∴ I_{LIM} = 255mA
eFuse
TPS26600 has auto-retry when a fault occurs.

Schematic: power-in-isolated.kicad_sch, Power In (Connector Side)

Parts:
C601: 100n; C_0603; Voltage 100V
D601: SZESD7241N2T5G; SZESD7462N2T5G; Mouser Part Number 863-SZESD7241N2T5G
J601: MKXS1-1 Power Input; 10132797-031100LF
R601: 120k; R_0402
R602: 10k; R_0402
R603: 4k7; R_0402
R604, R608: 5k6; R_0402
R605: 15k; R_0402
R606, R607: 100k; R_0402
U601: TVS3301DRBR; SON65P300X300X100-9N-D
U602: TPS26600RHFR; QFN50P400X500X100-25N-D; Mouser Part Number 595-TPS26601RHFR

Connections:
+VIN_ISO: R607.2, U602.23 (OUT_1), U602.24 (OUT_2); also elsewhere on the board
/Power/Power In (Isolated)/EFUSE_IMON: R605.2, R606.2, U602.18 (IMON)
/Power/Power In (Isolated)/ILIM: R604.2, U602.19 (ILIM)
/Power/Power In (Isolated)/OVP: R602.2, R603.1, U602.12 (OVP)
/Power/Power In (Isolated)/RTN: R603.2, R604.1, R605.1, U602.15 (RTN), U602.25 (EP)
/Power/Power In (Isolated)/UVLO: R601.2, R602.1, U602.10 (UVLO)
/Power/Power In (Isolated)/VIN_RAW: C601.2, D601.2 (A2), J601.1 (V+), J601.2 (V+), J601.3 (V+), J601.4 (V+), J601.5 (V+), J601.6 (V+), J601.25 (V+), J601.26 (V+), J601.27 (V+), J601.28 (V+), J601.29 (V+), J601.30 (V+), R601.1, U601.1 (IN), U601.2 (IN), U601.3 (IN), U601.4 (IN), U602.8 (IN_1), U602.9 (IN_2)
/Power/Power In (Isolated)/~FLT: U602.22 (~FLT)
/Power/VIN_ISO_IMON: R606.1; also elsewhere on the board
/Power/VIN_ISO_VMON: R607.1, R608.2; also elsewhere on the board
GND2: C601.1, D601.1 (A1), J601.7 (V-), J601.8 (V-), J601.9 (V-), J601.10 (V-), J601.11 (V-), J601.12 (V-), J601.19 (V-), J601.20 (V-), J601.21 (V-), J601.22 (V-), J601.23 (V-), J601.24 (V-), J601.MP1 (MP), J601.MP2 (MP), R608.1, U601.5 (GND), U601.6 (GND), U601.7 (GND), U601.8 (GND), U602.17 (GND); also elsewhere on the board

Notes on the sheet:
eFuse
Surge Protection
I_{OUT} = V_{IMON} / 1.125 Can be done with integers: I_{OUT} = (V_{IMON} << 3) / 9
UVLO = 10.9V OVP = 34.1V
VMON = VIN_ISO / 18.857 The 150mΩ eFuse resistance should be taken into account when calculating input power.
TPS26600 has auto-retry when a fault occurs.
R_{ILIM} = 5k6Ω ∴ I_{LIM} = 2143mA
ESD Protection

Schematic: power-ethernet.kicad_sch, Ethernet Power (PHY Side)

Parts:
C501, C502, C503, C504, C505, C506, C509, C510, C511, C512, C513, C514: 4u7; C_0402
C507, C508: 22p; C_0402
L501, L502: 78438313015; L_Wurth_WE-MAIA-1610; Part Number 78438313015
R501: 360k; R_0402
R502, R503, R504: 180k; R_0402
TP501, TP502, TP504, TP505: 1.5mm; TestPoint_Pad_D1.5mm
U501, U502: TPS62290TDRVRQ1; SON65P200X200X80-7N; Mouser Part Number 595-TPS62290TDRVRQ1

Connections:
+1V2: C508.1, C510.1, C512.1, C514.1, L502.2, R503.1, TP502.1 (1_1), TP504.1 (1_1); also elsewhere on the board
+1V8: C507.1, C509.1, C511.1, C513.1, L501.2, R501.1, TP501.1 (1_1), TP505.1 (1_1); also elsewhere on the board
+3V3: C501.1, C502.1, C503.1, C504.1, C505.1, C506.1, U501.4 (EN), U501.5 (VIN), U502.4 (EN), U502.5 (VIN); also elsewhere on the board
/Power/Ethernet Power/FB_1V2: C508.2, R503.2, R504.1, U502.3 (FB)
/Power/Ethernet Power/FB_1V8: C507.2, R501.2, R502.1, U501.3 (FB)
/Power/Ethernet Power/SW_1V2: L502.1, U502.1 (SW)
/Power/Ethernet Power/SW_1V8: L501.1, U501.1 (SW)
GND1: C501.2, C502.2, C503.2, C504.2, C505.2, C506.2, C509.2, C510.2, C511.2, C512.2, C513.2, C514.2, R502.2, R504.2, U501.2 (MODE), U501.6 (GND), U501.7 (EP), U502.2 (MODE), U502.6 (GND), U502.7 (EP); also elsewhere on the board

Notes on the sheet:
1V8 Regulator
1V2 Regulator
Use high quality, low ESR (<50mΩ) capacitors such as GRM155R61A475ME02

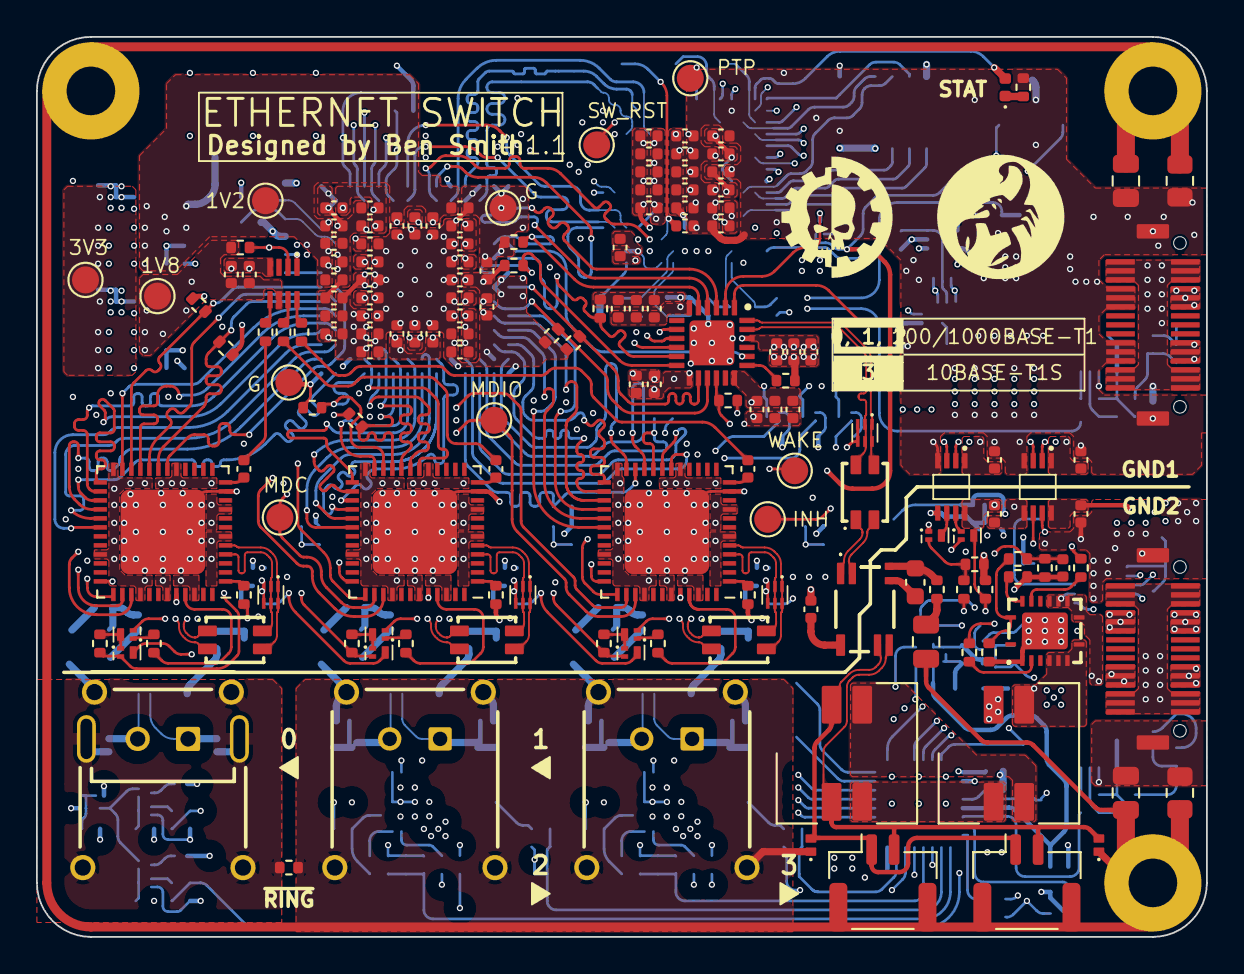
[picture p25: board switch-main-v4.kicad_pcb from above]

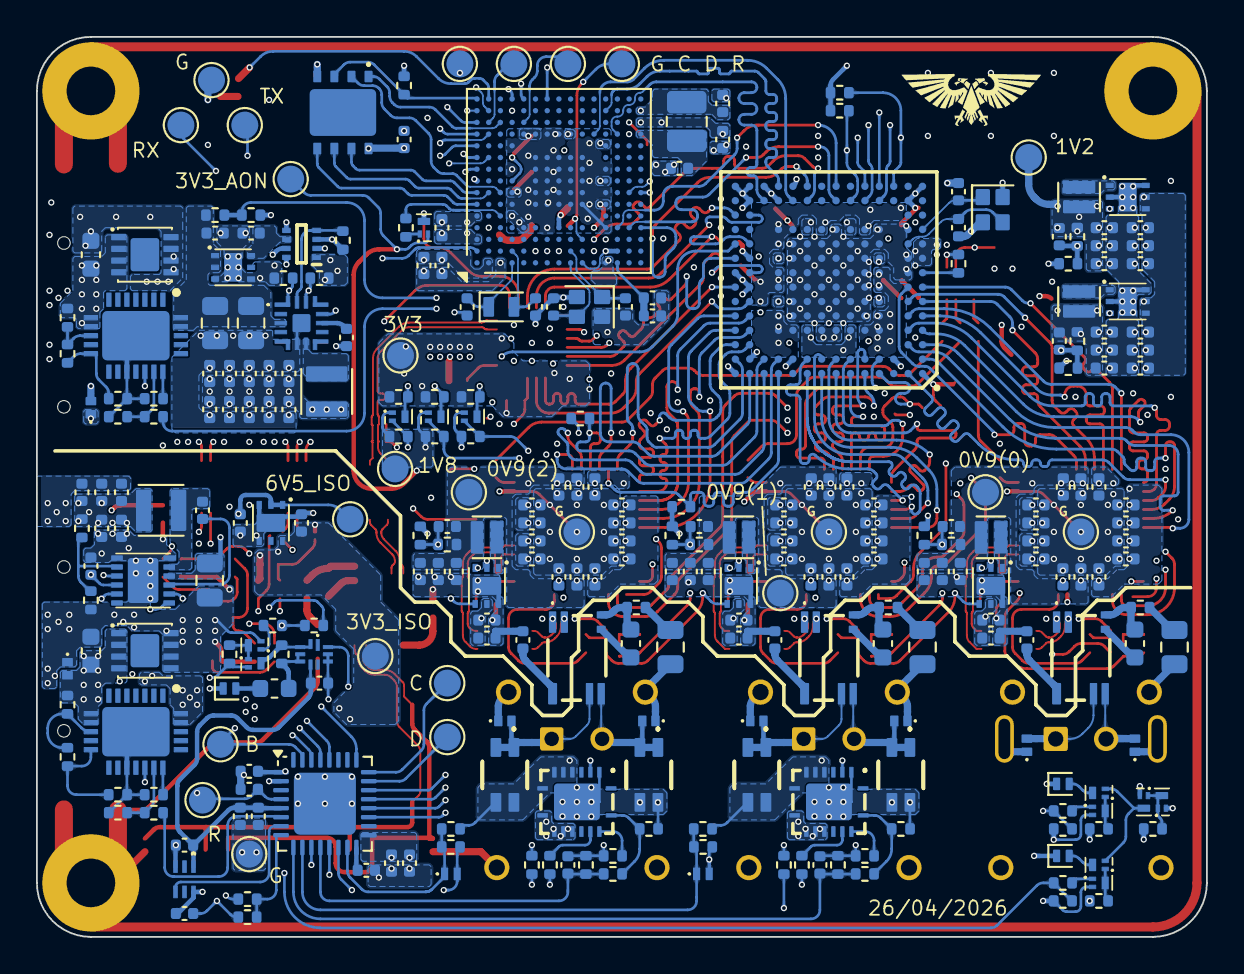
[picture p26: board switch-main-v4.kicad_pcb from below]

Board: 6 copper layers, 65.0 x 50.0 mm, 468 parts (301 on the bottom side), 267 nets.

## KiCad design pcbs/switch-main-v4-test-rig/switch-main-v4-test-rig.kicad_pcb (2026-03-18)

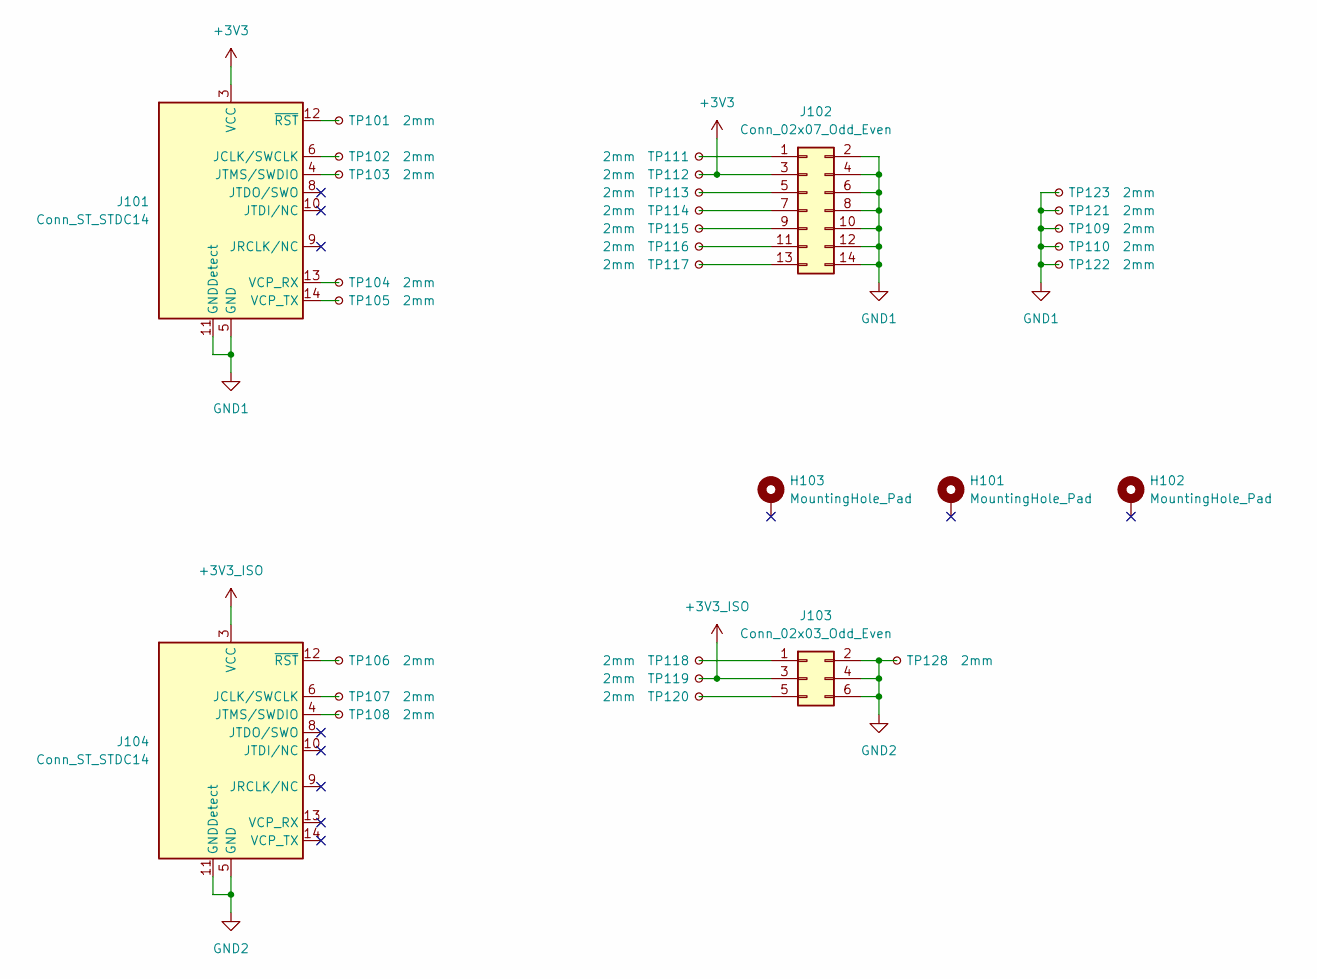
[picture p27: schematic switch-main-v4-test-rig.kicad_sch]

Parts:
H101, H102, H103: MountingHole_Pad; MountingHole_2.7mm_M2.5_DIN965_Pad
J101, J104: Conn_ST_STDC14; PinHeader_2x07_P1.27mm_Vertical_SMD
J102: Conn_02x07_Odd_Even; PinHeader_2x07_P2.54mm_Vertical
J103: Conn_02x03_Odd_Even; PinHeader_2x03_P2.54mm_Vertical
TP101, TP102, TP103, TP104, TP105, TP106, TP107, TP108, TP109, TP110, TP111, TP112, TP113, TP114, TP115, TP116, TP117, TP118, TP119, TP120, TP121, TP122, TP123, TP128: 2mm; TestPoint_Pad_D2.0mm

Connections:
+3V3: J101.3 (VCC), J102.3, TP112.1
+3V3_ISO: J103.3, J104.3 (VCC), TP119.1
GND1: J101.5 (GND), J101.7 (GND), J101.11 (GNDDetect), J102.2, J102.4, J102.6, J102.8, J102.10, J102.12, J102.14, TP109.1, TP110.1, TP121.1, TP122.1, TP123.1
GND2: J103.2, J103.4, J103.6, J104.5 (GND), J104.7 (GND), J104.11 (GNDDetect), TP128.1
unnamed: J101.6 (JCLK/SWCLK), TP102.1
unnamed: J101.4 (JTMS/SWDIO), TP103.1
unnamed: J101.13 (VCP_RX), TP104.1
unnamed: J101.14 (VCP_TX), TP105.1
unnamed: J101.12 (~RST), TP101.1
unnamed: J102.1, TP111.1
unnamed: J102.5, TP113.1
unnamed: J102.7, TP114.1
unnamed: J102.9, TP115.1
unnamed: J102.11, TP116.1
unnamed: J102.13, TP117.1
unnamed: J103.1, TP118.1
unnamed: J103.5, TP120.1
unnamed: J104.6 (JCLK/SWCLK), TP107.1
unnamed: J104.4 (JTMS/SWDIO), TP108.1
unnamed: J104.12 (~RST), TP106.1

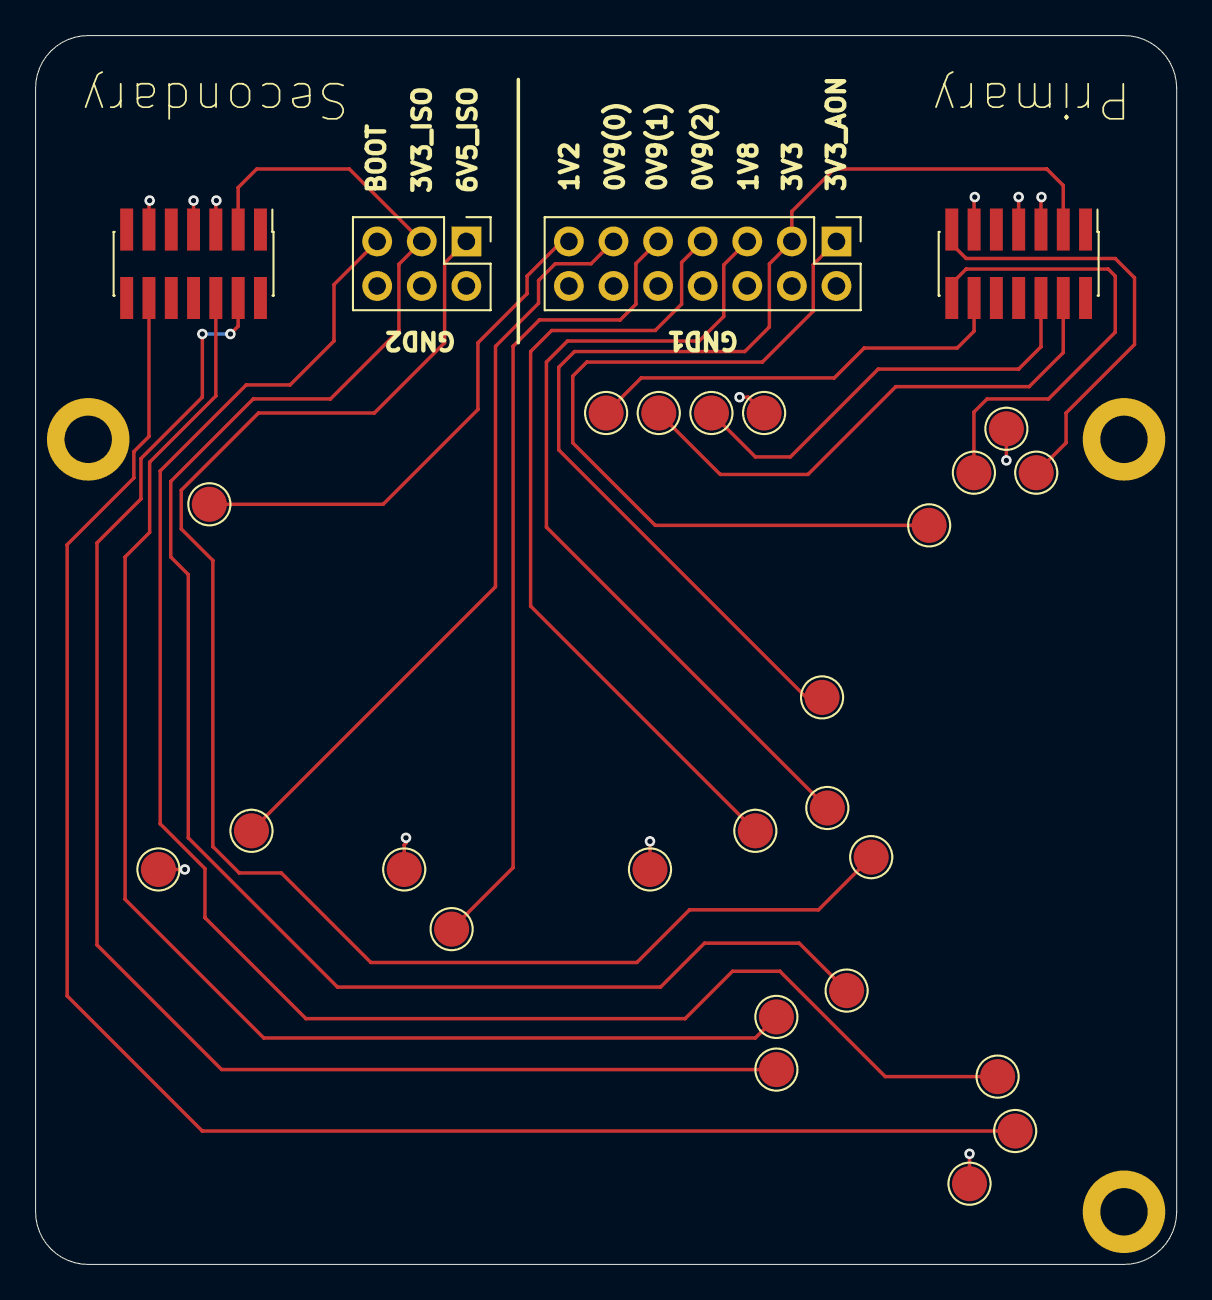
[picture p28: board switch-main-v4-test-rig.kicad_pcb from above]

Board: 2 copper layers, 65.0 x 70.0 mm, 31 parts (0 on the bottom side), 20 nets.

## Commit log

2025-10-06 Fixed mistake where RMII TX and RX signals were swapped
    [1000base-t1-phy-0.kicad_sch, 1000base-t1-phy-1.kicad_sch, 1000base-t1-phy-2.kicad_sch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]
2025-10-09 Added test rig
    [switch_main_v4_test_rig.kicad_pcb, switch_main_v4_test_rig.kicad_sch]
2025-11-01 Updated power connector model
    [power-in-isolated.kicad_sch, power-in.kicad_sch, switch_main_v4.kicad_pcb]
2025-11-17 Added NC to unused secondary MCU pin
    [secondary-mcu.kicad_sch]
2025-11-30 Removed old lint warning from schematic
    [primary-mcu.kicad_sch]
2025-12-25 Fixed typo in input current limit
    [power-in.kicad_sch]
2026-03-18 Tidied up repository
    [1000base-t1-cdn.kicad_sch, 1000base-t1-phy-0.kicad_sch, 1000base-t1-phy-1.kicad_sch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]
2026-03-19 Added errata and test rig schematics
    [switch-main-v4-test-rig.kicad_pcb, switch-main-v4-test-rig.kicad_sch, switch_main_v4_test_rig.kicad_pcb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]
2026-04-25 Updated to Kicad v10
    [1000base-t1-cdn.kicad_sch, 1000base-t1-phy-0.kicad_sch, 1000base-t1-phy-1.kicad_sch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]
